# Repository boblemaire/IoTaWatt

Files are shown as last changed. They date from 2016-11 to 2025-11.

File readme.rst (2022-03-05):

=========================================
IoTaWatt WiFi Electricity Monitor Project
=========================================

IoTaWatt is an open-source, open hardware project to produce an accurate, 
inexpensive and easy to use energy monitor.  
It can use any of dozens of common current transformers and
will report the data locally via integrated web server,
or upload to any of several third-party energy websites/data bases.
Configuration and administration is through an easy to 
use browser based utility running on a 
computer, tablet or smartphone.

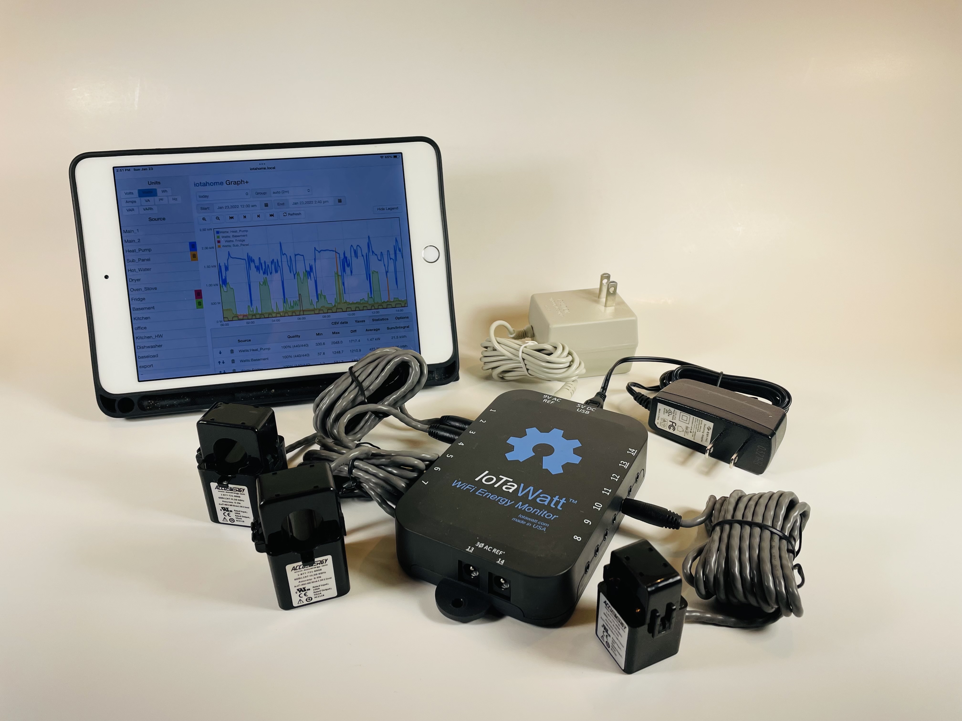
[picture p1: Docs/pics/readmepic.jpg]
**IoTaWatt USA Bundle**


    IoTaWatt North America Bundle with two CTs for Mains

IoTaWatt is a full function standalone energy monitor 
with the capability to store and serve up to 15 years (or more) 
of comprehensive usage data and has an integrated web-server with
visualization apps. 
At the same time it can upload data to any and 
all of several (and counting) web based database and reporting systems.

Hardware is open and uses an ESP8266 nodeMCU,
MCP3208 12 bit ADCs, an RTC, and an SDcard.
The commercially manufactured unit is tested and certified to UL 
standards in the US and Canada, 
CE compliant, and FCC compliant and comes with a
custom enclosure and wall mount.

Metrics accumulated to 5 second resolution are Voltage(V), Power(Watts), 
Energy(kWh), VA, and PF.  While not certified to a standard, 
users typically report accuracy within 1% of their revenue meters.

With over 1,000 units sold worldwide over the past year, 
it's now starting to get the attention of energy professionals.

The software project is not commercial, 
however it was necessary to establish a legal entity (IoTaWatt, Inc.) 
in order to manufacture, certify, and sell the hardware worldwide.  
There is an investment in that 
infrastructure that needs to be recovered through sales. You can
visit the `IoTaWatt Stuff Store <https://stuff.iotawatt.com>`_ to get one. 

The unit is manufactured in the USA.

    *   `Documentation <https://iotawatt.readthedocs.io>`_
    *   `Project Website <https://iotawatt.com>`_
    *   `User Forum <https://community.iotawatt.com>`_

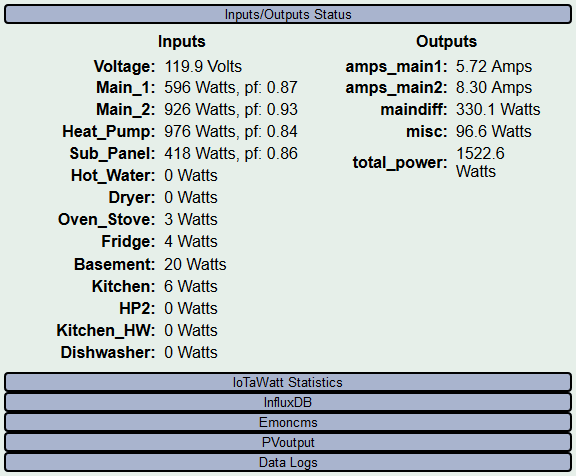
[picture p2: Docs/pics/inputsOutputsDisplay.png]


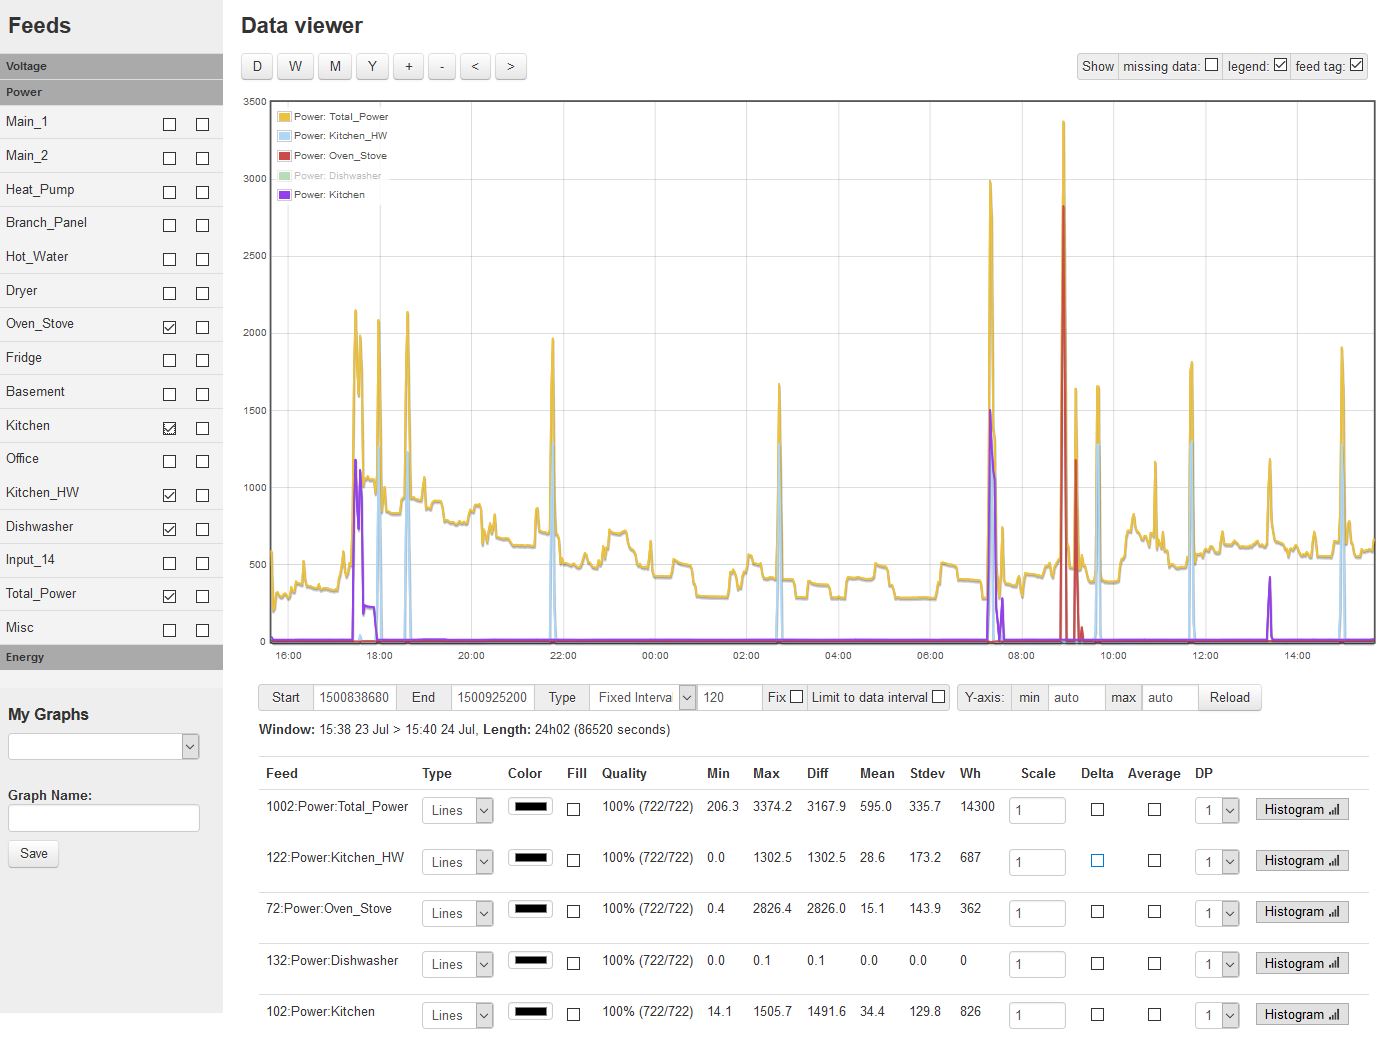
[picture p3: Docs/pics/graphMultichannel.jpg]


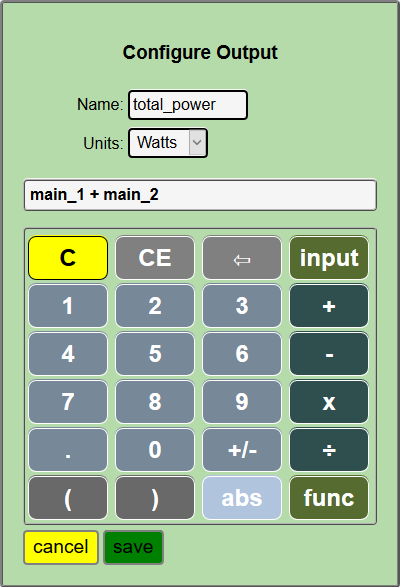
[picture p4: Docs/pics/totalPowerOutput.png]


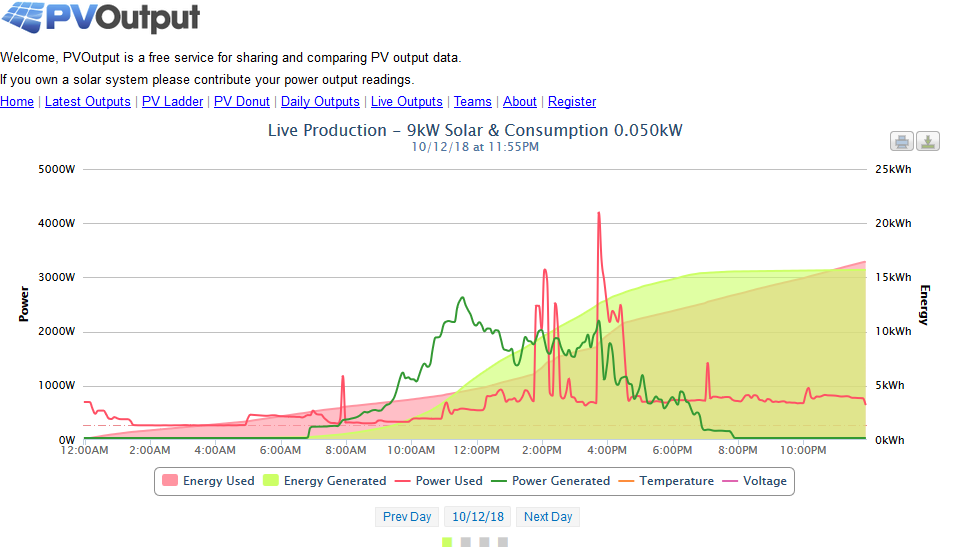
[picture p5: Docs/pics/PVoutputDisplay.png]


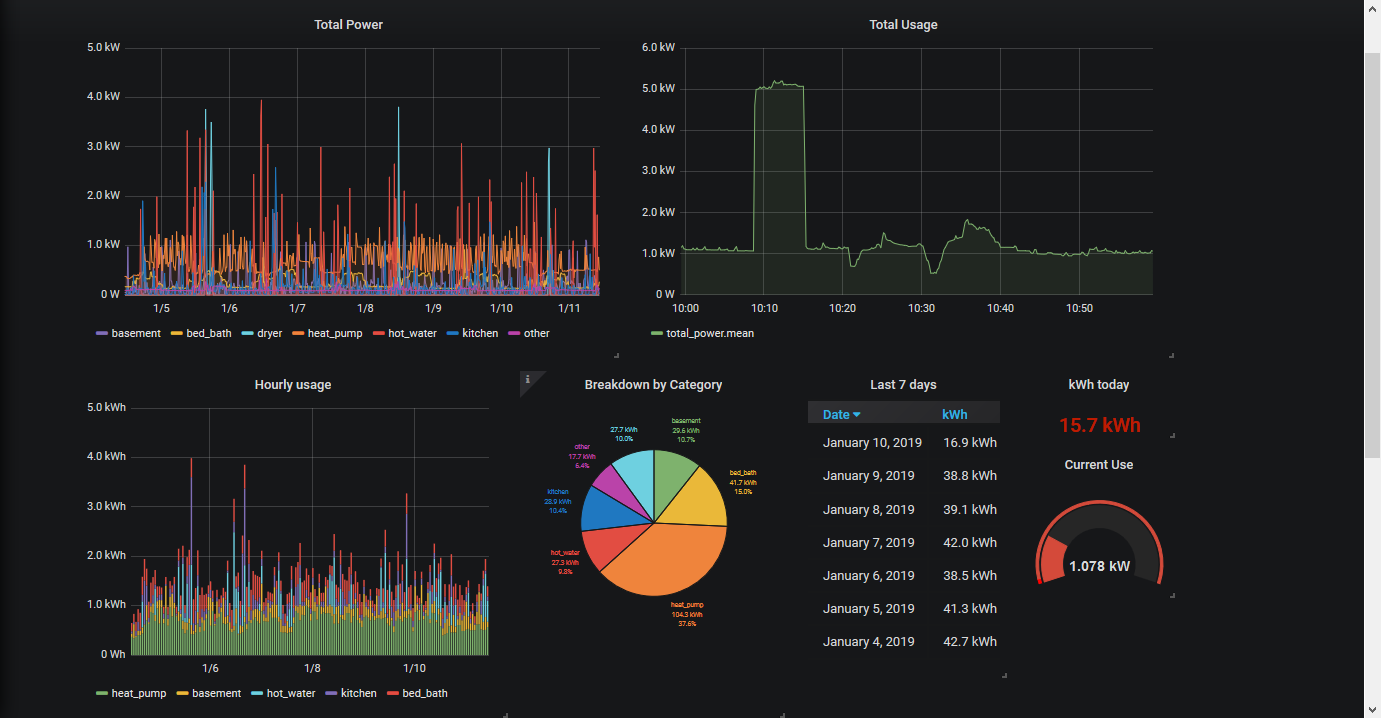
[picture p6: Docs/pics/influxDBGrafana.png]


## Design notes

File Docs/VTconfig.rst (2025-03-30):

=================================
Voltage Transformer Configuration
=================================

A prime component of electrical power is voltage.
The AC line frequency is the heartbeat of the IoTaWatt.
A reliable and accurate AC voltage reference is very important.
You should have installed the device with a 9 Volt AC voltage reference
transformer (VT) plugged into the channel zero power jack.
If your initial configuration has this channel pre-configured,
your LED will be glowing green because it's rhythmically sampling that voltage.

Various transformer models produce different voltages,
and it's important to ensure that the VT specified 
matches the model that you have installed.
To do this, select the inputs button in the Setup dropdown menu.

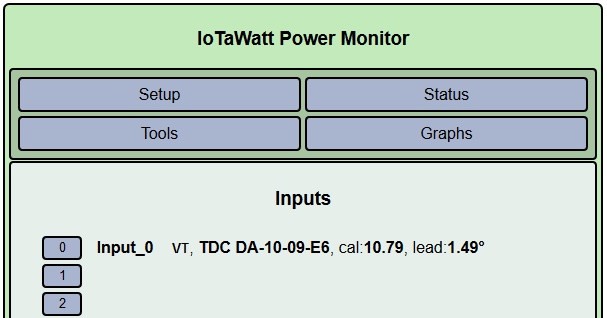
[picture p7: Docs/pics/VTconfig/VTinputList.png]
Setup Inputs List


A list of all of the inputs will be displayed.
The first entry will be input 0 and a default VT should be configured.
Check to see if it's the same as your VT model.
It's OK to unplug the VT to check the model number printed on it.

If your VT model doesn't match the model that is configured, you can easily change it.
Click on the input channel 0 button on the left.

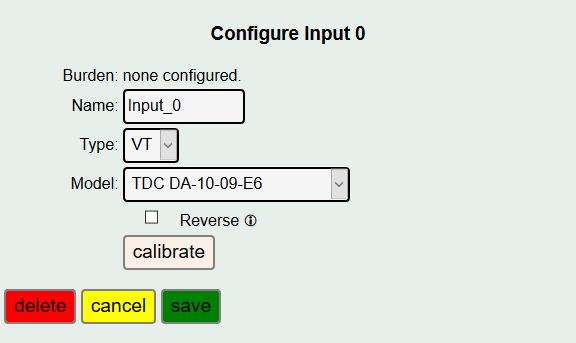
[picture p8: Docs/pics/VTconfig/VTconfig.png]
Configure VT Menu


As you can see, the display changes to reveal the details of the input_0 configuration.

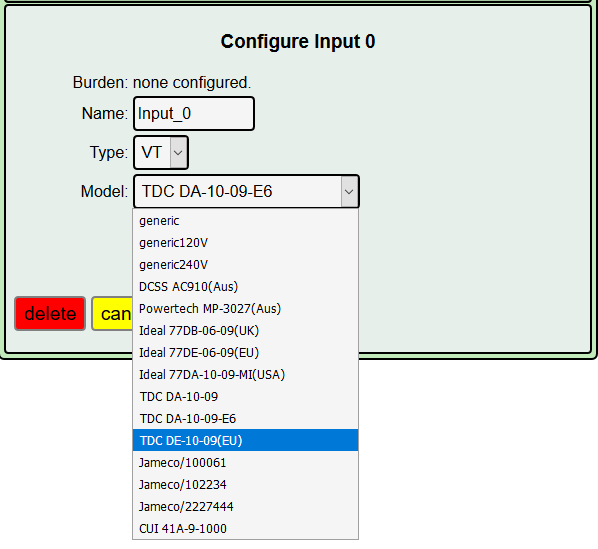
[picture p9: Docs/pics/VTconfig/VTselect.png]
Select VT Image


VT Model Selection
------------------
If your make and model is listed, select it from the list.
At this point, you can just click **Save** and the standard 
calibration for your VT will be used.
That calibration should be good for all but the most discerning users.
If you have access to a good voltmeter or other reliable 
high accuracy voltage reference,
you can fine tune with the calibration procedure below, but for average users,
you should be good to go on to the next step Adding Power Channel CTs

If your VT wasn't listed in the dropdown above,
the generic entry is a reasonable starting point 
that will get you in the ball park for your 9-12Vac adapter.
If your country is 230V or 240V select "generic240V". 
Now you must perform the `Voltage Calibration`_  procedure below.

TDC DA-10-09 model ambiguity
~~~~~~~~~~~~~~~~~~~~~~~~~~~~

There are two different voltage transformers available with the model designation TDC DA-10-09.
These models are quite different and need to be properly configured.

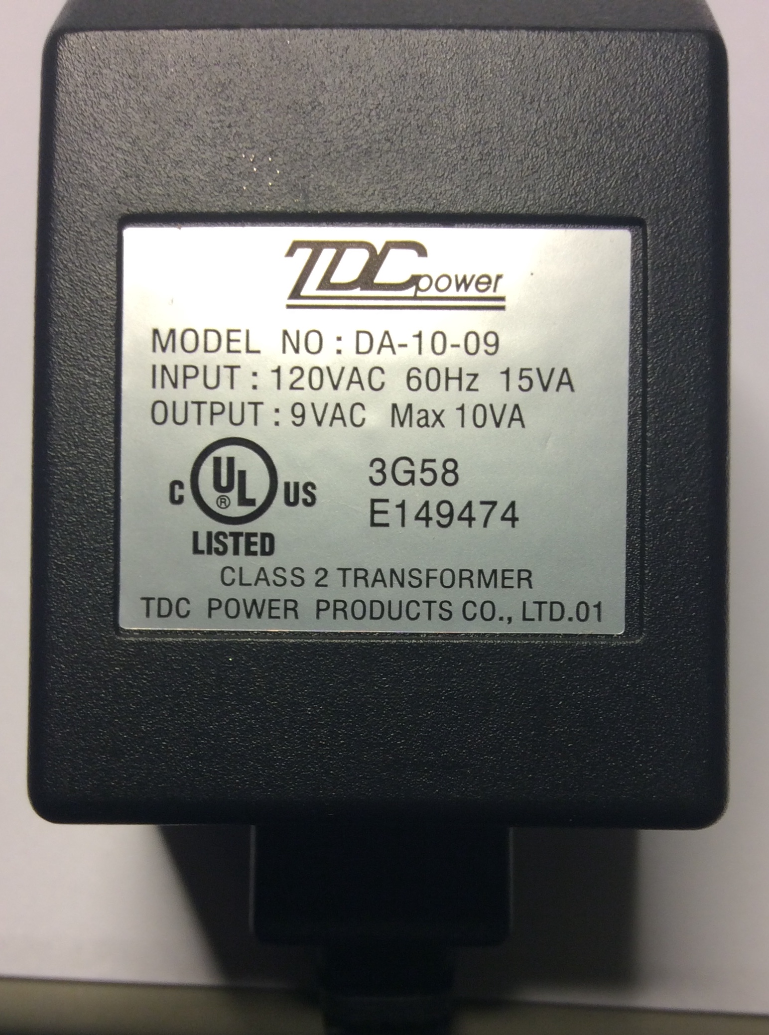
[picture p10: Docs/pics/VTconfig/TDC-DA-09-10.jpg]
TDC DA-10-09


    use model: TDC DA-10-09

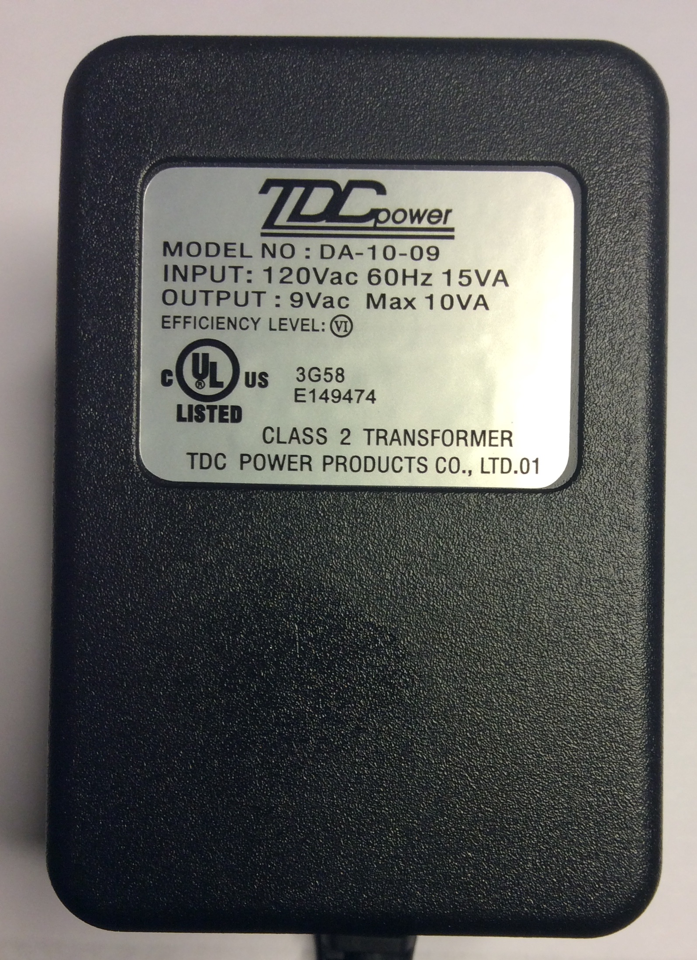
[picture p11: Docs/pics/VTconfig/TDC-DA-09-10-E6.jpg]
TDC DA-10-09-E6


    use model: TDC DA-10-09-E6

Voltage Calibration
-------------------

Again, if you are using one of the standard voltage transformers from
the tables, this step is optional. 
Repeated random tests on the standard US and
Euro transformers yield excellent calibration right out of the box.

You will need a halfway decent voltage reference for this step.
If you don't have a decent true RMS voltmeter and can't borrow one, 
go out and get a Kill-a-Watt.
They cost less than $20 (some libraries lend them out) and 
I've found their voltage readings are usually accurate.

click **Calibrate**

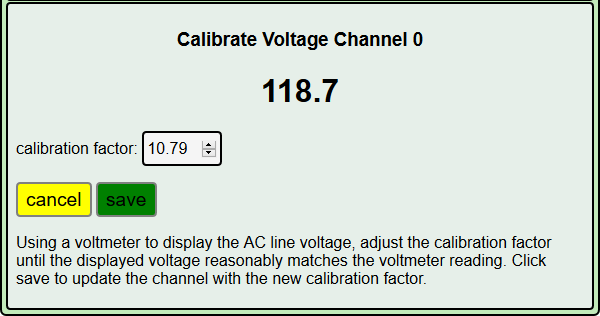
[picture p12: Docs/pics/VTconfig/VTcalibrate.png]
Calibrate VT Menu


Follow the instructions on the page. Increase or decrease the "cal" factor
until the voltage shown settles down and is a pretty 
good match with your reference meter.
It's not possible to match exactly. 0.2V in a 
120V installation is 0.2% variation.
A good meter accuracy is 1% at best. Just try to get the 
two to dwell around the same set of fractional digits.

As instructed on the page, click save to record the calibration factor.
The new calibration factor will take effect immediately.
Click the Status menu button to display the voltage:

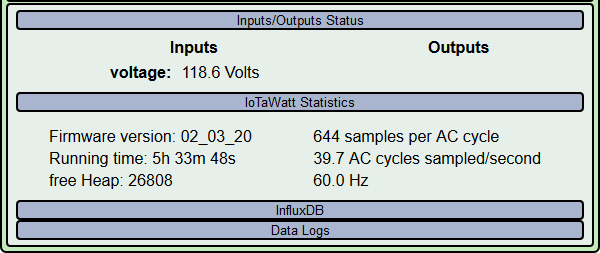
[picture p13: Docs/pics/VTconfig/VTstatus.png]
VT Status


Wait a few seconds then check that the voltage 
displayed is still in the ball park.
If not, repeat the calibration procedure.

Once calibration is complete and verified,
you will not need to do it again unless you change your VT transformer.
The IoTaWatt has a very accurate internal calibration reference and will maintain
its accuracy indefinitely. You should have no further need for the voltmeter.

Now the device is ready for the next 
step `Configuring Power Channel CTs <CTconfig.html>`_





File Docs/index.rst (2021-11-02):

======================
IoTaWatt documentation
======================

..  toctree::
    :maxdepth: 2
    :caption: Contents:

    Quickstart <quickstart>
    Installation <installation>
    Connecting to WiFi <connectWiFi>
    Device Configuration <devConfig>
    VT Configuration <VTconfig>
    CT Configuration <CTconfig>
    Status Display <status>
    Outputs <outputs.rst>
    Integrators <integrators>
    Uploaders <uploaders>
    Configure PVoutput <PVoutput>
    Configure Emoncms <Emoncms>
    Configure influxDB <influxDB>
    Home Assistant <homeAssistant>
    Setting up Passwords <passConfig>
    Three-phase power <threePhase>
    CT Basics <CTbasics>
    Split-phase power <split-phase.rst>
    Data Visualization <dataVisualization>
    Graph+ <graphPlus>
    Original Graph <originalGraph>
    File Manager and Editor <fileManager>
    Query API <query.rst>
    HTTPS Proxy Server <HTTPSproxy.rst>
    Message Log <messageLog>
    Troubleshooting <troubleshooting>
    Accessing iotawatt.local <dotlocal>

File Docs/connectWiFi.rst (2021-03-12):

==================
Connecting to WiFi
==================

Purpose
-------

When IoTaWatt powers up, it attempts to connect to the 
last WiFi network used.
A connection must be established to an internet connected network if the real
time clock is not set, or to run the configuration utility,
or if logging to an external server like Emoncms is desired.
*It is strongly recommended to connect the IoTaWatt to a WiFi network
with a reliable internet connection*.

If the power-up connection is successful, 
the LED will begin to glow dull green.
This indicates that the IoTaWatt has connected 
and is in normal operating mode.
At this point you can skip ahead to the next 
section `Device Configuration <devConfig.html>`__

New connection
--------------

If the IoTaWatt has never been connected to a WiFi network (new),
or the last used network is not available, the ESP8266 will enter
AP (Access Point) mode when powered-up (not on a software restart).
This state is indicated when the LED flashes the 
three color sequence RED-GREEN-GREEN.
It will broadcast an SSID recognizable by the 
prefix ``iota`` followed by a unique number.
Connect to it using a smartphone or tablet.  
Use the password ``IotaWatt`` (case sensitive).
If the device was previously configured and the 
device name was changed,
that new name will be the password required in this step.

After connecting, a page will be rendered with several choices.  Select ``Configure WiFi``.

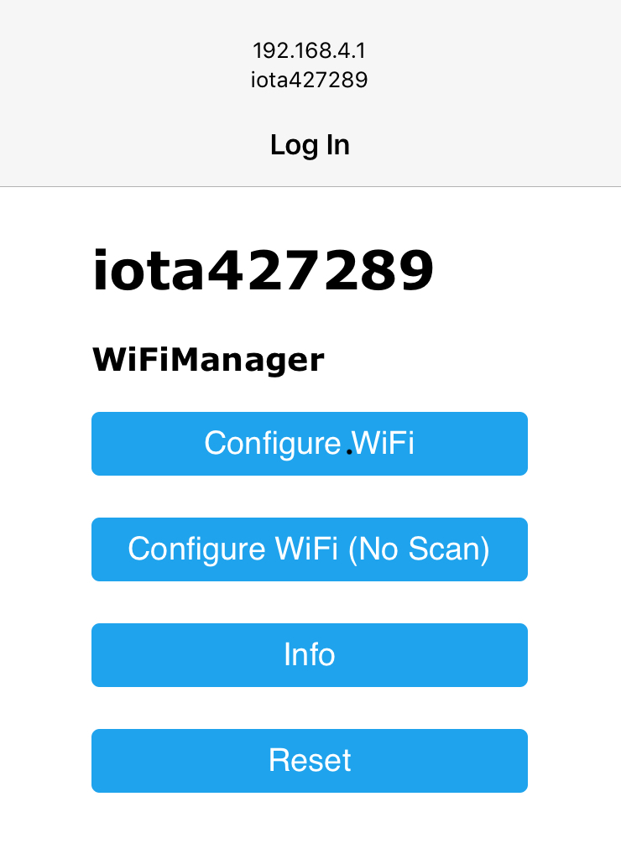
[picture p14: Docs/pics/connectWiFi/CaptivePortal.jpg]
captive portal image


A few seconds may elapse while the IoTaWatt scans for the local networks,
then another page will be rendered allowing you to select one of the listed
networks, or specify another network not listed.

Note that the IotaWatt only supports 2.4 GHz wireless networks. If you have a 5 GHz
only network you can either enable 2.4 GHz on it, or create a separate (optionally hidden)
network on 2.4 GHz for the IotaWatt to use.

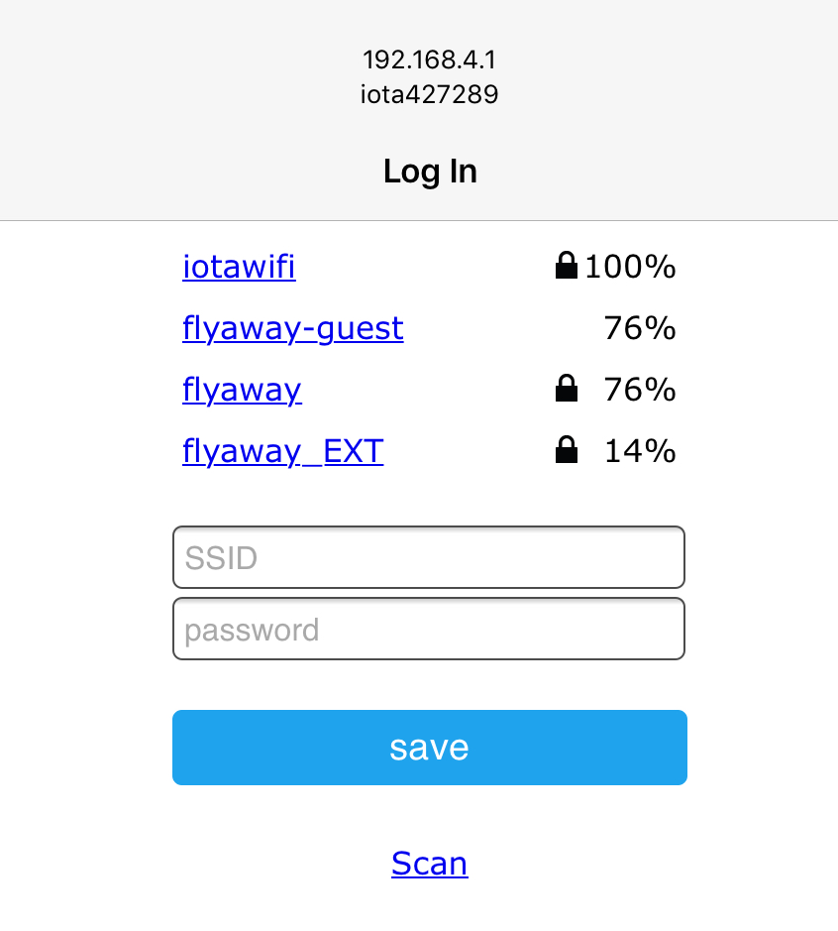
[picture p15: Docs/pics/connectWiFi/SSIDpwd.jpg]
Specify Network image


Select your network and enter the password, then save. Once connected,
the new WiFi network credentials will be saved and the device 
will continue it's
startup procedure.  If you see another LED sequence, refer to 
the `troubleshooting <troubleshooting.html>`__ section.

When the LED glows dull green, proceed to the next step
`Device Configuration  <devConfig.html>`__

Resetting WiFi to Defaults
--------------------------

If you wish to change the WiFi SSID that the IoTaWatt is connected to
(you might have done some testing and want to deploy 'live' somewhere where the SSID is different)
BEFORE moving the device you should reset the WiFi.

Using the configuration app go to ``Tools->WiFi``

Disconnect WiFi image

After the command to disconnect the existing WiFi connection has been sent, 
IoTaWatt will respond "ok" and the LED will change from a dull green to a dull red as the IoTaWatt disconnects,
indicating that the WiFi link has been severed.

Then power cycle the IoTaWatt. It should restart with the RED-GREEN-GREEN led sequence like a new
IoTaWatt ready to connect to the new SSID

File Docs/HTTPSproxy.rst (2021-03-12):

==================
HTTPS Proxy Server
==================

Like many IoT devices, IoTaWatt does not have the resources to communicate
over the internet using secure TLS. While the local LAN can be relatively secure,
data uploaded to internet based servers is transmitted in plaintext and
vulnerable.  One exception is the Emoncms web service where a protocol
to authenticate and encrypt communications is available.

Some external services, such as influxCloud, require TLS (HTTPS) be used
in all communications.  IoTaWatt can use a simple proxy server on the local
LAN to overcome this limitation and forward internet communications using HTTPS.

NGINX (engine-x) is an open-source web-server that can be hosted on a variety
of inexpensive processors.  The ubiquitous RaspberryPi being a simple and 
inexpensive favorite.  Once setup, you only need to set the URL of the 
proxy server into IoTaWatt, and it will be used to communicate with any
uploader where the URL of the service is specified as HTTPS:// method.

Setup up NGINX on a RPi
-------------------------

Rather than reinvent the wheel, this section will lean heavily on existing webtutorials to
setup a RPi based NGINX proxy.  Many will already have an RPi or other Linux based
resource on their LAN and can host NGINX there.

An RPi 3 Model B or better is recommended. With a case, SDcard and power supply the cost 
is usually less than $50 US. There are many tutorials for setting up the Basic RPi
with the latest software release.  Rather than post a link that may get stale, 
I'll leave it to the reader to search the internet for one that suits their
capabilities.

Once the basic system is up and running, it's easy to add NGINX.  Simply follow this tutorial_
from the RaspberryPi folks.

.. _tutorial: https://www.raspberrypi.org/documentation/remote-access/web-server/nginx.md

Add the HTTPSproxy location
------------------------------

Whether you decided to setup a RPi with NGINX or you installed NGINX on another platform,
all that is left is to add the Location configuration for the HTTPS proxy.

Download the HTTPSproxy location from the IoTaWatt
server to the NGINX configuration using the command:

    ``sudo wget -P /etc/nginx/sites-enabled https://iotawatt.com/download/HTTPSproxy``

Then reload the NGINX configuration using the command:

    ``sudo nginx -s reload``

Configure the proxy in IoTaWatt
-------------------------------

Using a fixed IP address for the NGINX host, setup it's address in IoTaWatt.
Select |setup| then  from the dropdown.
Add the URL with port :9000 and press **Setup button**.







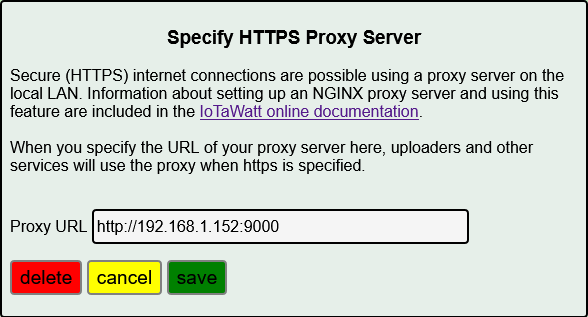
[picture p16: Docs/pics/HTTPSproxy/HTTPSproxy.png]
**HTTPSproxy Setup**


Using the HTTPS proxy
---------------------

Once the HTTPS proxy address is specified, using it is easy.
PVoutput will automatically start to use HTTPS.
For influx or Emoncms uploaders, simply change the server
URL method to HTTPS://.

**server URL example**

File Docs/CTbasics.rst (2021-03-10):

=========
CT Basics
=========

What is a Current Transformer?
------------------------------

`From Wikipedia <https://en.wikipedia.org/wiki/Current_transformer>`_:

    *A current transformer (CT) is a type of transformer that 
    is used to measure alternating current (AC). 
    It produces a current in its secondary which is 
    proportional to the current in its primary.* 

In our case, the primary is *one* of the conductors of the circuit
that we want to measure, and the secondary is the output jack
that plugs into the IoTaWatt.

So without connecting anything directly to any high-voltage
wiring, it's possible to get a scaled down measure of the
primary current that can be used to passively measure power 
(Watts) of a circuit.

Types of CTs
------------

CTs come in various types, sizes, and capacities, 
and are made for a variety of end uses. This tutorial
doesn't try to address all aspects.  That's what
Wikipedia does well.  Here we'll try to focus on the
CTs that are suited to use with the IoTaWatt in typical
scenarios.

Physically, a CT needs to have an iron core through
which one or more primary conductors pass. The most basic
type is a solid-core CT, where an iron doughnut is wrapped 
with turns of wire. This type of CT is relatively inexpensive,
typically very accurate, but requires that the primary
conductor be disconnected and reconnected to install, thus
exposing the installer to high-voltage and disrupting the
primary circuit.

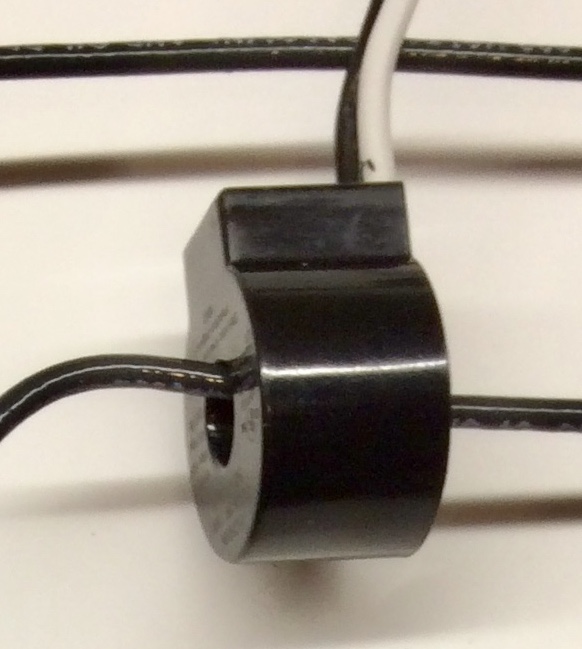
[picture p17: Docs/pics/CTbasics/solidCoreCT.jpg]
Solid Core CT


    Solid Core CT

Split-core CTs also require an iron core around the primary,
but do so using two hinged halves that mate to form the continuous
iron loop. This type of CT can be installed by simply snapping
the two halves over an active primary conductor.

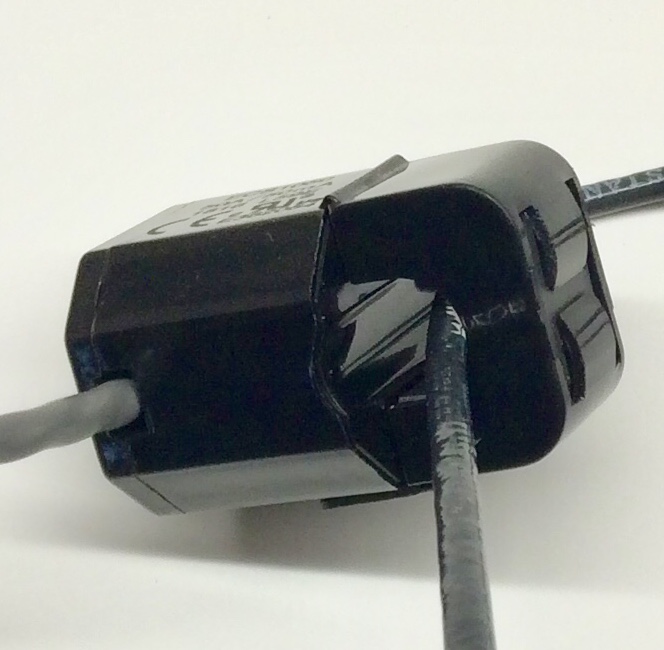
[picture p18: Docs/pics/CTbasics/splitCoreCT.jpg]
Split Core CT


    Split Core CT

Installation
------------

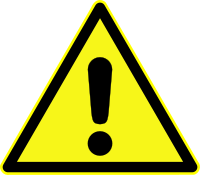
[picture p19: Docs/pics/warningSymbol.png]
**Warning!**


*The installation of CTs can be dangerous and/or
cause hazardous situations resulting serious injury or death.
Worldwide, there are a variety of electrical conventions, regulations 
and standards.  It is the user's responsibility to insure that the 
installer is qualified and all local codes and regulations are followed.*

To measure the current in a circuit, a CT is installed on one, and 
only one, of the conductors in a circuit. Either the conductor is
passed through the solid-core, or the split-core is clamped over it.

CTs must have a load.  Without a load, they will develop very 
high voltages that can damage the core windings and/or 
create a safety hazard. When plugged into the IoTaWatt, the
secondary windings are loaded by a *burden resistor*.

Some CTs have protective diodes, called TVS diodes, that will 
protect against damage when unplugged for short periods.  Even if
a diode protected CT is to be unplugged for an extended length 
of time where the primary is energized, the CT should be removed 
or shorted.  Shorting will not damage the CT.

Polarity
--------

CTs are manufactured to produce a secondary current that is in 
phase with the primary current when installed with a particular 
orientation. In single and split-phase installations it is
important to observe polarity in certain situations.  In
three-phase installations, it is imperitive that a polarity 
convention be observed.

IoTaWatt will accept many different CTs from different manufacturers.
While most have some type of markings that can be used as a 
reference for polarity, there is no universal standard.  Typically,
CTs from the same manufacturer will be consistent with respect to source 
and load indicators.

And so it is for the Echun and AccuEnergy CTs that IoTaWatt, Inc makes available. 
When installing, we use the notion of a *source* and a *load*.
The source can be conceptualized as *where the power comes from* 
and the load as *where the power goes*.

So for the mains, or incoming power to a service, the *source* would 
be the meter side, or incoming power feed.  The *load* would be the 
main circuit breaker or fuse side.

For branch circuits, it would be just the opposite.  The *source* would
be the circuit-breaker side, and the *load* would be the appliance side.

For a solar inverter connection, the *source* would be the inverter side, 
and the *load* would be the circuit-breaker or other point of
interconnect.

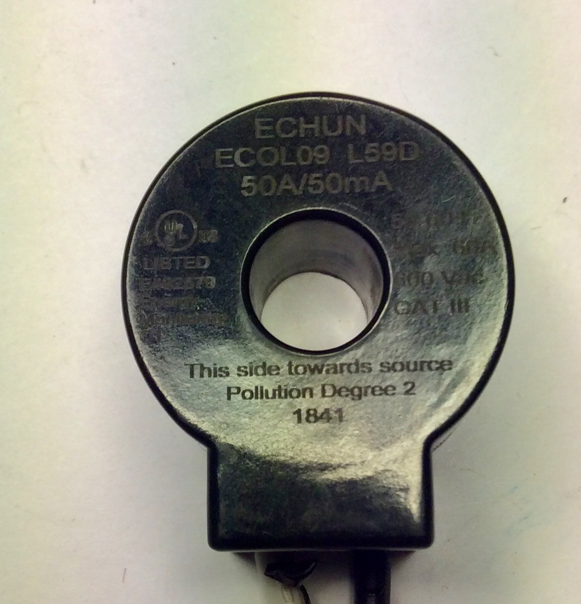
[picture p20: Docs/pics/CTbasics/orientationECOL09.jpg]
ECOL09


    Here you can plainly see "This side toward source"

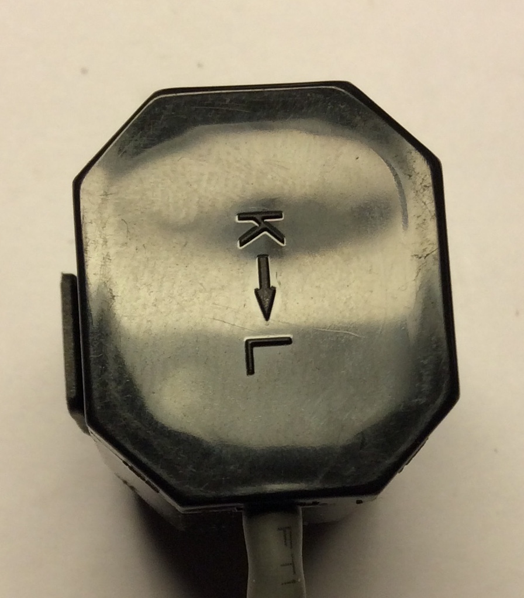
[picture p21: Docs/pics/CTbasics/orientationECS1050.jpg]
ECS1050


    Here the arrow points source(K)->load(L)

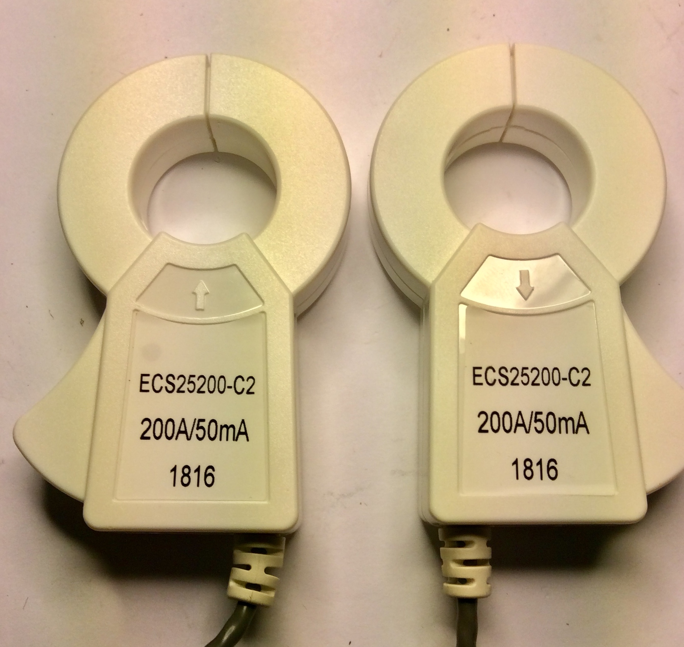
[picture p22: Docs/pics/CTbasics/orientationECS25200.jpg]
ECS25200


    This is an Echun ECS25200 clamp type CT
    used for 200A mains. Both sides are shown.
    Note the arrows just under the opening.
    The arrow pointing up to the opening
    indicates the source side, and the down
    arrow indicates the load side.

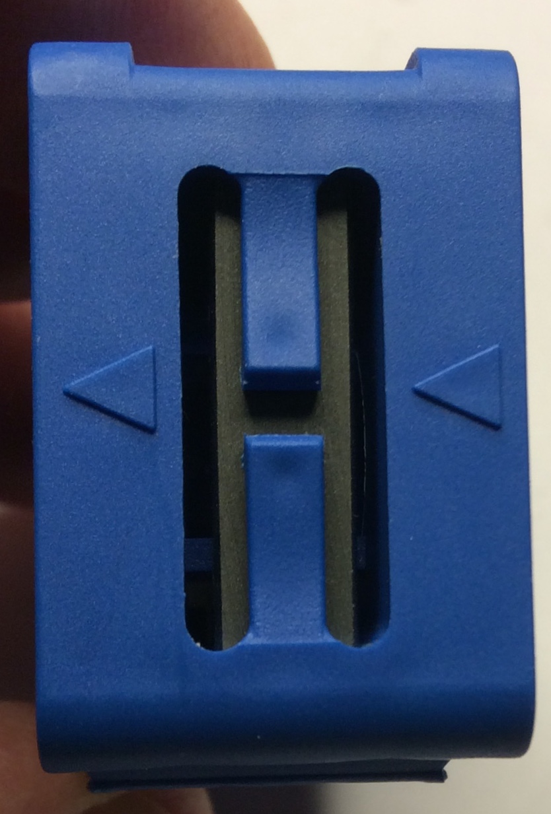
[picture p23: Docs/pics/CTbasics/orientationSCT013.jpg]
SCT013


    This is the common SCT013 CT.  If you are using
    them exclusively, the arrow can be aligned consistently
    as source to load.  But note that if using with 
    the Echun CTs, they must be installed with the
    arrow pointing from load to source.  This isn't
    a fault of either manufacturer.  It just reflects
    the lack of a standard for how to connect the
    CT secondary to the 3.5mm jack used to connect.

Single and three-phase systems
------------------------------

All of the CTs in single or three-phase systems should
be installed identically with respect to load and 
source.  This is especially important when configuring 
three-phase systems using the 
`Derived Three-phase <threePhase.html>`_ method.

Split-phase systems
-------------------

Most of North America and some Asian countries use 
a split-phase power system with dual voltage, typically 
120/240V.  With this power system, there are two mains 
with exact opposite phase. The voltage between either
main and neutral is 120V, while the voltage between 
the two mains is 240V.  This provides an advantage of 
the relative safety of lower voltage in small appliance
outlets, while still providing high voltage for 
workhorse appliances like water-heaters, ranges, 
and clothes dryers.

In these systems, while possible to use two voltage references,
typical IoTaWatt installations use a single reference
that reflects the phase and voltage of one of the sides, 
or *legs* as they are commonly called. The result is that 
CTs on the other leg should be oriented  the opposite way to
be in phase with the opposite voltage reference. For simple singlephase 120V
(or 230V European type) circuits, IoTaWatt will automatically correct
reversed CTs and report positive power unless "Allow negative values" is
enabled in setup for that CT.

There is more to installing CTs on 240V circuits in split-phase 
systems in the next chapter.

240V Split-phase circuits
-------------------------

As explained above, split-phase systems can provide 
high-voltage for large appliances. These circuits are connected 
to two adjascent CTs that are on different legs.  The usual
convention is to use RED and BLACK wires or, as explained below, 
BLACK and WHITE for *pure* 240V circuits.

240V only
^^^^^^^^^

When I say *pure* 240V circuits, I mean circuits that are 
usually a single load, and do not have a third neutral wire 
to use either leg independently for 120V.  Examples of *pure* 240V 
circuits would be a resistive water-heater, well-pump and 
baseboard electric heater. What these circuits will have in common
is that they don't have a neutral wire, and usually use two 
conductor with ground BLACK and WHITE leads.

With these circuits, you can place the CT on just one of the
conductors, and check the *double* box in input configuration, 
directing IoTaWatt to double the voltage value to report 
correct power and amperage.

120/240V circuits
^^^^^^^^^^^^^^^^^

Like the *pure* 240V circuits above, these circuits use two 
adjascent circuit-breakers, but also have a neutral conductor. 
They usually have RED and BLACK conductors on the circuit-breaker 
and a white neutral conductor that connects to the neutral bussbar. 
Typical appliances are ranges, ovens, and clothes-dryers.  Circuits
feeding sub-panels are usually of this type as well.

For these circuits, the two legs must be measured individually 
because the current in each is not always the same.  There are a couple 
of ways to do this.

The easiest way is to pass both the RED and BLACK conductors through 
the CT.  A CT will measure the total current of all of the conductors 
that pass through the primary.  But there is a twist.  The phase of 
the current in each conductor is exactly opposite the other, so they 
will cancel each other out. Rather than get the sum of the two,
you get the difference between the two.

The solution is to pass one conductor through in the opposite direction 
to the other.  There is a common trick for this.  In many panels,
the conductors are brought past the CT in a U shape so that there is
some excess wire in case the circuit needs to be moved within the panel. 
You can use this U configuration to easily reverse one of the conductors.
In this case, the CT needs to handle the combined capacity of the two 
circuit breakers when added together.  
A 50A CT can probably be used up to about a 2x30A breaker.

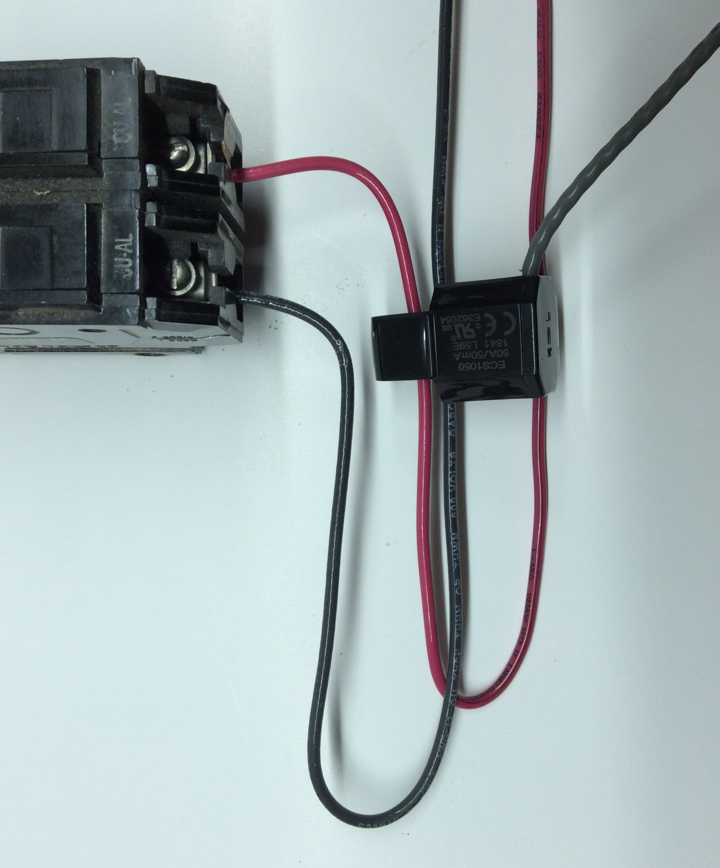
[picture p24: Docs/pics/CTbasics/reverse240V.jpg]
Reversed CT conductors


    The CT is clamped around the RED wire going down and 
    the BLACK wire going up.

An alternate method, and recommended with high amperage 
sub-panel circuits, is to put a separate CT on each leg. 
The CTs can be connected to two individual IoTaWatt inputs 
and added together later for the total.  With this method, 
each of the two CTs only need match the capacity of one of 
the circuit breakers.

Two individual CTs can also be combined with a common headphone
splitter and fed into a single IotaWatt input. When combining 
this way, both CTs must be the same model with an individual 
capacity sufficient to measure the combined capacity of the two 
circuit breakers.

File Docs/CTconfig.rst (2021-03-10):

================================
Configuring Power Channels (CTs)
================================

What is a power channel?
------------------------

Power channels measure the current flow through a circuit and 
combine that with the reference voltage to determine power, 
expressed in watts, and to accumulate energy used, expressed in watt-hours.  
Current through a circuit is measured indirectly by installing a passive 
sensor, called a *current transformer* (CT), around one of the conductors 
in the circuit. 
CTs come in a various capacities, physical connection type, and electrical output.  

The good news is that IoTaWatt supports a wide variety of readily available 
CTs, and many can be configured simply by selecting the model from a list. 
CTs are connected with 3.5mm stereo jacks (headphone jacks). 
The CTs that are sold at the `IoTaWatt stuff store <http://stuff.iotawatt.com>`_  
are manufactured with 3.5mm jacks.  

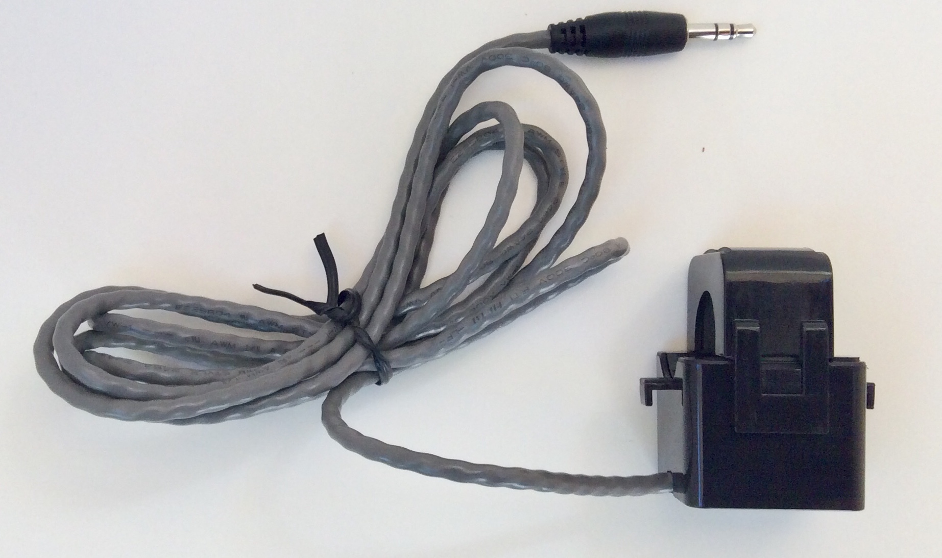
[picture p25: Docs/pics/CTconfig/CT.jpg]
Echun ECS16-100


    Echun ECS16-100 CT

Connecting the CTs
------------------

This tutorial does not cover physical installation of the CTs to your 
electrical circuits. That should be done by someone familiar with 
electrical wiring. Your qualified installer will know how to do this. 
The 3.5mm connectors plug into any of the 14 input channels on the IotaWatt.

The only additional recommendation is that all of the CTs be oriented 
the same way with respect to current flow.  
Most CTs have an arrow or other marking to aid in consistent orientation. 
Not to worry, in the event some end up backward, IoTaWatt will still work, 
will tell you which ones appear to be backward, and provides a way to correct virtually.

You can find more detailed information about physical installation of CTs 
in the `CT Basics <CTbasics.html>`_ section.

Configuring the Input Channels
------------------------------

At this point, you should have the IoTaWatt up and running with the voltage 
channel connected, configured, and calibrated if necessary. 
You are using the config app in a browser connected to your WiFi network.  
Hover over **Setup button** and click |inputs| in the dropdown buttons.

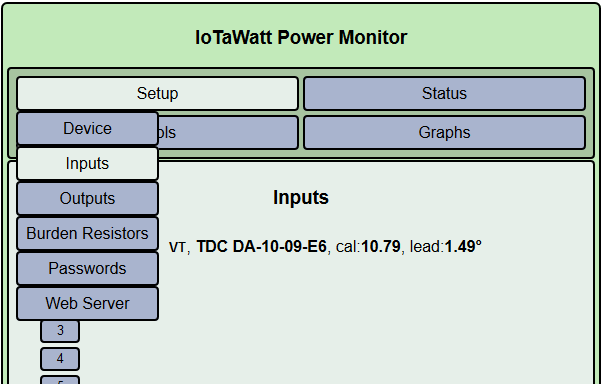
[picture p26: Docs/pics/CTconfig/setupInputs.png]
Setup Inputs List


This screen should look familiar. We came here to configure the voltage 
transformer (VT). Now we will configure current transformers (CTs) to other 
inputs. To add or edit the CT specification for an input channel, 
click the channel's number button. Let's add a CT to channel **Input 1 button**.

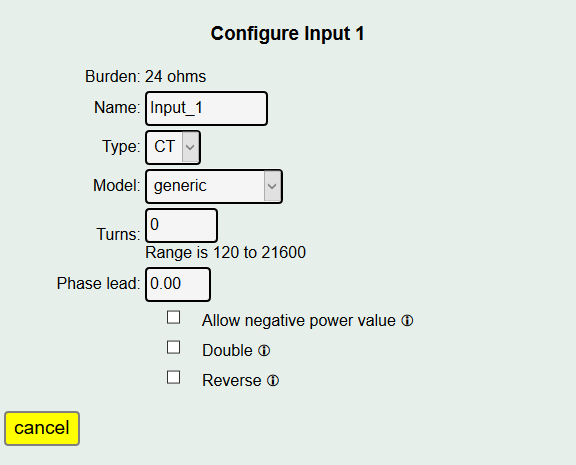
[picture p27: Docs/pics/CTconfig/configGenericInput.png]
Config Generic CT


The app enters channel edit mode. Here you specify the model and other 
details about the CT connected to this particular channel.  
But first, it is helpful to name the channel by typing a name in the 
name box. You can just use the default "Input_1" or something more 
meaningful like "Kitchen" or "Living Room" or "Main". 
We will configure one of our US 120/240V split-phase mains
as **main_1**.

The default type is **CT** and that's correct.

The next drop-down box is the model of the CT.  
Initially it will be `generic`, 
Click the drop-down list and select the **ECS24200** CT.  

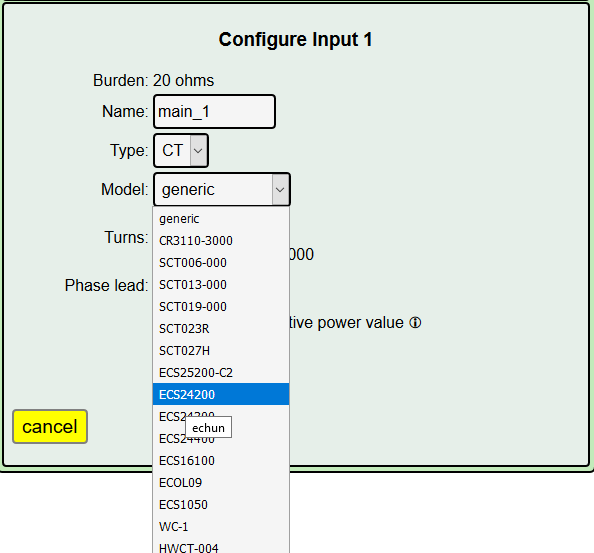
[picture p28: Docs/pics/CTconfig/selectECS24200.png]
Select ECS24200 CT


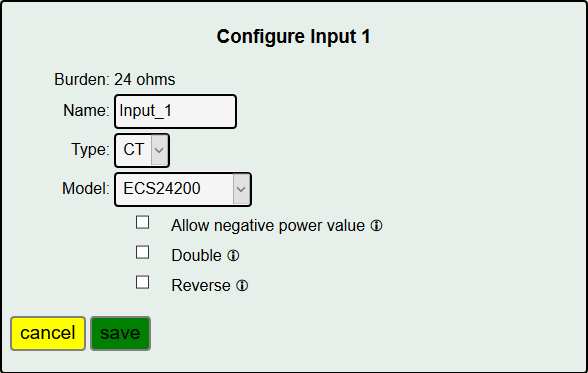
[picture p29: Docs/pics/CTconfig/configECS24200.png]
Config ECS24200 CT


Notice that after selecting a specific device from the table, 
the input fields for "turns" and "phase" disappear.  
That's because those values are known for the listed CTs.  
If you have a CT that is not found in the list, 
you will need specify the "generic" entry and 
provide the turns-ratio and phase-lead for that CT.
see `generic CT`_ below.

There are check-boxes to further configure the CT.  
Most of the time, these will not be used, but there are circumstances 
where you would check one or more of them. If you hover on the **!** 
next to each, a brief description will appear. They are explained below:

**Allow negative power value**
    This is typically checked only for mains in an installation with 
    grid-tied solar (net-metering).  Checking this box tells IoTaWatt 
    that it is normal for current to flow backward through this circuit, 
    as when a PV system creates more power than you are using locally 
    and the balance is "exported" to the grid.  When you check this 
    box you are affirming that the CT is installed correctly and that 
    negative power should not be automatically "corrected" to positive.

**Double**
    In North American split-phase power systems (120V/240V), 
    all circuits are assumed to be 120V.  When this option is selected, 
    power will be computed using double the value of the
    reference voltage, or nominally 240V. 
    Use this for 240V circuits where one CT has been applied to one 
    of the conductors and there is no neutral (white) wire used by the 
    appliance. Typical circuits would be Water Heater, Water Pump, 
    Mini-Split Heat-Pump. There are other ways to monitor 
    240V circuits as well.

**Reverse**
    Sometimes a CT is installed backwards with respect to normal 
    current flow.  
    IoTaWatt will sense this and correct automatically in single-phase 
    power systems. It will correct the negative value automatically and 
    indicate so in the status display with a little ↺ symbol. Selecting 
    this option will virtually reverse the CT as if it were oriented 
    correctly, obviating the need to physically reverse it.
    Doing so can be safer and/or easier, especially with solid core CTs. 
    While merely convenient for single-phase systems, correct orientation 
    is a necessity in three-phase installations because the IoTaWatt 
    cannot automatically sense a reversed CT and correct for it.

Press **Save** to finish.

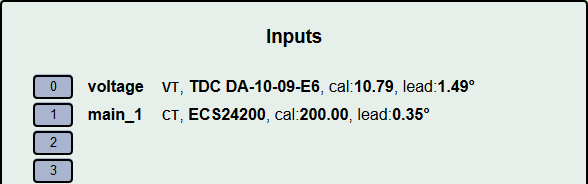
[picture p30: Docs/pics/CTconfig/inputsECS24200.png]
Inputs List w/ECS24200


That's it.  The screen returns to the complete list of inputs where you 
can add more channels or change the configuration of existing inputs. 
Each time you press save, the new configuration is sent to IoTaWatt 
and the changes take effect immediately. If the CTs are installed 
and connected, you will can see the power displayed in the 
Input Channel `Status screen <status.html>`_.

When you have configured all of the CTs connected to the IoTaWatt, 
basic configuration is complete.
Click the **Status button** button to see the IoTaWatt in action.

The following additional information may provide guidance for more advanced installations.

Generic CT
----------

We just configured a *Current Type* CT that was of a model known to 
IoTaWatt. If your particular CT is not one of the dropdown models, 
you will need to describe the **generic** parameters. 
You will recall that this is the initial model designation for a 
CT when a new channel is added. Its also a drop-down choice when 
editing a CT channel. With this model selected, 
you must specify additional information depending on the type of CT:

Current Type CT
~~~~~~~~~~~~~~~

Current type CTs are the most common type of CT used with IoTaWatt and
all of the CTs available in the IoTaWatt *Stuff* Store are of this type. 
They are typically described by the ratio of the maximum primary current 
that they can measure and the corresponding secondary current 
that will be produced, as in 200A:50mA. For these CTs, 
you will be asked to specify the "Turns:".  
This is the ratio of primary current/secondary current.  
So that 100A:50mA described above would be 100/.050 = 2000 turns.

Voltage Type CT
~~~~~~~~~~~~~~~

Voltage type CTs are typically described with an output in volts (V) and  
have an internal burden resistor that causes them to produce an output 
voltage rather than current.  They are connected to a modified IoTaWatt 
input that has had the internal burden resistor removed and specified as zero 
in the device configuration burden menu.  IoTaWatt will ask for a **Cal** 
factor. This is the primary current in amps that corresponds to 1 volt 
of output from the CT. An example of this is the SCT013-050 from YHDC.  
It is marked 50A/1V, so the **Cal** is 50.  Simple enough.

Phase
~~~~~

Both of the generic CT types above will also provide a place to specify 
**Phase**. Representative samples of the CTs in the model list have been 
tested to determine a phase correction value to compensate for phase 
shift of the transformer. If you have a generic CT a rule of thumb 
would be to use 2.0 for a split core CT (one that snaps onto a wire), 
and 0.2 for solid core CTs (Basically a solid doughnut that you pass 
the conductor through).

Enable derived three-phase
--------------------------

This checkbox enables advanced features used to configure inputs in a 
three-phase power system. Refer to the 
section `Three Phase Power <threePhase.html>`_ for more information.











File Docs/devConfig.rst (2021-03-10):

Device Configuration
====================

Successful startup will be indicated by a dull green glow on the LED.
If the LED is off, or blinking a sequence,
see the `troubleshooting <troubleshooting.html>`_ section.

After successful startup, you can connect to the device with your 
web browser to access the configuration app. 
Use the url: ``http://iotawatt.local`` or, if your device
has been renamed, use ``http://<newname>.local``. The configuration app starts with a row of buttons:

Main Menu image

Hover over **Setup button** and click **Device Button** in the dropdown menu.

Config Device image

Device name
-----------

You can change the ``Device name`` to another 8 character name if you wish.
If you have more than one IoTaWatt you will need to do this so that they
each have unique names. When you press save, the IoTaWatt will restart using
the new name. From then on, ``http://<newname>.local`` will be the url
that you will use to access the device from your browser, and the new 
``Device name`` will be the password that you must use to 
connect to the AP if configuring for a different WiFi network.

TimeZone
--------

Set your local Time Zone relative to UTC time. 
All of the measurements are time stamped using UTC, 
but `log messages <messageLog.html>`_ and various reporting apps 
will use this offset to show the data in local time.

If your time zone is subject to "Daylight Saving Time", 
check the ``Allow Daylight Time`` box.
IoTaWatt has DST rules for most of North America, Europe, Australia and New Zealand.

Auto-update Class
----------------- 

Auto-update Class tells IotaWatt if you want to receive 
automatic updates of the firmware and what type of updates 
you are interested in. The choices are:

    :NONE:
        Do not Auto-update this device.
    :MAJOR:
        Only update major releases of the software.
    :MINOR:
        Update with minor releases. More frequent 
        but somewhat tested firmware. This is recommended.
    :BETA:
        Latest production firmware.
    :ALPHA:
        Recently released firmware with the latest features - 
        and the latest bugs.

IotaWatt checks the IotaWatt.com site for new software regularly.
The update process takes less than a minute.
New firmware is authenticated with a digital signature from IotaWatt and installed automatically.

Save
~~~~

Click **Save**. Your changes will be saved. 
If you changed the name of your device,
it will restart when you press save and you will need to 
restart the configuration application from ``http://<newname>.local``.

The next step is `VT Configuration <VTconfig.html>`__







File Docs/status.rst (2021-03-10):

=====================
Device Status Display
=====================

Overview
--------

The configuration app can provide a continuously 
updating display of many aspects of IoTaWatt operation.  
The output is organized into expandable tabs containing 
various categories of information. 
Simply click the **Status button** button.



Status Display

The initial display will always have the Inputs/Outputs Status tab expanded.  
Simply clicking on that tab, or any of the other tabs, 
will toggle them between expanded and collapsed. 
The various tabs as of this writing are detailed as follows:

Inputs/Outputs
--------------

Inputs/Outputs Display

This tab lists all of the configured input channels on the left, 
and all of the defined outputs on the right. 
Both columns show the current measurement value. 
Input channels values are in Watts or Volts for CT and VT 
channels respectively.  
CT channels also will display the power-factor (PF) 
when the power is sufficient to develop that reliably.
Output channel values are in the units configured.  
They may be Volts, Watts, Amps, VA, Hz, or PF.
All values are damped, which is to say they are averaged 
with an exponential decay 
algorithm so that they will not jump around excessively.  
That said, the algorithm does respond to large changes quickly and 
settles in on small changes within a few seconds.

Statistics
----------

Statistics Display

The statistics tab provides insight into the current operation of the 
IoTaWatt with the following information:
    
    * **Firmware version:** Release of IoTaWatt firmware.
    * **Running Time:** Since last restart.
    * **free Heap:** An indication of the working memory 
      available to the firmware.
    * **Samples per AC cycle:** Average samples IoTaWatt is 
      achieving when sampling a channel.
    * **AC cycles sampled/second:** Average number of channels 
      that are measured per second.
    * **Hz:** Current AC frequency.

Web Servers
-----------

Web Servers Display

These tabs appear when `data upload <webServer.html>`_ to PVoutput, 
Emoncms, influxDB has been configured.  
They indicate the state of the services that are responsible for 
sending the data to the respective server.

    **Start/Stop button:**  Use to pause and resume uploading data.
    This button works asynchronously, and may take awhile 
    to perform the action. Pressing multiple time may cause 
    it to go out of sync.  Use it carefully.

    **Running/Stopped:** The current state of the service.

    **Last Update:** Data/time of the last data sent to the server.

Data Logs
---------

Data Logs Display

This tab displays the date/time of the first and last entry 
in both the Current Log and the History Log.  
These dates may take a few seconds to become accurate as the IoTaWatt starts. 
The History Log should begin from the data/time when the 
IoTaWatt was first installed, 
or when the History log was last created after being deleted.  
It should increment every minute while the unit is running.

The Current Log contains up to a year's worth of data, 
and maintains that data at 5 second resolution.  
When the approximate year capacity is reached, it will "wrap" back around 
and begin writing over the oldest entries.  
Newer logs will show the same start date as the History Log.  
As the log ages and reaches capacity, the start date/time 
will advance at 5 second intervals along with the 
ending date/time.

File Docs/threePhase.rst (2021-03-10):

=============================
Three-phase Power
=============================

IoTaWatt has the capability to measure power in polyphase systems. 
In the interest of keeping the user interface simple for the majority 
of users who have single phase power, the details are disguised and/or hidden
until needed. There has been a lot of interest in using IoTaWatt
for three-phase monitoring, particularly in three phase countries like
Australia and Germany. For home energy monitoring, the *derived reference*
method has been overwhelmingly popular.

This chapter explains two methods for measuring a so calld "four wire"
or "wye" system, by far the most common implementation of three-phase.
IoTaWatt can also be used with "three wire" or "delta" systems using 
different methods.

As explained in the introductory single phase section, 
a voltage reference is needed to measure real power. 
The challenge with three-phase power is to obtain 
three different voltage/phase reference signals. 
IoTaWatt can do this by two different methods: 

    **Derived Reference** uses a single voltage transformer 
    and *derives* a reference voltage/phase for the other two 
    phases by numerically shifting the phase of the single 
    reference by 120° or 240°. The primary advantage is 
    low cost and convenience of installation. 
    The disadvantage is that large variations in voltage 
    between phases may result in decreased accuracy.

    **Direct Reference** uses three discrete voltage transformers 
    or VTs, each one plugged into a circuit on a different phase. 
    The primary advantage is voltage accuracy, while the 
    disadvantages are that the extra VTs add cost, use 
    two of the 14 inputs for the additional VTs, and require plugs on each phase 
    in proximity to the IoTaWatt.
    
Configuring Derived Reference
-----------------------------

Derived reference uses a single voltage reference VT and `derives`
the other two signals by phase-shifting. 
While not as exact as direct reference, it produces very good results 
and is the overwhelming choice of residential three-phase users.

This chapter explains how to configure IoTaWatt to 
use "Derived Reference". A word of caution:

    *There are 36 different combinations of CT orientation
    and phase assignment.  Only one of them is correct.  This simple 
    procedure, when followed methodically, will avoid the common pitfalls suffered
    by those who try to stumble on the solution.*

Start by getting the mains installed and configured correctly.  Everything will
fall together from there.

Install and Configure the CTs
^^^^^^^^^^^^^^^^^^^^^^^^^^^^^

Install the three mains CTs on the incoming three-phase 
lines. If the CTs have an arrow, install them so that the
arrow points toward the mains breaker. This is very important:

    *Be sure to orient all of the CTs the same way 
    with respect to source and load. By doing so, you 
    reduce the number of possible incorrect solutions to 5.* 

Connect the CTs to the IoTaWatt and use the `inputs` setup to
set the CT model. Check the *allow negative values* box for each.

Configure the VT
^^^^^^^^^^^^^^^^

Set up your IoTaWatt with the voltage reference VT on whatever 
phase of the three-phase is convenient. We will call that phase
A. This is important:

    *However you identify your physical phases, IoTaWatt always 
    identifies the phase that the VT is connected to as phase A.*

The other two `derived` phases will be phase B and phase C. 
It doesn't matter which of the physical phases
your VT is connected to. Your starting point is always A.

There are color coding schemes for the phases, but they vary widely,
so no attempt will be made to reconcile these instructions with
colors or local alphanumerical designations.  If your system uses
designations A, B and C for the phases, it would avoid confusion if
the VT could be plugged into your phase A. 
The good news is that you really don't have to know what 
any of the phases are to complete this setup.

Identify Phase A 
^^^^^^^^^^^^^^^^

For this step, you will need a significant plug-in load, such as 
a hair dryer, toaster, or possibly a high wattage incandescent light.
As previously stated, Phase A is the phase that the VT is connected to.
To identify that phase, connect the load to the same
outlet as the VT.  You may need to temporarily employ a power strip.

While watching the power draw of the three mains on the IoTaWatt status display,
switch on the load.  One of the three mains should change.  To be sure, 
switch the load off, then back on several times. The status display is damped, 
so it takes several seconds to settle on the new value. 
This is phase A.

Note by how much phase A changes when you switch on the load.  You will need
to know that in the next step.  If phase A is negative and decreases when you 
switch on the load, you can either:

        * Reverse the VT in it's socket - or -
        * Check the `reverse` box for **all three** of the mains CTs.

    *There is now only one correct and one incorrect solution.*

Identify the Other Two Phases
^^^^^^^^^^^^^^^^^^^^^^^^^^^^^

At the bottom of the input configuration menu, 
Check `Enable derived three-phase`.
The configured input channels will now have "phase:A" 
appended to their descriptions.

**Derived Three-phase Inputs**

You know which of the three is the `real` phase A. 
Edit the other two and assign to phase B.

**Derived Three-phase Selection**

Locate another outlet that you know or suspect is not on phase A.
Connect the load and cycle as before.  Notice which main changes.
If it's A, try other outlets until one of the other two phases changes
with the load.

Note by how much the main changes when you cycled the load.  If it's the
same as it was on phase A, then this is phase B, change the remaining 
main to phase C.

If it is significantly less, closer to half the change that you noted on phase A,
then this is phase C. Change it to phase C leaving the remaining phase as B.

Test the load again.  It should increase by the same amount as when it was 
on phase A.

The derived configuration is now complete. Jump to 
`Branch Circuits`_ below.

Configuring Direct Reference
----------------------------

Connecting additional VTs
^^^^^^^^^^^^^^^^^^^^^^^^^

To use Direct Reference three-phase power measurement, 
it's necessary to install two additional 
VTs (total of three), and to plug each of them into a 
receptacle that is supplied by a unique phase. 

Version 5 of IoTaWatt has plugs to connect the additional VTs.
This tutorial will assume you have the version 5
IoTaWatt.

The additional VTs will plug into two sockets at the rear
of the unit.  They are labelled VT-13 and VT-14.
When these are used, the standard channel 13 and 14
jacks cannot not be used for CTs.

**V5 VT Inputs**

Configuring the voltage inputs
^^^^^^^^^^^^^^^^^^^^^^^^^^^^^^

Now the additional VTs can be configured and calibrated. 
Do this in the same way that the first VT was configured. 
Click the channel number, click "VT" then specify the model. 
You can also calibrate the voltage if desired. 
It's not necessary that the VTs be plugged into their 
eventual phase to calibrate. 
If you have two outlets on any of the phases, 
use those to plug in each VT in turn along with a voltage 
reference while you calibrate. Once calibrated, 
the VTs can be moved to the appropriate phase/socket.

**Add Additional VTs**

Name each of the phases to uniquely identify each reference. 
You can use phase_A, phase_B etc., 
or maybe use the color coding of your system to be more descriptive - 
voltage_red, voltage_black, voltage_blue (US).

Configuring the CTs
^^^^^^^^^^^^^^^^^^^

Now add your mains CTs. 
The twist here is that because more than one VT is configured, 
an additional selection box is displayed to specify 
which VT is associated with the phase of that particular CT.

**Select Reference VT**

Set associated Vref in each CT

**Select Reference VT**

Branch Circuits
---------------

Like the mains, all of the branch circuit CT should be oriented the same way.
In panels that observe a color convention for the different phases, it 
should be easy to determine the main, and thus the phase, associated with
each branch circuit.

Where the wires are not coded, it will be necessary to trace them back to the main,
or if it's a single-phase branch, cycle it and see which main responds.

North American three-phase panels look very similar to split-phase panels except
rather than alternate between two split-phases, each side alternates through 
the three phases.

If using `derived reference`, simply set the corresponding mains phase in 
each branch CT configuration.  If using `direct reference` set the corresponding 
VT in each branch CT.

Reporting Power
---------------

When all of the VTs and CTs are configured, 
there are several ways to view the power used. 
For circuits and/or loads that use only one phase, 
the power value displayed for that channel should be correct as is. 
If there are devices that use two or three of the phases, 
you must add the power from each of those phases to get total power. 
For each such device, define an output channel and use the calculator 
to specify which channels to add. 
If you are reporting the data to a server, 
the data can be tailored with the calculator to send the single 
combined aggregate power for those devices.

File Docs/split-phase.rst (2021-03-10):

========================
Split-Phase Installation
========================

This chapter assumes the reader has read the `CT Basics <CTbasics.html>`_ section.

--------------------
What is split-phase?
--------------------
Worldwide, virtually all of the residential power delivered to residential homes
is 230V-240V single phase.
In North America, the single-phase 240V supply is split so that there are two 120V
legs that are typically used for lighting and light-duty appliances.
To learn more see the
`Split-Phase Wiki <https://en.wikipedia.org/wiki/Split-phase_electric_power>`_.

------------------------
Split-phase load centers
------------------------

Split-phase load center

    Maybe neater than normal load center

A typical split-phase load center has two Main circuit breakers, one for each of the two
"legs" coming from the service entrance.  There is also a third neutral wire that is
directly connected to the neutral bus - a long bar with holes and screws to connect
conductors.  Another ground bus is provided which is connected to a reliable local
earth connection like a ground stake.  
In most entrance panels, but not sub-panels, the neutral and ground busses are "bonded" (connected together).

The service is typically described in terms of the amperage rating of the Mains 
circuit breakers or fuses.  Most common are "100A service" and "200A service".

See the North America section of this Load-Center Wiki_.
to see how the split-phases correspond to alternating breaker rows. 

.. _Wiki: https://en.wikipedia.org/wiki/Distribution_board

----------------------
Monitoring split phase
----------------------
When monitoring a circuit in a split phase service, it's helpful to
recognize exactly which of the mains circuits it is utilizing.
There are three possibilities:

............
120V phase A
............ 
    These circuits are two conductor (plus ground) and typically use
    a black conductor connected to the circuit breaker and a white
    conductor connected to the neutral bus. As described in the Wiki_,
    circuit breakers in odd rows will be on phase A.
    Odd rows include breakers numbered [1,2] [5,6] [9,10]..etc.

............
120V phase B
............ 
    Same as above, except circuit breakers will be in the even rows
    with breakers numbered [3,4] [7,8] [11,12]... etc.

....
240V
....
    These circuits are typically larger appliances like Hot-Water,
    Range, Pumps, Electric Heat, Dryers, Heat-pumps, sub-panels, 
    and Air-conditioners. They use two circuit breakers in adjascent
    rows, so one of the breakers is on phase A and the other is on phase B.
    
    As explained in the `CT Basics <CTbasics.html>`_ section, 240V 
    loads can be two-wire or three-wire.

    Two-wire loads typically use two conductor cable with the white and 
    black conductors connected to the two circuit-breakers.  For these 
    circuits, a single CT can be placed on either one of the two conductors
    and the "double" box checked to indicate to IoTaWatt that the voltage
    is doubled to 240V. Orientation of the CT is dependent on the row that
    the CT is associated with.

    Three-wire loads typically use three conductor cable with black, red,
    and white conductors.  The red and black are connected to the two 
    breakers and the white is connected to neutral.  These loads must 
    be measured with two CTs, one on the red and one on the black, or 
    by passing the two conductors through one CT in opposite directions 
    so that the resulting orientation of the CT is correct for the row
    of the breaker that each conductor is connected to. An illustration
    can be found in the `CT Basics <CTbasics.html>`_ section.

-----------------
Voltage Reference
-----------------
The voltage between the two mains conductors is nominally 240V.
That is broken down into two 120V potentials between each of the
Mains and the neutral, but unless they are in perfect balance,
there will always be a difference in voltage between the two phases.
That said, the difference in most situations is practically negligible
and the sum of the two will always equal the voltage between the two Mains.

This is an important point, because in order to measure real-power,
what your meter measures and what you pay for, it's necessary to also have
a reference voltage on that circuit.

IoTaWatt supports multiple voltage references, but as a practical
matter, you only need one to measure any of the three circuits 
described above.

The simplest and most effective reference is a 120V wall
transformer connected to an ordinary 120V plug as close to the 
load center as possible. That will provide a reference for the
phase it is plugged into, *and a reference that is the exact 
opposite of the other phase*, or to put it another way, 
the *reverse* of the other phase. 

--------------------
Mains CT orientation
--------------------
The first CTs to be installed should be the Mains.  

    **As mentioned in multiple discussions, this is a job for someone 
    familiar with the working with live, partially exposed electrical
    wiring and familiar with all of the risk factors.
    An electrician is recommended.**

Because each of the Mains is on a different phase, 
and we are using the same voltage reference for both phases, we need
to reverse one of them so that the current it measures aligns with
the reversed voltage reference.  So which one?  The answer is that because
the wall transformer plug is not polarized as well as other uncontrolled
factors, we don't know yet.  

So what we do is just install
the CTs with opposite orientation, `configure them <CTconfig.html>`_, and 
look at the status display of the IoTaWatt.  If reversed,
they will show a ↺ symbol. To correct this, you can do one of two things.

- Reverse the wall transformer in its socket.
- Click the "reverse" box in the VT configuration menu.

Now, the two Mains inputs should show the Watts for each Main and
no reverse ↺.

-------------------
Load CT orientation
-------------------

First, it's important to note that the only consequence of installing 
a load CT backward is that it
will show a ↺ symbol next to the input in the status display. 
This indicates that IoTaWatt has recognized that the voltage and 
current are opposite and is producing the correct measurement
by reversing the output numerically.  There is no error attributable
to this correction. If the ↺ symbol doesn't bother you, you can place the CTs without
regard for phase.

Another approach is to simply install the CTs without regard for phase orientation
and then simply check the "reverse" box for any inputs that show the ↺ symbol
in the status display or physically reverse those CTs in the load center.

To install with correct orientation initially, the easiest method is to install
one CT on an active circuit and note if the ↺ symbol appears in the status
display.  If so, reverse that CT.  Now note which way the correctly oriented CT is
installed and whether its row is even or odd.

If it's an even row, all of the CTs that you install on even row circuit-breakers
should be installed with the same orientation and the odd row circuit breakers with
the opposite orientation.

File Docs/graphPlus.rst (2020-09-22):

======
Graph+
======

Available with release 02_05_00.

This data visualization application runs in any browser to graphically present 
any of the data stored in the IoTaWatt. It features relative and absolute time period selection 
and handles all units of measure supported by IoTaWatt. You can produce line and/or bar charts 
with optional stacking and fill. Real-time graphs can be set to automatically refresh.  
Once created, any graph specification can be saved for quick future use.

The application is fully adaptive so it will work well on a full range of 
devices from mobile to desktop.  

The window can be broken down into four parts, each serving a different function:

* `Unit/Source selector`_
* `Time period selector`_
* `Graph window`_
* `Trace tables and options`_

Below is a complete window with all of the parts. 
We're plotting power for the current day
(midnight to 5:42pm).  Along with that we've plotted the accrued Watt-hours for the day, 
14.2 kWh as of 5:42.

Graph+ image

Unit/Source selector
--------------------

So now lets break it down.  On the left is the "sidebar" where you select each of the 
measurements that you want to plot.
Every input (or output) can produce a variety of measurements.  
VTs measure Voltage and frequency(Hz), and CTs measure Watts, Watt-hours, Amps, VA,
and Power-Factor (PF).  So the first thing is to select the measurement you are interested in.
At the top are the unit selection buttons. Click on the particular unit you are interested in.

CT sources

The Source list that appears below the unit selection will list all of the sources 
that can produce a measurement with the selected until.  
Basically Volts and Hz pertain to VT inputs and all other units pertain to inputs 
(or outputs) that are configured with CTs. 
The list will change immediately when a new unit is selected. 

On the right Watts are selected and this IoTaWatt lists 15 sources that are configured 
as power channels (CT inputs or CT based outputs). Note that the last entry shows a 
blue trash-can indicating that particular unit/source has been selected and is 
currently graphed.

VT sources

To the left Volts are selected, so a different set of data sources corresponding to voltage
inputs (VTs) are listed.

Click on any of the individual sources in the list to add that data source to the graph, 
measured in the selected unit.  This combination is called a trace.  It will be assigned 
a distinguishing color and the list entry will now include a trash-can symbol with the 
assigned color as a background.  The trace should also appear on the graph within several seconds.  

While the list of sources may be the same for different units like Watts and Wh,
they only show active if they are being graphed in the currently selected unit.
In the case of the graph above, Total-Power is plotted as both Watts and Wh, so it
will appear as selected under both units, but note in the large picture above 
that the color is blue under the Watts unit, while it is green under the Wh units, 
indicating they are different traces.

One final note about the sidebar.  It will disappear when the screen size gets to be 
too narrow to accomodate it.  When that happens, it is replaced by a list icon at the 
top left of the main screen.  Pressing that will overlay the main body with the selection 
sidebar. An X on the sidebar is used to hide it again.

Time period selector  
-------------------------

Graph+ plots all selected traces over a single time period that is defined
and modified using the time period selection section. 
You can select one of the many pre-defined
relative time periods or specify absolute dates and times.
Once data has been plotted, the zoom/pan buttons can be used to modify the 
time-frame.  Graphs with relative time-periods ending in the present can be set to 
automatically refresh.

Time timeSelector

Period Selector
...............

This is where you specify an initial time period, and where you go to change it.
In the upper left is a dropdown selector that is used to specify common relative 
time periods.

Period list

For most analysis of recent activity, these selections should make things
quick and easy.  All of these predefined periods are relative to the current date/time.
So if you ask for today, you will get a plot of measurements from midnight to the 
current time.

Group Selector 
..............

IoTaWatt records each measurement at 5 second intervals. That's 17,280
measurements per day. The graph size cannot possibly represent that, and it would take
a long time to query that amount of data.  Instead, IoTaWatt can deliver either
the average value or net change of a measurement for any given interval.
So when plotting a day's worth of data, we ask for automatic grouping which results
in aggregating the data over 2 minutes in a 24 hour period.  If you were looking at
one hour or less, the grouping would be the highest resolution 5 seconds.

There are other choices when looking at longer time periods. Here we're plotting last month's 
usage and will group by day.  This will return the average or change in value for each of
the 28-31 days in the past month.  All units are averaged except Wh, which return the
total used in each grouping.  So in this case, there would be 28-31 data points plotted.

Group Selecting

It's important to note that when selecting grouping by day, week, month or year, you are
not just getting the nominal grouping of 24 hours, 168 hours, etc.  The selection process
recognizes daylight-time in determining hours and days, and recognizes day of week,
and month boundaries.

*   Weeks begin and end at 12:00am on Sunday.
*   Months begin and end at 12:00am on the 1st day of the month.
*   Years begin and end at 12:00am on Jan 1.

Custom Date Selection 
.....................

If the time period needed isn't covered in the selection list above, there are 
date pickers that can be used to choose specific start and end dates (and times).
If you click on these dates, a calendar will appear to select a start and/or 
end date and time.  When you change either of these dates, the period selector 
will automatically change to "custom dates" and the graph will be updated to span
the new date specification.

This is only one of several ways to manipulate custom dates. There are two other
ways to modify the dates bounding the current graph.  The most obvious is the 
zoom/scroll bar.

Zoom/Scroll bar

This bar works just as you think.

* Zoom (+) will zoom in 50% on the center of the graph.
* Zoom (-) will zoom out 100% on the center of the graph.
* Left Full (<<) Will shift the time into the past 100%, ending where it once began.
* Left Half (<) Will shift the time 50% into the past.
* Right Half (>) Will shift the time 50% into the future.
* Right Full (>>) Will shift the time 100% into the future, starting where it once ended.

There is one last way to modify graph period.  You can simply select a subset of 
the graph window holding down the left mouse button.  When you release it, the 
highlighted selection will become the new time period.

Screen Selection

Refresh/Freeze
..............

The Refresh Button button will immediately refresh the current plot.
If the time period of the current plot ends at the current time, 
as in the "Today", "Last 10 minutes", etc., the display 
will continue to refresh at the "interval" rate.  
For example if the auto interval is 2 minutes, it will continually refresh every 2 minutes.
You will know it is auto refresh mode because the Refresh button will change to
Freeze Button. If you click this button the auto refresh will stop and the button will
revert to the manual Refresh Button button.

The Refresh/Freeze state is retained when saving and subsequently restoring graphs.
This feature is useful when loading a saved graph as an embeded window where there are
no controls, allowing an auto refresh graph can be displayed in a frame.





Graph window
-------------

Once data sources are selected, the graph window comes to life.

Graph Window

In the upper left is the legend, a list of all of the unit/source combinations that are 
being plotted. The color of each trace matches the color used to designate 
the source selection and the color associated with the trace in the option table that
will be described later.

There is no notion of a left or right Y-axis selection.  
Each unit that is included in the plot is alternately placed on the left and right side 
of the plot automatically. 
You know which scale pertains to each trace because the scales contain the unit designation.  

Trace tables and options
------------------------

The last major section of the window is the options and information table area.  This is a 
multi-purpose area that displays different tables depending on the selection in the 
top row. There are four tables:

Options Table 
.............

Options Table

This table lists all of the traces selected for the current graph, and allows 
modifying the default settings for each trace.  Changing an option will have
an immediate effect on the graph.  There is no Save or Refresh required.

:Arrows:
  These sort arrows appear when there are two or more entries in the table.
  Use them to reorder the entries.  Primarily helpful when using Stacked traces.

:Trash: 
  Removes the trace from the graph and deselects from the source list.

:Color: 
  Selects an overide color.

:Line/Bar:
  Toggle between line or bar chart for this trace.

:Fill:
  Fill the area under the line or bar.

:Stack:
  Stack this trace above any other stacked traces appearing
  before it in this list.  You can change the position of a 
  trace (and so it's stack position) using the sort arrows 
  appearing at the beginning of each entry when two or more 
  traces are present.

:Accrue:
  This checkbox will appear on Wh traces and causes the Watt-hours
  to accrue in order to plot a running total.  Wh are accrued in the sample
  graph to illustrate this feature.

:Decimals:
  The number of decimal places to request and plot.  The default
  value is typically appropriate for the unit of measure, but 
  sometimes increasing the precision provides a more detailed representation.

:Scale:
  The values returned in the query will be muliplied by this scale factor.
  This will affect the values in the CSV table as well.

Statistics Table 
................

Statistics Table

This is a list the traces with useful statistics.

:Arrows:
  These sort arrows appear when there are two or more entries in the table.
  Use them to reorder the entries.  Primarily helpful when using Stacked traces.

:Trash: 
  Removes the trace from the graph and deselects from the source list.

:Quality:
  This indicates the number and percent of groups for which data was 
  available.  It is typically 100%, but could be less because of power 
  failures or malfunction during the period.  

:Min:
  The smallest group value graphed for this trace.

:Max:
   The largest group value graphed for this trace.

:Diff:
  Difference between Min and Max.

:Average:
  Mean value of all of the groups graphed for this trace. 
  Does not include null values.

:Sum:
    For Watt and Wh traces this is the total Wh for the period.

Yaxes Range Table 
.................

Yaxes Range Table

This list is used to modify the Yaxis range for each unit.  The default is "auto",
which works well to represent the full range of the data, however the Min and/or Max 
can be specified here to overide the auto default.  Once changed, the new limit will remain 
in effect until one of these things happens:

* The overide value is removed.
* A saved graph is loaded.
* The reset button is clicked.

Plot Range:
  The Yaxis range used in the current graph.

Data Range:
    The actual range of all of the traces using this unit.

Min:
    The lower bound to be used in subsequent graphs, or blank for auto assignment.

Max:
    The upper bound to be used in subsequent graphs, or blank for auto assignment.

CSV Data 
........

CSV Data area

This is a comma-separated-values listing of all of the data used in the current graph.
The first column is the time, subsequent columns are the group values for the
traces in the order that they are listed in the options or statistics tables.

There are a couple of options available:

Time Format:
    * Date-time string - selects a date and time format acceptable to spreadsheets.
    * Seconds-from-start - selects a count of seconds from the start time.
    * Unix-time - selects the count of seconds from Jan 1, 1970 UTC.

Null Values:
    * Show - include missing or invalid lines with "null" as a value.
    * Remove line - Where a line has a null value, remove the entire line from the display.

Copy:
    Copy the contents of the CSV table to the clipboard.

Download:
    Download the CSV data as a file.
    
Saving Graphs
--------------

Graph+ is great for ad-hoc queries, but it can take some time to fine-tune a 
busy graph, and it recreating it weekly or monthly can get old.  This is where 
the ability to save a set of graph specification comes in handy.

At the bottom of the sidebar you can save and reload any number of graphs.
Each graph is saved in the IoTaWatt, so it doesn't matter if you use a different 
browser or device to recall them, they will always be there.

Saved Graphs

Once you have a graph that you like, enter a description in the *Graph name:* box. 
The **save** button will appear.  Click it. The graph has been saved. Click the 
*Saved Graphs:* selector and a list of all of the saved graphs will appear.
Click any selection and Graph+ will load that graph specification.

Saveds Monthly Wh

This is a graph of total monthly kWh to date.  Once loaded, I can do a lot with it:

* Change group to Weekly to see it by week.
* Change the period to last-year or anything else.
* Show the CSV table to see list of usage by month.
* Add traces for particular circuits, stacking if appropriate, to see a breakdown.
* Move the data to a spreadsheet to apply your tariff and convert to cost.

Note that you are saving the graph *specification*, not the actual graph.  If you
save a graph of yesterday and reload it tomorrow, it will plot today. If you want to
save a static graph, select the *custom dates* period at the top before saving.

Whenever a saved graph name is in the *Graph name:* box, the **Delete** key will be 
available. To change a graph specification, simply load it, make the changes and save 
it again.

Running Directly with URL
-------------------------

Graph+ can be loaded directly from the IoTaWatt's web server using the URL

http://iotawatt.local/graph2.htm [?graph=savedgraph [&embed] ]

Substitute your local hostname/IP address if different.

graph=
......

Optional query parameter to specify a saved graph that is to be loaded initially.

embed
......

Causes Graph+ to display only the plot window of the selected graph. 
If the saved graph has refresh enabled, the plot will refresh at the 
active interval.

Reset
-----
Sometimes you just want to start over with a clean slate like the app was just loaded.

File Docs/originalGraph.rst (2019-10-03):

==============
Original Graph
==============

The original local graphing feature was derived from the Emoncms graphing 
application and adapted to report the input and output channels 
of IotaWatt directly. It is available on devices 
connected to the same WiFi network as the IotaWatt or on the 
internet using local port forwarding.

From the configuration app click "Data" and then select"Original Graph" **Data Button**.

Blank Graph

Press the Voltage, Power, and Energy tabs under Feeds to list your 
IotaWatt input and output channels. Select the Power tab and then 
select one or more of your channels listed there. Selecting 
Total_Power (actually an output channel that is the sum of Main_1 and Main_2) 
we get the following graph.

Total Power Graph

Notice that the graph covers a 24 hour period. 
That's the default. You can select the period using 
the D, W, M, Y buttons at the top, and you can move 
the time frame left or right and zoom in or out.

Back to this graph. It reveals that average power is about 600 watts. 
To be precise, the mean power is 595 watts and the total power 
for the day was 14,300 watt-hours (14.3Kwh) as indicated in the 
feed statistics at the bottom. Wondering what might be causing 
those spikes at various times throughout the day? 
Lets lay some other input channels on top.

Multi-channel Graph

Now the story unfolds. Most of the 1000 watt spikes are cycles 
of a point-of-use electric water heater in the Kitchen (Kitche_HW). 
The big spike around 9pm is the Oven/Stove circuit, and the rest 
of the spikes seem to line up with kitchen appliances.

That's just a sample of the power of the graphic presentation 
possible both locally and with essentially the same tool on Emoncms.org. 
Practically speaking, those power spikes are not the meat-and-potatoes 
of home energy use. Other circuits reveal the contribution of workhorse 
appliances like the refrigerator, freezer, 
heat-pump (not active this day), clothes dryer, 
computer and office machines. Kwh can be plotted as well, 
and compared to the whole. With 14 input channels, 
its possible to divide household usage into manageable components.



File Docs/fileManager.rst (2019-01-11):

=======================
File Manager and Editor
=======================

IoTaWatt file systems
---------------------

IoTaWatt has two file systems. 
The primary file system is maintained on the internal SDcard 
and is formatted as FAT32. Typical SDcard size is 8Gb. 
All of the web server files as well as the 
data and message logs are maintained on the SDcard.

The ESP8266 also has an onboard file system called the 
SPI Flash File System or SPIFFS that is much smaller at 1Mb. 
IoTaWatt uses that area for limited device specific information. 
This file system uses a flat directory structure, however 
IoTaWatt presents it as hierarchical through the file manager.

File Manager
------------

The integrated web server can be used to access and manage 
the files on both the SDcard and in the SPIFFS file system. 
The web server is based on the generic ESPWebserver developed 
by the folks at the ESP8266/Arduino project. 
The file manager application is the unmodified application 
that they distribute. The major functions are:

*   Display file system
*   Delete files
*   Upload files to the IoTaWatt
*   Download files from the IoTaWatt
*   Edit files

The File Manager is accessed from the dropdown buttons in the 
Tools main menu.

File Manager

The left column is the file list. 
Directories can be expanded by clicking the + sign 
as in the typical paradigm. Action can be taken on individual 
files by right clicking and selecting from the options:

*   Edit
*   Download
*   Delete - Proceed cautiously. 
    There is no confirmation popup. Delete is delete now!

Downloading Files
-----------------

To download a file, right-click it in the file manager as above
and select the Download option. Exactly how it is handled and
where the file is downloaded is a function of your operating
system and browser, but it will follow the normal protocol.

Uploading Files
---------------

Files can be uploaded to the IoTaWatt by clicking the 
Browse button at the top and selecting a file in the manner 
provided by your browser. Once selected, click Upload to transfer 
the file to the IoTaWatt file system. You can edit the 
pathname before uploading. 
Additional buttons are provided to create a new directory or file.

SPIFFS
------

The SPIFFS is presented as the directory esp_spiffs. 
Expanding that directory will reveal the contents of 
the SPIFFS with a pseudo hierarchical directory structure. 
Files can be accessed in the same way as on the SDcard.

ACE Editor
----------

One of the most powerful features of this app is the editor. 
It's a version of the open `Ace Editor <https://ace.c9.io/>`__ 
and is very fast and capable. 
It's not particularly useful on mobile devices, 
but does very well on a keyboard equipped browser. 
You will need to learn the keyboard shortcuts, 
but even with just a few of the usual suspects, you can be very 
productive (ctrl-S save, ctrl-Z undo, ctrl-F find, etc.)

The IoTaWatt configuration app was developed exclusively 
using this editor and an IoTaWatt. 
In fact, that's the file that appears in the editor 
window when you start the file manager app.

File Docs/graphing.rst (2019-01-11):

========
Graphing
========

If you are uploading your data to Emoncms.org or influxDB, 
there are a variety of ways to organize and view your voltage,
power and energy use. The servers are fast and accessible 
from any place where there is internet connectivity. 
But there are some circumstances under which you may want to 
access your data locally:

*   You are not using Emoncms or influxDB to save your data.
*   You require finer resolution than is used in your Emoncms feeds.
*   You have output channels defined on your IotaWatt that are not
    replicated on Emoncms.
*   You want to post-process and view historic data using IotaWatt's
    output channel feature.

The local graphing feature is derived from the Emoncms graphing 
application and adapted to report the input and output channels 
of IotaWatt directly. It is available on devices 
connected to the same WiFi network as the IotaWatt or on the 
internet using local port forwarding.

From the configuration app click **Graphs Button**.

Blank Graph

Press the Voltage, Power, and Energy tabs under Feeds to list your 
IotaWatt input and output channels. Select the Power tab and then 
select one or more of your channels listed there. Selecting 
Total_Power (actually an output channel that is the sum of Main_1 and Main_2) 
we get the following graph.

Total Power Graph

Notice that the graph covers a 24 hour period. 
That's the default. You can select the period using 
the D, W, M, Y buttons at the top, and you can move 
the time frame left or right and zoom in or out.

Back to this graph. It reveals that average power is about 600 watts. 
To be precise, the mean power is 595 watts and the total power 
for the day was 14,300 watt-hours (14.3Kwh) as indicated in the 
feed statistics at the bottom. Wondering what might be causing 
those spikes at various times throughout the day? 
Lets lay some other input channels on top.

Multi-channel Graph

Now the story unfolds. Most of the 1000 watt spikes are cycles 
of a point-of-use electric water heater in the Kitchen (Kitche_HW). 
The big spike around 9pm is the Oven/Stove circuit, and the rest 
of the spikes seem to line up with kitchen appliances.

That's just a sample of the power of the graphic presentation 
possible both locally and with essentially the same tool on Emoncms.org. 
Practically speaking, those power spikes are not the meat-and-potatoes 
of home energy use. Other circuits reveal the contribution of workhorse 
appliances like the refrigerator, freezer, 
heat-pump (not active this day), clothes dryer, 
computer and office machines. Kwh can be plotted as well, 
and compared to the whole. With 14 input channels, 
its possible to divide household usage into manageable components.



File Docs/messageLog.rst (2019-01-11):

===========
Message Log
===========
The message log is the IoTaWatt's Diary. 
It makes notes about various events that occur, 
both ordinary and unusual. These messages can be helpful in 
understanding what is happening with the device, 
or to provide insight into why something doesn't 
appear to be working as it should.

The primary method of accessed the message log is 
by hovering over the Tools main menu button and clicking 
the Message Log button. 
The config utility will cause your browser to download 
and display the most recent 10000 characters in the log. 
You can access the entire log by using the File Manager 
app to download the file /iotawatt/iotamsgs.txt and 
viewing with a text file editor.

With the exception of the first messages after startup, 
all of the messages in the log will have a date and time stamp. 
Messages issued by one of the IoTaWatt Services will begin 
with the name of the service followed by a colon, 
as in this message issued from the datalog Service 
indicating it has successfully started.

::

    12/23/17 21:57:06 dataLog: service started.

While it would be impossible to maintain a list of all 
of the possible messages, 
the messages issued at startup are pretty straightforward 
and provide a lot of information.

::

    ** Restart **

    SD initialized.
    1/08/19 19:39:43z Real Time Clock is running. Unix time 1546976383
    1/08/19 19:39:43z Power failure detected.
    1/08/19 19:39:43z Reset reason: External System
    1/08/19 19:39:43z ESP8266 ChipID: 427289
    1/08/19 19:39:43z IoTaWatt revision 4.9, firmware version 02_03_20
    1/08/19 19:39:43z SPIFFS mounted.
    1/08/19 14:39:44 Local time zone: -5:00
    1/08/19 14:39:44 Using Daylight Saving Time (BST) when in effect.
    1/08/19 14:39:44 device name: IotaWatt
    1/08/19 14:39:47 Connecting with WiFiManager.
    1/08/19 14:39:53 MDNS responder started for hostname IotaWatt
    1/08/19 14:39:53 LLMNR responder started for hostname IotaWatt
    1/08/19 14:39:53 HTTP server started
    1/08/19 14:39:53 WiFi connected. SSID=flyaway, IP=192.168.1.102, channel=1, RSSI -69db
    1/08/19 14:39:53 timeSync: service started.
    1/08/19 14:39:56 statService: started.
    1/08/19 14:39:56 Updater: service started. Auto-update class is BETA
    1/08/19 14:39:57 dataLog: service started.
    1/08/19 14:39:57 dataLog: Last log entry 01/08/19 14:39:35
    1/08/19 14:39:57 historyLog: service started.
    1/08/19 14:39:57 historyLog: Last log entry 01/08/19 14:39:00
    1/08/19 14:39:58 influxDB: started, url=192.168.1.101:8086, db=iotawatt, interval=10
    1/08/19 14:39:58 Updater: Auto-update is current for class BETA.
    1/08/19 14:39:58 influxDB: Start posting at 01/08/19 14:39:40

Some things to look for:
::
    Real Time Clock is running. Unix time 1546976383

Except for initial setup, the RTC should always be running.
If it is not, suspect the battery needs replacement.
::
    Power failure detected.

This indicates that power interrupted prior to the restart.
::
    Reset reason: External System

This is the reason for the restart.
External System is a normal cause. Reasons like WDT and 
Exception indicate program faults and, if frequent, 
should be posted to the support forum.
::
    IoTaWatt revision 4.9, firmware version 02_03_20

The hardware and firmware versions.  Good to know if things
go wrong, and also useful toget the corresponding version
of this documentation.
::
    Local time zone: -5:00

The local time zone specified in you config file.
This message and all subsequent messages should
be timestamped with local-time as opposed to UTC
which was indicated in prior messages with by the suffix 'z'.
::
    device name: IotaWatt

This is the external name of the unit.  It will
be used as the hostname when connecting to
WiFi and it is the name that you must use to 
access the device as in http://iotawatt.local.
::
    WiFi connected. SSID=flyaway, IP=192.168.1.102, channel=1, RSSI -69db

Indicates connection to WiFi and the IP address 
assigned. The RSSI is an indication of WiFi signal strength.
A good number would be between -50 and -78 or so.
If you are having WiFi problems, this metric along with
the channel number can be helpful in resolving.
::
    timeSync: service started.

All of the regular services will log their startup.
Some will also provide additional information 
about their configuration or state. All messages 
from system services begin with the name of the service
followed by a colon.

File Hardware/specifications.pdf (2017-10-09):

IotaWatt, inc.

IotaWatt model 4 Specifications
effective August 1, 2017
Size (HxWxL) | 27x85x125 mm / 1.06x3.35x4.92 in
Weight | 140 g / 4.9 oz

Power
Nominal Voltage | 5 vdc
Connector | micro USB
AC Reference Input | 1
Nominal Voltage | 9 to 12 VAC
Connector | 5.5mm x 2mm
Resistance | 13k ohms
AC voltage/power inputs | 14
Nominal voltage | 0 to 1 VAC rms
Connector | 3.5mm stereo jack
Resistance | 24 ohms

Temperature
Operating | -10 to 50 ºC / 15 to 122 ºF
Storage | -20 to 60 ºC / -4 to 140 ºF

Battery
Type | CR1220
Nominal Voltage | 3V

Storage
Type | Micro SDHC
Capacity | 8 GB min
WiFi | IEEE 802.11 b/g/n – 2.4gHz

PO Box 1679, Wolfeboro, NH 03894

IotaWatt, inc.

Tolerances:

USB Power
Voltage | 5 VDC +/- 5%
Ripple and Noise | 300 mV p-p max
Power | <1W

AC Reference Input
Absolute Maximum | 15 VAC rms / 21 VAC p-p

Voltage/Power inputs
Absolute Maximum | 1.1 VAC rms / 1.5 VAC p-p
| 45maAC rms

PO Box 1679, Wolfeboro, NH 03894

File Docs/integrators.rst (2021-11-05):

============
Integrators
============

What are integrators?
----------------------

The datalog provides high speed access to all monotonic data derived 
directly from the datalog or indirectly with output Scripts.  That is to say, if
the total value only increases, or only decreases, everything works just fine.

The exception is where a CT is configured with "allow negative values" as with 
a mains CT where solar or other alternative energy sources can send excess
energy to the grid.  In those cases, the total energy represented is the net 
energy, and is not a monotonically increasing value. Additionally, Scripts that do 
not result in monotonically increasing values may not produce the intended result.

The individual five-second data in the datalog is the signed net energy
imported (+) or exported (-) during each interval. When that data is viewed in a broader context 
of hours, the net does not provide accurate individual import and export values.

To develop the individual total imported and exported energy values,
IoTaWatt needs to process the detail measurements 
to accumulate the sums of the individual positive and negative values,
and to save each as a monotonic series that can
be used in output Scripts.  That's what integrators do.

How they work
-------------

As previously mentioned, the detail data exists in the current datalog.
When you create an integrator, an additional datalog is created to
contain the integrated values. These are called integrations in the mathematical sense, 
not to be confused with combining as with integrations in Home Assistant terminology.

A background Service is started to process the five-second datalog, by default 
beginning 24 hours prior. This takes about ten minutes. The Integrator accumulates
the positive and negative five-second values in the new integration datalog.

When the background process has processed the historical data, it is *synchronized*
with the current log. At this point the Service terminates and the
datalog Service, which maintains the current log, takes on the task of updating
the integration log as an atomic operation when writing new datalog entries.

When the log is synchronized, 
the integrated results are available for use in output Scripts (calculator)

Creating an Integrator
-----------------------

Hover over **Setup button** and click **Integrations button** in the dropdown buttons.

Outputs Display

This will list any integrations that you have already configured, 
and allow you to click **Add button** to create a new one.  
You can click **edit button** on existing integrations to change or delete them.

Configure Integrator

From here, the process is identical to adding any other output.
For a refresher, see `Adding a new Output <outputs.html>`_ 
Integrations must be uniquely named using alpha-numeric characters and the
underscore (_) character.

The Script that is specified will be integrated to sum the positive and negative components.

Using the data
--------------

Once the Integration is *synchronized*, it should remain so going forward.
When creating a new output Script, there will be three new selections
available in the inputs list.  

Inputs List

They will all begin with the name of the
integration with these appendages:

  .net
    Returns the net value of the Integration script, just as it
    would if the script were used outside of an integration, except that
    the result will be based only on data within the time period defined
    by the Integration log.

  .pos
    Returns the sum of the positive five-second intervals within the requested period.

  .neg
    Returns the sum of the negative five-second intervals within the requested period.

Note that for any period,  .net = .pos + .neg

Tracking Grid import/export with solar
--------------------------------------

To track energy import and export to the grid, use an integration
of a Script that calculates the power flow from the grid (+) and
to the grid (-).

Set "allow negative values" in the config for all mains.
Insure that they indicate positive when importing power (at night).
If they indicate negative at night, reverse the CT or check the
"reverse" box in the config.

Solar inverter connects after mains (most common)
""""""""""""""""""""""""""""""""""""""""""""""""""

The most common service has the solar inverter connected to a breaker
in the service panel, or to the mains cable(s) after the mains CT.
With this configuration, the solar reduces the energy flow in the mains
and will drive the mains negative when generation exceeds energy use.  

Configure Integrator

    Split-phase mains example

Create an output that is the sum of all of the mains.
Typically a 230V single-phase service will have one main,
a split-phase North-American servive will have two mains and
a three-phase service will have three:

  (single-phase)
    grid = main_1

  (split-phase) 
    grid = main_1 + main_2 

  (three-phase)
    grid = main_1 + main_2 + main_3 

Solar inverter connects before mains
""""""""""""""""""""""""""""""""""""

In this configuration, the solar inverter is connected to the mains feeder
before (on meter side) the mains CT. Solar generation does not effect the energy measured
by the mains CTs.

Configure Integrator

    Single-phase solar connected before mains.

You must subtract the solar from the grid total:

  (single-phase)
    grid = main_1 - (solar max 0)

  (split-phase) 
    grid = main_1 + main_2 - (solar max 0)

  (three-phase)
    grid = main_1 + main_2 + main_3 - (solar max 0)

Now plot the grid and solar output using graph+ for yesterday.
Hopefully the sun was shining and your plot looks something like this
where you can see the solar directly reduce the grid power.

grid plot

When you are satisfied the grid output correctly reflects your grid power flow,
delete the grid output and add an integrator named grid with that same Script.

You will see the integration "grid" listed under the Data Logs tab in the Status Display.
Wait about 10-15 minutes for the integration to process the last 24 hours of data.
When the end time is the same as the current log, the integration is "synchronized"
and you can use it to add import and export outputs.
You can reference or query the import and export outputs to get accurate Wh. 

add output "export"
    
Add output "import"

Home Assistant Energy
---------------------

If you followed the examples above, configuration of Home Assistant Energy is
simple and easy.  Once you install a Home Assistant IoTaWatt Integration,
configure Energy like this.

Home Assistant Energy Config









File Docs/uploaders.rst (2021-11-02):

========================
Uploading to Servers
========================

Sending Data to a Web Service
-----------------------------

As a standalone unit, IoTaWatt is a very capable data logger
with an integrated web server/API interface. It can provide
real-time as well as historical data, using the provided 
status-display and the powerful Graph+ application.

That said, there are limitations. While the web server 
typically serves clients on the local network, remote
access requires port forwarding and dynamic DNS to access from
outside. 

There are cloud based services available that will store
uploaded data logger information and present that data to
client applications across the internet. Some of those
databases can also be installed on a private server hosted
by anything from a Raspberry Pi to a commercial hosting
service. IoTaWatt has the capability to upload selected data 
while still maintaining all of its own local logging 
and reporting capabilities.

When one of these services becomes unavailable for any reason,
IoTaWatt will upload the backlog when service is restored,
whether that backlog is a minute or a month.

IoTaWatt can support multiple upload services simultaneously,
so it's not necessary to sacrifice uploading to an influxDB
database in order to participate in the PVoutput project.

To initiate configuration of any web server uploader, hover over
**Setup button** and select **Web Server**.

**Setup Menu**

click the **Web Service:** dropdown and select a server you would 
like to use from the dropdown list. Each service is designated as 

    *   (add) - New service specification
    *   (edit) - modify existing service configuration (including delete)

**Select Web Server Menu**

When you select a server, the configuration menu for that particular server
will appear. For details of configuring each unique server type, click on
the heading of the corresponding section below.

`PVoutput <PVoutput.html>`_ 
---------------------------

PVOutput is a free online service for sharing and comparing photovoltaic 
solar panel output data. It provides both manual and automatic data 
uploading facilities.

Output data can be graphed, analysed and compared with other PVoutput 
contributors over various time periods. The ability to compare with 
similar systems within close proximity allows both short and 
longer term performance issues to be identified.

While pvoutput is primarily focused on monitoring energy generation, 
it also provides equally capabable facilities to upload and monitor 
energy consumption data from various energy monitoring devices.

Both solar generation and energy consumption data can be 
combined to provide a live 'Net' view of energy being  
generated and consumed.

**PVoutput Display**

    PVoutput Graphic Display

`influxDB <influxDB.html>`_
---------------------------

influxDB is a free industrial strength, open-source, schema-less time series 
database. It is fast, efficient and scalable. You can install on a 
Raspberry Pi, a home server, or a commercial web host site.

There are several excellent visualization packages that can be used 
to visualize and report the data.

influxDB/Grafana

    grafana dashboard with influxDB

`Emoncms <Emoncms.html>`_
-------------------------

Emoncms is another open-source time series database that was specifically
designed to handle energy monitoring data with robust set of
visualization tools.

**An Emoncms Dashboard**

    An Emoncms Dashboard

Like influxDB, it can be local hosted on almost any machine, including 
Raspberry Pi, but also is available as a  relatively inexpensive
pay-as-you-go cloud service at emoncms.org.





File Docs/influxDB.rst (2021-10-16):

========
influxDB
========

influxDB is a fast open-source time-series database package. 
It can run on a variety of platforms and is also available 
as a managed, fully hosted service, from several vendors. 
As part of their "TICK" stack, InfluxData provides tools to 
facilitate collecting data from a variety of sources, 
as well as tools for infrastructure monitoring, 
alert management, data visualization, and database management. 
The popular grafana visualization tools also work well with influxDB.

IoTaWatt fully supports the influxDB HTTP API for uploading data 
to influxDB at a specific interval of 5 seconds to one hour. 
Like other similar IoTaWatt services, continuity of updates is 
maintained despite outages that may interrupt the communications.

This tutorial assumes you have established your own instance of influxDB 
or subscribed to a hosted service. It does not attempt to explain 
how to install or use influx or any of the related visualization tools. 
There's a whole universe of enthusiastic users at the influxData forum,
where you can get help with anything and everything.

influxDB versions 1.x and 2.x
-----------------------------

With the introduction of  InfluxDB 2.0
the basic measurement scheme remains the same, but there are significant changes:

- Authentication is changed from the basic userID/password of 1.x to 
  use of an 88 character base64 token.
- Where version 1.x organizes into a `database`, version 2
  introduces the concept of `buckets`.
- The native query in version 2 uses a new `flux` language as
  opposed to the `influxQuery` language in version 1.x.

There are various compatibility options available for transition fromversion 1.x
to version 2, depending on the implementation (cloud or OSS), but IoTaWatt
now supports both versions natively.

The two are similar enough that they will be covered together here with 
breakouts where needed to address the differences.

Configure influxDB uploader
---------------------------

To configure the influxDB upload service in IoTaWatt, 
Hover over |Setup| and click 
|uploadersButton| from the dropdown menu.

**Setup Menu**

Choose the appropriate version of influxDB...

**Select influxDB**

Depending on the version that you selected, you will get one of two
similar setup menus.

**Version 1 Setup**

**Version 2 Setup**

**post interval**
    Number of seconds that each data point will represent. 
    The trade-off is between higher resolution (small interval) and 
    minimizing the storage requirement of the data over time (larger interval). 
    IoTaWatt accepts any value from 5 seconds to 3600 seconds (1 hour), 
    in 5 second increments. Although not a strict requirement, 
    it's best to use a number that is an even factor or 
    multiple of one minute: 5, 10, 15, 20, 30, 60, 120, etc.

**bulk send**
    Number of interval postings to aggregate into a single HTTP request. 
    Specifying 1 will send a data packet to influxDB at each interval. 
    If your interval is 5 or 10, it will send a packet every 5 or 10 seconds. 
    That's fairly inefficient and can be problematic when there are internet 
    connectivity issues. By specifying a larger bulk send, 
    IoTaWatt will aggregate the posting data for the specified number 
    of intervals and send the data in one packet. 
    For instance if your interval is 10 seconds, 
    specifying bulk send = 6 will cause data to be sent every 60 seconds. 
    Large bulk send values will cause any real-time dashboards to update 
    less frequently, so you should strike a balance. 
    IoTaWatt keeps all of the data in the SD data log, 
    so there is no risk of losing data by using this feature. 
    Should there be any failure to deliver, 
    IoTaWatt will pick up with the last successful posting when the problem is resolved.

**server URL**
    URL of the influxDB server. If the URL begins with HTTPS:// you must have
    specified a HTTPSproxy_ server.
    The url may contain a domain name or an IP address. 
    The *:port number* is optional and defaults to the influxDB port 8086 for version 1.

    .. _HTTPSproxy HTTPSproxy.rst
    
**upload history from**
    Specify the starting date that IoTaWatt will use to upload history 
    to a new set of measurements. When the influxDBService starts, 
    a query is made to determine the date/time of the last data written, 
    qualified by the first tag-set. Data upload is initiated as follows:

    ============================ ============================================== ========================
    Condition                    begin date specified                           begin date not specified
    ============================ ============================================== ========================
    new measurement set          begin date 00:00                               current date/time
    existing measurement set     greater of last entry date/time or begin date  last entry date/time
    ============================ ============================================== ========================

**measurement**
    Name that you assign to the measurements that IoTaWatt will be posting. 
    The specification can be a constant string, or can include variables 
    as explained below under variables. Note that if not specified, 
    the variable $name will be used.

Unique Version 1 Parameters
---------------------------

**database**
    Name of the influxDB database that you 
    have created to be the repository for the IoTaWatt data.

**retention policy**
    Optional name of the influxDB retention policy that you want to associate 
    with the measurements that are written to influxDB.
    If not specified influx will use the default policy. 
    If you specify a retention policy, it must be defined to influxDB before data can be written.

**username/password** 
    Optional security credentials. If specified, IoTaWatt will 
    use standard authorization headers with these credentials.

Unique Version 2 Parameters
---------------------------

**bucket**
    The name of the influxDB `bucket` to contain the measurements.
    Roughly the equivalent of the `database` in v1.

**organization ID**
    The 16 hex-digit organization identifier specific to the server instance.
    Organization Id is found from the InfluxDB Web GUI by clicking your user
    icon on the left navigation bar, then `About` and copy the 16 hex-digit value.

**Authorization token**
    Authorization token produced by influx. (Data->Tokens->Generate Token-> Read/Write Token for IotaWatt bucket)
    This is an 88 character base64 string that should be
    copied and pasted to avoid transcription errors.  The token is the shared secret that
    authorizes access to the bucket.

tag-set
-------

**tag-set** 
    A collection of optional user specified tag-key/tag-value pairs 
    that will be included as part of each measurement. 
    The influx documentation somewhat explains them here. 
    Basically, these tags each produce a table index that can be helpful 
    in increasing the performance of data retrieval. 
    The first tag-set is a special case for IoTaWatt, and if specified, 
    is used to uniquely identify the measurement subset from this device 
    so that upload can resume seamlessly. If this is not the only device 
    that will be posting to the database, 
    a unique identifier for this device should be included as the 
    first entry in a tag-set. tag-values can be a constant string 
    or can include variables as explained below under variables

    edit an existing tag by clicking on it's associated edit button,
    or add a new one with the add button. add tag-set

**Influx tag-set**

**field-key** 
    Each measurement contains a field key and field value. 
    The field value is always the value specified in the "calculator" function. 
    The field key to be used is specified here. 
    It can be a constant string or can include variables as 
    explained below under variables. If not specified, 
    the default field key in each measurement is the string 'value'.

measurements
------------

**measurements** 
    The set of *measurement*s that will be sent at each interval. 
    The editor uses the "calculator" interface to
    create scripts to generate data using the various IoTaWatt inputs. 
    Each entry will generate a measurement using the influx line protocol::

    <measurement>[,tag-key1=tag-value1[,tag-key2=tag-value2...]] field-key=field-value time

Note that **measurement**, **tag-value**, and **field-key** are specified 
above and can be fixed strings or can be or contain variables. 
Some examples of the various ways this can be used to create different 
types of measurement specifications are given below.
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

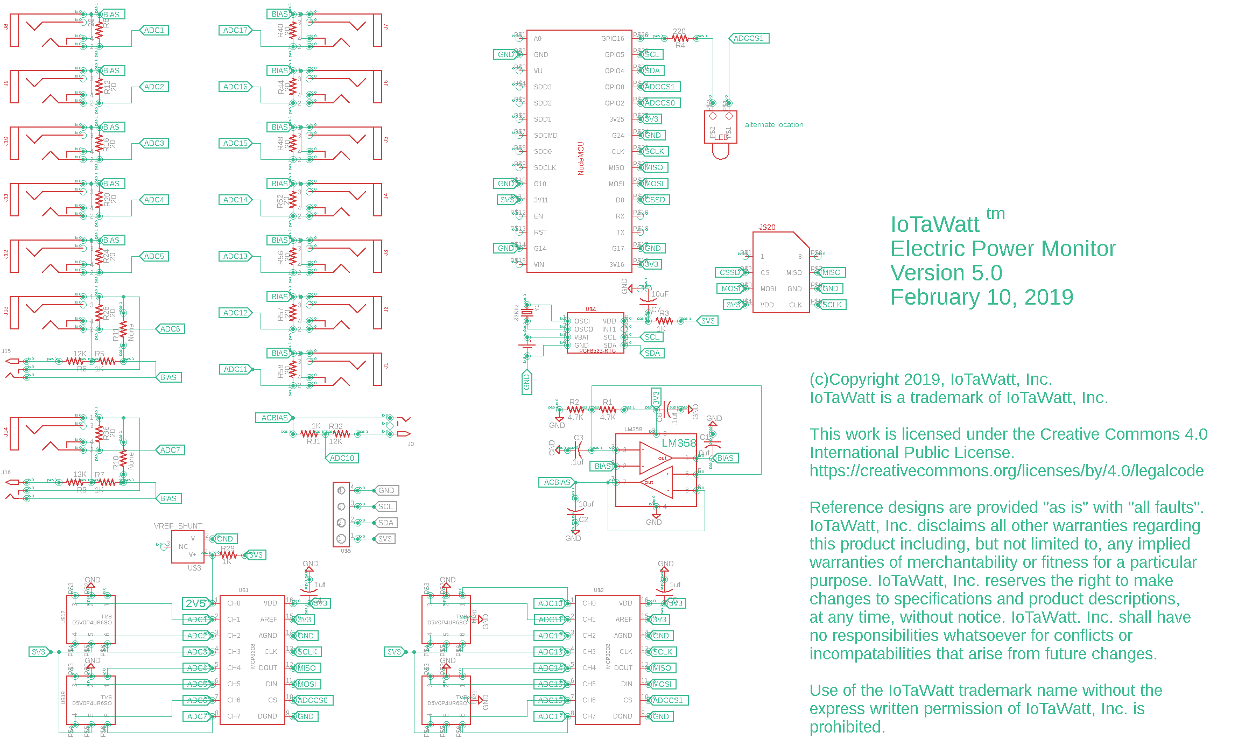
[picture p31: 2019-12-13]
Hardware/V5_schematic.png

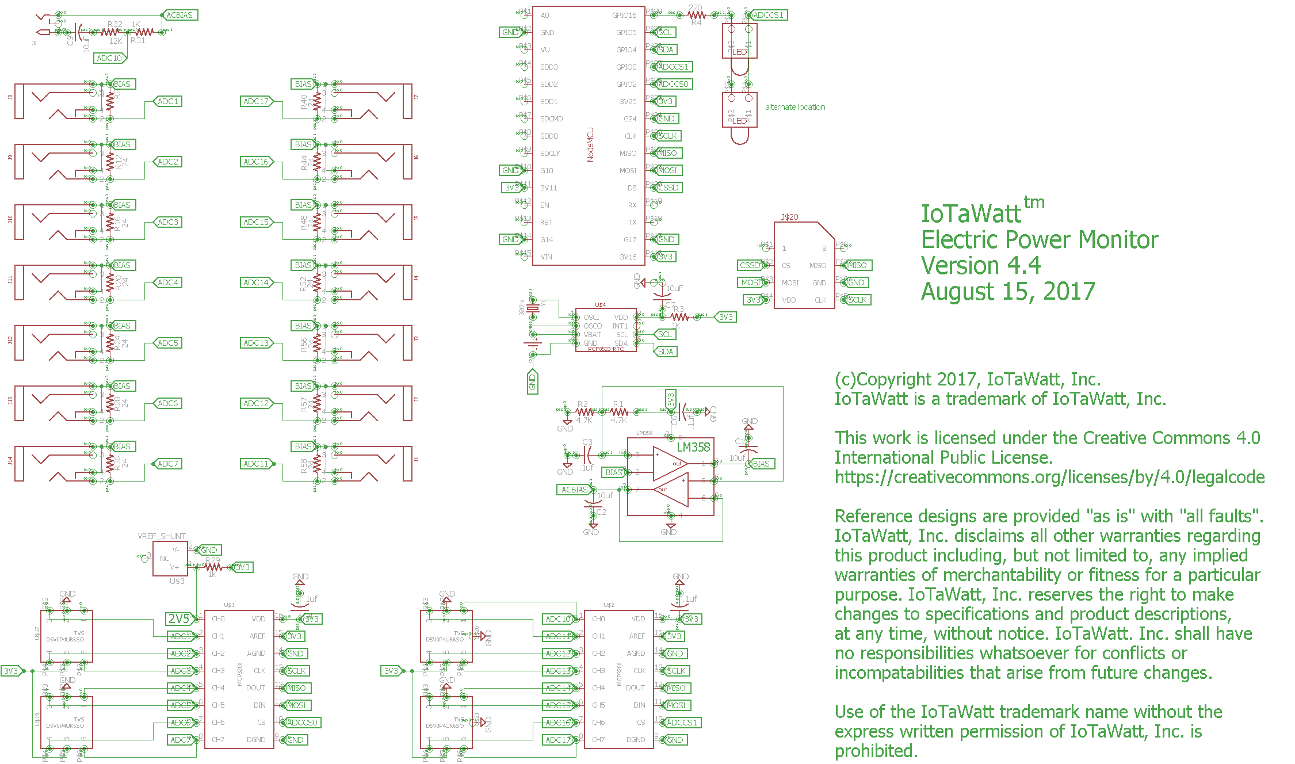
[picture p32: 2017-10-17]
Hardware/IoTaWattSCH.png

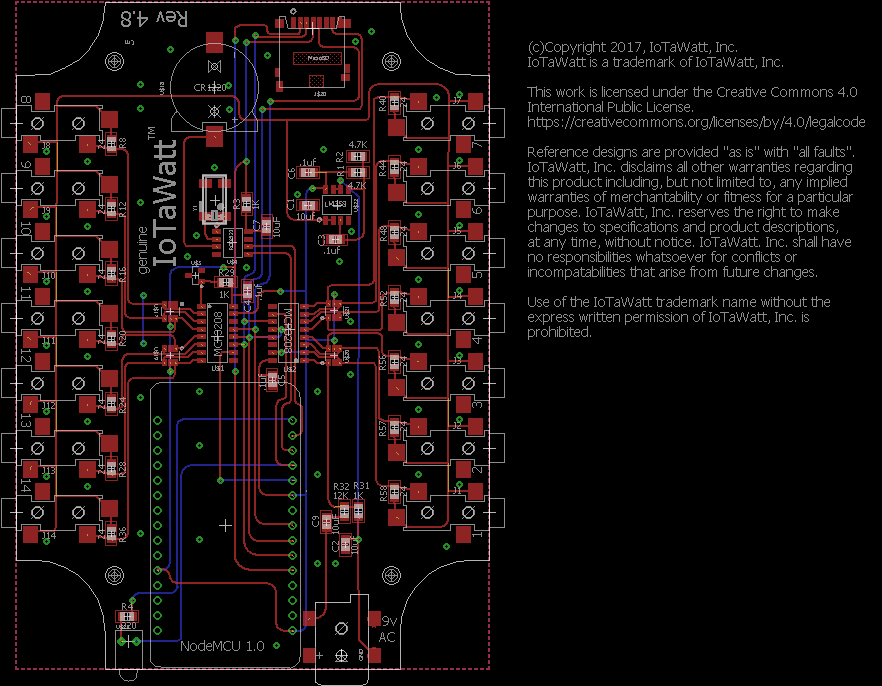
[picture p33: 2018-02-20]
Hardware/IoTaWattPCB.png

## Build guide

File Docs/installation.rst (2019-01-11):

Installation
============

Software vs. Hardware
---------------------

Strictly speaking, IoTaWatt began as a software project
with no specific hardware platform in mind.
That objective was soon supplanted by an open hardware 
design based on the ESP8266. Typical IoTaWatt installations 
use a commercially manufactured unit that is certified to 
UL and CE safety standards and complies with FCC requirements.

The IoTaWatt firmware is factory installed and 
can be automatically and securely updated over WiFi.
This section of the documentation deals with the physical 
installation of the commercial IoTaWatt unit with factory 
installed firmware.

Components
----------

IoTaWatt has 15 input channels.  
One is reserved for monitoring voltage, 
and the remaining 14 can be used to monitor power *or* voltage.
The minimum requirements for operation are:

    * IoTaWatt
    * USB power supply
    * AC voltage reference transformer
    * Current Transformer (one or more)

Voltage and Frequency
---------------------

IoTaWatt can work with all common line voltages at 50Hz/60Hz.
Additionally, it can use multiple voltage references for 
polyphase measurement.
The most common environments are 120/240V 60Hz and 230V 50Hz.
The USB power supply and AC transformer must be appropriate for the power system.

Connections
-----------

Setup is simple:

 #. Connect the USB power supply to the ``5V DC USB``
 #. Connect the AC transformer to the ``9V AC REF``
 #. Plug the power supply and AC transformer into a wall socket

That's it.

Next step: `connecting to WiFi <connectWiFi.html>`__

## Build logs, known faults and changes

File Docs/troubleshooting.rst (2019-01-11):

===============
Troubleshooting
===============

Led Indicator
-------------

The IotaWatt has a bi-color external LED indicator that is usefull in 
determining the current state and for explicitely indicating 
serious problems. Whenever there is a question about whether 
something may be wrong, it is important to look at the LED indicator. 
The LED can blink RED (R) or GREEN (G). 
When indicating a device state, it will repeat a sequence of 
colored blinks.

Dull Green Glow
---------------

This typically means that the device is connected and working properly.

Dull Red Glow
-------------

This indicates that the device is working properly, 
but either there is no WiFi connection or the real time clock 
is not initialized and the time cannot be established from 
time-servers on the internet via WiFi. 
As long as the real time clock is initialized, 
the IotaWatt can run indefinitely without WiFi. 
If you are logging to Emoncms or another server, 
that will be suspended, but IotaWatt will recognize 
when the WiFi connection is restored, 
change the led to dull green, 
and send all of the data that it was unable to send during the outage.

To determine if IotaWatt is connected to the WiFi network, 
try to run the IotaWatt app from a browser on a device that 
is connected to the same WiFi network. 
If it works, the problem was probably the real time clock. 

If the app doesn't start, there is a problem with the WiFi connection. 
To be sure, restart the IotaWatt by disconnecting the 5VDC power momentarily 
and then observe the led during startup. 
Follow the troubleshooting guide for led indications during startup.

Not Illuminated
---------------

Under virtually all circumstances, the led should be illuminated. 
If not, the most probable cause is that there is no 5VDC supply. 
The power supply may be faulty or the USB plug may not be inserted all the way.
Check these things first. Try unplugging the 5VDC USB supply and reconnecting. 
Try a different 5VDC supply if available. If all else fails, a more serious 
problem with the device must be considered. 
Consult the supplier or someone who can troubleshoot electronic the hardware.

Continuous Red-Green-Red-Green.....
-----------------------------------

Downloading new firmware release. 
Updates are published from time to time and most IotaWatt subscribe 
to an auto-update class for which the current release may change. 
When a new release becomes available, 
the device initiates a download of a large file that contains 
all of the elements of the new release. 
The download usually takes about 5-6 seconds, but can take longer. 
While the download is in progress, the IoTaWatt does nothing else 
and will blink the led RED-GREEN continuously. 
At the completion of the download, 
the release will be installed and your IoTaWatt will restart. 
The entire process should never take more than a minute.

Led Sequences
-------------

red-green-green
^^^^^^^^^^^^^^^

IoTaWatt is having trouble connecting to the WiFi network. 
If this is a new IoTaWatt, or the network has changed, 
you will need to specify a new network. 
Otherwise, wait several minutes and the LED pattern 
should change to a new code. Follow the advice for that code.

red-green-red
^^^^^^^^^^^^^

A corrupted datalog (current or history) has been discovered. 
The file is being scanned from beginning top end and a diagnostic 
file will be created. This can take an hour or more for large logs. 
Allow to run to completion, after which the damaged log will be 
deleted and a new log created.

red-red-green
^^^^^^^^^^^^^

The configured WiFi network is unavailable and the real-time-clock 
is not running. IoTaWatt can run without WiFi, 
but it cannot accumulate log data if it doesn't know what time it is, 
and it sets the real-time-clock from the internet. 
Determine the problem with your WiFi network or connect to a new network.

green-red-red
^^^^^^^^^^^^^

IoTaWatt is having trouble accessing the SDcard inside the device. 
This typically happens during a restart of the device. 
You will need to power off the device and open it up by 
removing the four screws located under the rubber feet. 
Check that the SDcard is firmly seated in the socket and retry.

If problem persists, your card may have failed. 
You can try to insert the card into a computer that accepts SD 
cards to see if it can be read. If so, the problem is probably 
the IoTaWatt SD card socket and the device will need to be replaced. 
The good news is that the card should work in a replacement device 
and pick up where you left off with all historical data intact.

If your card cannot be read by another device, it is probably 
the card itself. Unfortunately, these things do fail from time-to-time. 
To be sure, insert any other available SDcard and try to restart. 
If the error indication changes to something else, it is probably 
a failure of the SDcard. Sadly, you will need to obtain a new 
one and initialize it with the files that are in the SD directory 
of the GitHub project. All historical data is lost and you will 
need to reconfigure the device as if were new.

red-red-red
^^^^^^^^^^^

This is a catch-all panic code, where the firmware has detected a 
situation that should not happen, or is impossible to deal with. 
Possibly there will be some diagnostic clues in the message log, 
or it may require connecting a serial terminal to the USB port 
to obtain further diagnostics. Problems in this category are beyond 
the scope of this document.

green-red-red-red
^^^^^^^^^^^^^^^^^

The config.txt file was not found on the SDcard.  Possibly
the SDcard has been damaged, or the file was inadvertently
deleted.  The card must be removed, examined in another 
computer, and a new config.txt file provided.

green-red-red-green
^^^^^^^^^^^^^^^^^^^

The config.txt file format is invalid (not valid Json)
and could not be used.  This could be the result of
editing the file improperly, or an error in saving the
configuration.  It may be possible to repair the file 
by mounting the SDcard in another computer and using
a Json linter to find the errors.  Otherwise, it may 
be necessary to replace the config.txt file.

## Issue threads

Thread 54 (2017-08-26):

No mesurement restart after disconnect/reconnect of VT

promy, 2017-08-26:
Using:
- hardware version 4.2 (modified to through-hole and 3 VT channels)
- firmware version 2.02.15 (compiled from source only change is disabled auto-update)
Problem:
When disconnection the VT and reconnection it afterwards (or starting without the VT connected and plugging it in after boot) the measurements do not (re)start.
Only know solution is to cut the usb power.

I tried this 12 times in a row and 12 fails.
The first 10times i waited until VT reading hit 0 before reconnection. last 2 times i unplugged it for 2 - 5 seconds (before VT reading hit 0).

boblemaire, 2017-09-12:
@promy Is this still a problem or did it go away with the better USB power?

promy, 2017-09-12:
Sorry. Did forget to close this. It was solved with a more powerfull usb power. I havent had it again.

promy, 2017-09-12:
Sorry. Did forget to close this. It was solved with a more powerfull usb power. I havent had it again.

Closed 2017-09-12.

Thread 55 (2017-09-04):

PCB / Gerber files

nikwest, 2017-09-04:
Hi Bob,

I love the work you have put into this and I'd like to build your board for myself. I was wondering if you could make PCB layouts available? I only could find the schematics.

Cheers
Dominik

boblemaire, 2017-09-12:
@nikwest Sorry, no plans to publish board layout at this time. Will try to keep schematic up to date as I make changes.

Closed 2017-09-12.

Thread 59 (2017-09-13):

Restart Loop after shutdown/unplug Exception(3)

promy, 2017-09-13:
I unplugged my homebrew IotaWatt (unplug usb + 1 of the VT's).
Then i reconnected them, but with a splitter for the unplugged VT (connected to a second IotaWatt).
When rebooting the first IotaWatt kept flashing a red led.
On the usb-serial it stated a restart Exception (3). (see below).
However, putting in the sd card from the second one (a fresh copy) it booted without any problems. The second IotaWatt also gets in a restart loop with the sd card from the first.
Can it be that there was something corrupted? If so can this be prevented? (I unplugged it like 50times before without any problems. Only change was that now it was logging to emoncms.

The software is v2.02.15

The serial printout:
-------------------
** Restart **

Serial Initialized
No clock yet: SPI started.
No clock yet: SD initialized.
9/13/17 16:10:22 Real Time Clock is running. Unix time: 1505319022
9/13/17 16:10:22 Version: 2.02.15
9/13/17 16:10:22 Reset reason: Exception
9/13/17 16:10:22 Trace: 22128,37663,65378,32126,58124,57973,65413,44090,57159,48009,58697,6430,43023,45438,62294,649,59239,15433,15082,48132,35685,58884,26926,47677,44765,34633,47799,34911,38189,42638,62136,37845
9/13/17 16:10:22 ESP8266 ChipID:763523

Exception (3):
epc1=0x401003e9 epc2=0x00000000 epc3=0x00000000 excvaddr=0x4000dfa1 depc=0x00000000

ctx: cont
sp: 3fff39b0 end: 3fff3d80 offset: 01a0

>>>stack>>>
3fff3b50:  00000010 3fff3bf0 3fff3bf0 3fff2c78
3fff3b60:  00000010 3fff3bf0 00000000 00000008
3fff3b70:  00000000 3fff6ef8 3fff3bf0 401004d8
3fff3b80:  3fff5401 00000000 3fff3bf0 40217c24
3fff3b90:  00000010 3fff3bf0 3fff3bf0 40203b90
3fff3ba0:  3fff6ed4 00000008 3fff3bf0 40217033
3fff3bb0:  3fff2c78 00000005 3fff3bf0 40217065
3fff3bc0:  3fff1ea8 00000000 3fff3bf0 4021716c
3fff3bd0:  3ffe8c48 00000000 3fff6eec 3fff53f4
3fff3be0:  3fff1ea8 00000000 3fff6eec 402074a7
3fff3bf0:  3fff45a4 0000000f 00000008 3fff6ed4
3fff3c00:  0000000f 00000008 3fff6ebc 0000000f
3fff3c10:  00000008 00000000 00000000 3ff00000
3fff3c20:  3fff5fec 3fff6ef8 3fff53e0 40203554
3fff3c30:  3fff5668 3ffe8ce4 3ffe8cf4 0000000f
3fff3c40:  3fff5668 3ffe8ce4 3ffe8cf4 40207d47
3fff3c50:  3fff5668 3ffe8ce4 00000000 0000000a
3fff3c60:  666e6f63 742e6769 00007478 00000000
3fff3c70:  3fff4b34 3ffe9ce8 00000000 000003e8
3fff3c80:  00000000 666e6f63 742e6769 00007478
3fff3c90:  00000000 00000000 3ffe9600 3fff160a
3fff3ca0:  3fff5d64 00001000 3fff5668 3ffe8ce4
3fff3cb0:  00000000 00000015 00000015 4010020c
3fff3cc0:  3fff464c 0000000f 0000000a 4010068c
3fff3cd0:  3fff5640 3fff4ec4 3fff4b34 3fff6e2c
3fff3ce0:  0000000e 3fff6e20 3ffe8f5c 402063ae
3fff3cf0:  00000000 00000000 00000000 3fff25e4
3fff3d00:  3fff2c7c 00000001 3fff2ab8 40208ffc
3fff3d10:  00000000 00000000 00000000 feefeffe
3fff3d20:  feefeffe feefeffe feefeffe feefeffe
3fff3d30:  feefeffe feefeffe feefeffe feefeffe
3fff3d40:  feefeffe feefeffe feefeffe feefeffe
3fff3d50:  feefeffe feefeffe feefeffe 3fff2d58
3fff3d60:  3fffdad0 00000000 3fff2d51 40217d44
3fff3d70:  feefeffe feefeffe 3fff2d60 40100718
<<<stack<<<

 ets Jan  8 2013,rst cause:2, boot mode:(3,6)

load 0x4010f000, len 1384, room 16
tail 8
chksum 0x2d
csum 0x2d
v60000318
~ld
…
------------------------------------------

promy, 2017-09-13:
update:
it seems that
- deleting everything in the IotaWatt dir solved the problem
- unplugging it again recreated the problem? COuld the problem be in unplugging it while updating emoncms?

boblemaire, 2017-09-15:
There are a lot of moving parts to this issue.  There is a new VT splitter.  There are two IotaWatt devices.  There is a sequence of events that contains what you think is relevant but doesn't answer a bunch of questions that I would have in taking a methodical approach to the problem.  But the underlying question that you ask is could the problem be in unplugging it while updating Emoncms?

The answer is sure it could.  But more importantly, removing and reinserting the SDcard can and DOES cause corruption of the SDcard.  It's not meant to be removed.  If it is, the device should be powered off before reinserting.  There are no GPIO pins available to sense when the card is removed, so IotaWatt does not know it needs to close files and reinitialize the SD.  There is an operating system on the SDcard that is keeping track of unused blocks, and the context of the file system in the SD class instance has no idea that files have been modified externally.

I'm going to close this as it lacks information sufficient to recreate and involves procedures that are outside of the designed operation of the device (removal of the SD).  By all means, if you can resolve these issues, feel free to ask again.

Closed 2017-09-15.

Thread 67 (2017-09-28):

Allow negative power value not remembered

promy, 2017-09-28:
Problem found in old index.htm - to be closed

Closed 2017-09-28.

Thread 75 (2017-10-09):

Share IoTaWatt schematics

skabashnyuk, 2017-10-09:
It would be nice if you can share not only images but eagle or gerber schematics of the board.
Ideally it should be.
- schema
- board
- gerber
- BOM

flywire, 2017-10-09:
I think it is still this one:
https://github.com/boblemaire/IoTaWatt/blob/c0bb95f096adf0cbdddb9c2e1ff9c784bcd33448/Hardware/IotaWatt4.3.sch

IotaWatt
Electric Power Monitor
Version 4.1
July 6, 2017

Picture of PCB is labelled:
IoTaWatt
Rev 4.3

skabashnyuk, 2017-10-09:
Awesome. Would you like me to create a PR to add this file in https://github.com/boblemaire/IoTaWatt/tree/master/Hardware folder?
BTW I can maintain Gerber file too.

skabashnyuk, 2017-10-09:
@flywire Silly question. What about IotaWatt4.3.brd file? Can you share it too?

boblemaire, 2017-10-09:
I'm looking into issues surrounding licensing and managing the feedback that comes from independent efforts to build this.  While it may seem a simple matter to just post the .brd file, to be useful the parts libraries, BOM etc.  need to be included.  Right now I am overwhelmed with software issues related to supporting the initial OEM offering.

skabashnyuk, 2017-10-09:
I can help with bom if you want to. For instance we can start with:
```
Qty Value                Device               Package        Parts                                                               Description                                                                      
4   .1uf                 C-USC0805            C0805          C3, C4, C5, C6                                                      CAPACITOR, American symbol                                                       
2   10uF                 C-USC0805            C0805          C7, C9                                                              CAPACITOR, American symbol                                                       
2   10uf                 C-USC0805            C0805          C1, C2                                                              CAPACITOR, American symbol                                                       
1   12K                  R-US_R0805           R0805          R32                                                                 RESISTOR, American symbol                                                        
3   1K                   R-US_R0805           R0805          R3, R29, R31                                                        RESISTOR, American symbol                                                        
1   2.1MMJACKSMT         2.1MMJACKSMT         DCJACK_2MM_SMT J0                                                                  2.1mm x 5.5mm THM DC jack with internal switch. Digikey part #PJ-102A, 4UCON part #05537
14  24                   R-US_R0805           R0805          R8, R12, R16, R20, R24, R28, R36, R40, R44, R48, R52, R56, R57, R58 RESISTOR, American symbol                                                        
1   32Khz                CRYSTAL8X3.8SMT      CRYSTAL_8X3.8  Y1                                                                  Crystals                                                                         
2   4.7K                 R-US_R0805           R0805          R1, R2                                                              RESISTOR, American symbol                                                        
1   470                  R-US_R0805           R0805          R4                                                                  RESISTOR, American symbol                                                        
1   CR1220SMD            CR1220SMD            CR1220SMD      U$18                                                                CR1220 Battery SMD                                                               
2   LED_RT_TRH           LED_RT_TRH           LED_TH_RT      U$15, U$23                                                          LED RT ThruHole BiColor Digikey 67-2237-ND                                       
1   LM358_DUAL_OP-AMP    LM358_DUAL_OP-AMP    SOIC_8         U$22                                                                LM358 Dual Op-Amp - SOIC8                                                        
2   MCP3208              MCP3208              SOIC_16        MCP3208-0, MCP3208-1                                                MCP3208 12bit SPI ADC                                                            
1   MICROSD_PUSH/PULL    MICROSD_PUSH/PULL    MICROSD        MICROSD                                                             McroSD Amphenol push/pull                                                        
1   NODEMCU              NODEMCU              NODEMCU        U$16                                                                NodeMCU 1.0 ESP8266                                                              
1   PCF8523_RTC          PCF8523_RTC          SOIC_8         PCF8523                                                             PCF8523-RTC SOIC-8                                                               
14  STEREO_SMD           STEREO_SMD           STEREO_SMT     J1, J2, J3, J4, J5, J6, J7, J8, J9, J10, J11, J12, J13, J14         3.5mm Stereo Jack SMT                                                            
4   TVS_4CHAN_ARRAYSC-74 TVS_4CHAN_ARRAYSC-74 SC-74          U$17, U$19, U$20, U$21                                              TVS 4 channel array                                                              
1   VREF_SHUNT           VREF_SHUNT           SOT23_3        ADR510                                                              Voltage Reference Shunt - SOT23-3 (ADR504, etc.)                                 
```
or match it with https://octopart.com/ database. What is your vision for how it should looks like?

skabashnyuk, 2017-10-09:
@flywire @boblemaire direct question guys. Actually related to https://github.com/boblemaire/IoTaWatt/issues/74 : are you going to allow third-party contributors to manufacturing your board according to your PCB design? For home use? For commercial use? Or it's more proprietary product?

boblemaire, 2017-10-09:
Right now I am overwhelmed with software issues related to supporting the initial OEM offering.

flywire, 2017-10-10:
Good to see ‘soft’ community launch today.

On 18 September 2017 this schematic was posted:
https://github.com/boblemaire/IoTaWatt/blob/952609b34bc0bb3d88239f9fcf429b88e060000f/Hardware/IotaWatt4.3.sch
IotaWatt
Electric Power Monitor
Version 4.3
August 14, 2017

The schematic_4.3.png loaded the following day has the text
IotaWatt
Electric Power Monitor
Version 4.1
July 6, 2017
I suspect Version 4.1 was incorrectly loaded as schematic_4.3.png

glynhudson, 2017-10-10:
> I suspect Version 4.1 was incorrectly loaded as schematic_4.3.png

Thanks for letting us know, I've created a PR to fix this. I think the current schematic is actually correct just incorrectly labelled. Anyway it will be corrected once PR is merged.

https://github.com/boblemaire/IoTaWatt/pull/77

CAD files are being prepared will be shared under open-source licence very soon.

boblemaire, 2017-10-17:
Eagle files have been added.  The license speaks for itself.

Closed 2017-10-17.

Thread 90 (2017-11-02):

How do you configure an input for a load that uses both phases but only a single CT

Frogmore42, 2017-11-02:
In the US we have 240 split phase power.  For 240V only loads (pumps, water heater, AC compressor would be examples) only a single CT is needed, since the neutral is not used.  This means that the actual power/energy used is twice what is measured.  I found the Outputs screen, which lets me create something that represents the total power by multiplying the measure power by 2.  But, I did not see a way to do this for the energy.

boblemaire, 2017-11-02:
They are the same, but the graph app does not list the outputs under the energy tab. I have added that but the changes are not yet merged into a release.  I’ll put that out soon and mark this closed when I do.

As an aside, I too am on the US power system, and when I can, I resolve those 240 connections by passing both leads through the CT, one in the opposite direction.  This works well on those devices that use the neutral for 120 volt, and also doubles the current, which gives it more resolution at low values.  It requires a CT rated for double the current the current the device uses, and sometimes the box and wire length won’t accommodate, but it’s a consideration.  What you have done is fine as well.
 One that if you upload to EmonCMS or another server, you can use the calculator to double the value there as well, so you won’t need to do that in the input process list.

Frogmore42, 2017-11-03:
I found another solution too.  I just added a new entry to tables.txt that was the same CT with a x2 added to the name and then doubled the turns value.  That appears to double the output value and everything works normally without needing to create another feed.

boblemaire, 2017-11-03:
If that works for you.  I don’t recommend to anyone else relying on modifications to the table file.  The table file is distributed with each new release and user changes will be gone.

Closed 2017-11-03.

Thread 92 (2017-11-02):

dependency ESP8266WiFi

promy, 2017-11-02:
I would like to continue to compile the source with the arduino IDE.
Could you point me to the version of the lib you used? I'm getting compile errors with the "old" one (before 02.22.22)

With the PlatformIO i'm als getting a similar error:

Project
Firmware
IotaWatt
lib
.gitignore
.travis.yml
platformio.ini
Welcome Guide
PlatformIO Home
127.5 s
platformio run
Compiling .pioenvs\iotawatt\src\IotaWatt.ino.o
Compiling .pioenvs\iotawatt\src\Loop.o
Compiling .pioenvs\iotawatt\src\Setup.o
Compiling .pioenvs\iotawatt\src\WiFi.o
Compiling .pioenvs\iotawatt\src\dataLog.o
In file included from C:\users\promy\.platformio\packages\framework-arduinoespressif8266\libraries\ESP8266WiFi\src/ESP8266WiFi.h:39:0,
from IotaWatt\IotaWatt.h:30,

from IotaWatt\GetFeedData.cpp:1:
C:\users\promy\.platformio\packages\framework-arduinoespressif8266\libraries\ESP8266WiFi\src/WiFiClient.h: In instantiation of 'size_t WiFiClient::write(T&, si
ze_t) [with T = char*; size_t = unsigned int]':
IotaWatt\GetFeedData.cpp:251:40:   required from here
C:\users\promy\.platformio\packages\framework-arduinoespressif8266\libraries\ESP8266WiFi\src/WiFiClient.h:123:36: error: request for member 'available' in 'sou
rce', which is of non-class type 'char*'
size_t left = source.available();
^
C:\users\promy\.platformio\packages\framework-arduinoespressif8266\libraries\ESP8266WiFi\src/WiFiClient.h:127:5: error: request for member 'read' in 'source',
which is of non-class type 'char*'
source.read(buffer.get(), will_send);
^
Compiling .pioenvs\iotawatt\src\eMonService.o
Compiling .pioenvs\iotawatt\src\getConfig.o
*** [.pioenvs\iotawatt\src\GetFeedData.o] Error 1
 [ERROR] Took 126.65 seconds

promy, 2017-11-02:
Fixed for the IDE by completely reinstalling it and adding the esp board manager...

Closed 2017-11-02.

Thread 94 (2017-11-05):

Question:  U$3  VREF_SHUNT model

skabashnyuk, 2017-11-05:
Could you please identify the model of this shunt?
Is this https://octopart.com/search?q=ADR5045A ? Voltage 5.0?

boblemaire, 2017-11-05:
I'm currently using TL4050B25IDBZR (Texas Instruments).  That said any SOT-23-3 shunt with a voltage less than 3.2V will work.  The over all accuracy of the device is based on this component, so I use a 0.2% tolerance.  Whatever you use, the default voltage in the software is 2.5V but that can be changed, either in the software or specified in the configuration file.

Closed 2017-11-05.

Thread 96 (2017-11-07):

Component Quality

Roo-2, 2017-11-07:
#94
> The over all accuracy of the device is based on this component, so I use a 0.2% tolerance.

Can you give sample part numbers for C0805 (1uf & 10uf) and R0805 (220R, 24R, 1K, 4.7K & 12K) packages?

What is quality of Chinese NodeMCU?

boblemaire, 2017-11-07:
Resistors are mostly .5% 1/10watt.  Capacitors are garden variety.
What is quality of Chinese NodeMCU?  I am not aware of any metric or standard by which the relative quality of this open hardware commodity is measured.

Roo-2, 2018-01-31:
[https://community.iotawatt.com/t/resistor-tolerance/23](url)

Closed 2017-11-07.

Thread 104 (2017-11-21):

Future Feature Request:  Add a shutdown or pseudo shutdown command.

JonMurphy, 2017-11-21:
It seems like the iotawatt is writing lots of data to the SD card.  So powering down the iotawatt could cause a file corruption or a SD card corruption.

From digging thru the ESP docs I didn't find a shutdown command (but I could be blind!).  So I am hoping a pseudo shutdown command could be created by turning off abilities to write to the SD card, turn off interrupts (if used), and putting the iotawatt into a continue loop or to sleep until powered down.

boblemaire, 2017-12-08:
In reality, IoTaWatt writes to the SD card once every 5 seconds, and to the extent possible, precautions to minimize the probability of file corruption have been taken.  Also, the data log as now has a low resolution (2 min) backup in the history log.

The latest release has a software restart to eliminate power cycle type restarts.  So this change would not do anything to mitigate the only remaining exposure to potential SD card corruption, which is unanticipated power failure.

Closed 2017-12-08.

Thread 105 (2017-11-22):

Feature request:  Add Help Page to each tab

JonMurphy, 2017-11-22:
Add a help page link 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 with link to wiki for each tab.
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
This "circle ?" in the bottom right corner would point to:
https://github.com/boblemaire/IoTaWatt/wiki/Device-Configuration

Icon Link: https://www.flaticon.com/free-icon/question-mark-inside-a-circle_827

PS - I know your TO-DO list is long.  I'd be happy to help.  If you show me how to do one tab I can figure out the rest and do the needed push requests.

boblemaire, 2018-01-15:
Jon,
I'm interested in doing this, but I'd like to avoid linking to an external image for the icon.  Do you think you can source an embedded base64 image to use?

JonMurphy, 2018-01-17:
I think the link I sent had the ability to do a embedded base64 image (without linking an external image).  I'll read thru it again.

glynhudson, 2018-01-17:
Good idea Jon

- sent from my mobile device

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

JonMurphy, 2018-01-17:
To me this doesn't look linked.  Here is the Base 64 encoded image (HTML):

```
<img src="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" />
```

From the License it looks like the author is looking for a mention.  Maybe this could be your **About** page or a **Credits** page.
> Icon made by Freepik from www.flaticon.com

There is a license PDF on the site.  You'd have to answer if it meets their terms & conditions.

boblemaire, 2018-01-17:
Yeah, I looked at it.  That's why I asked if you would source the symbol.  I'm not going to add code to comply with the copyright for a question mark in a circle.  I don't blame the guy for wanting it, I just don't think it's worth the trouble. I'd just as soon put a little button there with the work Wiki,  Probably that's what I'll do when I get around to it.

boblemaire, 2018-06-11:
With no activity on this for many months, I'm going to close it.  I have added HTML titles to many of the items in the menus, and also added some pretty long explanations in some of the menus.  The WiKi is going to be converted to read-the-docs soon.

Closed 2018-06-11.

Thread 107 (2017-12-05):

BOM/Part Library

warren-woolsey, 2017-12-05:
Would it be possible to get a BOM or Part Library to go along with the Eagle Files?

boblemaire, 2017-12-05:
I believe the part information contained in the Eagle files is accurate.  The only issue might be the VREF-shunt which is an sot23-3 2.5V .2% shunt, generally available from major suppliers.
It just increases my work and opens the door for more error if I maintain something separate from the Schematics.

warren-woolsey, 2017-12-06:
It would be simple to just drop a copy of the Library file for the board when you drop a copy of the schematic and board files. This would give us access to the list of the actual parts used, rather than just making a best guess from the descriptions.

bgupta55, 2017-12-06:
I agree. I am from India, having tough time to procure following components :

1. LED_RT_TRH - (LED RT ThruHole BiColor Digikey 67-2237-ND) - looks like only available on digikey, and shipping to India is expensive.

2. 3.5mm Stereo Jack SMT - looks like only available on digikey, and shipping to India is expensive.

3. TVS 4 channel array

I am not able to find these in local market, as well as on aliexpress.

Request you to please suggest.

Thanks.

warren-woolsey, 2017-12-26:
I'm having issues with the Stereo Jacks my self.

namezero, 2018-01-01:
the Sereo jack reference is  CP-3524SJTR-ND right ?
--

mattncsu, 2018-01-17:
I put together this BOM.  Has everything but the ESP. No guarantee it is accurate, complete, or the same parts @boblemaire used.  I just put it together to get a quick estimate of the cost to build an iotaWatt vs emontx/emontx shield/emonpi boards. https://octopart.com/bom-tool/C2JyOqfc

erice1984, 2019-01-16:
Tkfu marking on vref shunt which identifies as a TL4050.  I belive the tvs diodes are these D5V0P4UR6SO-7.

boblemaire, 2019-01-16:
TL4050B25IDBZR‎ but any SOT23-3 shunt 3V or less should work.  The firmware assumes 2.5V but can overide in the config and soon in the EEPROM at manufacture.  I use 0.2% tolerance.

Closed 2019-01-16.

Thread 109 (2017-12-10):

ESP32 update

gesaleh, 2017-12-10:
Hi
I would like to help on the ESP32 update
what is the status ? are you going to have WiFi or BLE active ?
I have several ESP32 boards ready to be integrated contact me to see how we can work together if needed

Thanks

Onepamopa, 2017-12-10:
Should be option for both BLE or Wi-Fi, user's choice.

boblemaire, 2017-12-14:
It's a complete rewrite.  The opportunities that are presented with the ESP32 would be difficult to exploit effectively within the framework of the ES8266 version.  Specifically, I want to use the multi-processor resource optimally.  So it's looking like an enhanced scheduler with maybe the sampling happening on a dedicated processor.  It's all still very vague.  I'm trying to get some experience with it.

Onepamopa, 2018-03-20:
So, are we gonna see an ESP32 version or we should forget about it?

boblemaire, 2018-03-23:
I would say it's a long way off.  There are two issues:
1) This ESP8266 version is taking off and I have a lot to do on it yet (that should be portable to an ESP version)
2) Last time I checked there was no TLS or SSL support in the asyncTCP for the ESP32.  I'm not using it in the ESP8266 either, but if I'm going to port, I'll go the extra distance to move to a platform that offers better security options.

Closed 2018-01-15.

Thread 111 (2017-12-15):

Feeds missing from version of software

rosspeel, 2017-12-15:
Been away for a few days and went to check the graphs on my solar output and looks like a new version of software has been updated, but now it seems that my feeds has disappeared on my graphs
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

Frogmore42, 2017-12-15:
Refresh a few times and go back to the main page.  I did that a few times and the feeds magically showed up.

boblemaire, 2017-12-15:
The newer release includes updated versions of the apps, including the configuration and graph app.  To make sure you are running the latest versions, please close your browser windows and start fresh with the config app (iotawatt.local).  Then run the graph from there.  If you still do not have feeds, check the status page.  Make sure you the device is updating status.  Click on the Data Logs tab and post a screenshot of the status.

rosspeel, 2017-12-16:
Have rebooted and refresh many times from different PCs but still no graphs to be found, have taken screenshots of status page and graph page
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

boblemaire, 2017-12-16:
OK, that looks pretty busy.  Can you enter this url:

http://iotawatt.local/feed/list.json

and post the result?

boblemaire, 2017-12-16:
I think this has something to do with spaces in the output channel names.  I notice the calculator indicates such a name is invalid but allows SAVE.  That's something that must be fixed.  Also, your prior release probably allowed it and worked fine.  The API was changed to use the names rather than a numeric token so that it could be useful to other applications.
I see that you have a lot invested in naming a lot of outputs.  Could you try using underscores in all of them as in the input names?

rosspeel, 2017-12-16:
list.jason

[{"id":"IVVoltage","tag":"Voltage","name":"Voltage"},{"id":"IPImport_Export","tag":"Power","name":"Import_Export"},{"id":"IEImport_Export","tag":"Energy","name":"Import_Export"},{"id":"IPSolar_East_5000w","tag":"Power","name":"Solar_East_5000w"},{"id":"IESolar_East_5000w","tag":"Energy","name":"Solar_East_5000w"},{"id":"IPSolar_West_5000w","tag":"Power","name":"Solar_West_5000w"},{"id":"IESolar_West_5000w","tag":"Energy","name":"Solar_West_5000w"},{"id":"IPSolar_W_and_N_With_Bat_4900w","tag":"Power","name":"Solar_W_and_N_With_Bat_4900w"},{"id":"IESolar_W_and_N_With_Bat_4900w","tag":"Energy","name":"Solar_W_and_N_With_Bat_4900w"},{"id":"IPTotal_Solar_Produced","tag":"Power","name":"Total_Solar_Produced"},{"id":"IETotal_Solar_Produced","tag":"Energy","name":"Total_Solar_Produced"},{"id":"IPHot_Water_House","tag":"Power","name":"Hot_Water_House"},{"id":"IEHot_Water_House","tag":"Energy","name":"Hot_Water_House"},{"id":"IPHouse_Heating_Cooling","tag":"Power","name":"House_Heating_Cooling"},{"id":"IEHouse_Heating_Cooling","tag":"Energy","name":"House_Heating_Cooling"},{"id":"IPShed_Power_A","tag":"Power","name":"Shed_Power_A"},{"id":"IEShed_Power_A","tag":"Energy","name":"Shed_Power_A"},{"id":"IPShed_Power_B","tag":"Power","name":"Shed_Power_B"},{"id":"IEShed_Power"},{"id":"IEHouse_Outdoor_Power","tag":"Energy","name":"House_Outdoor_Power"},{"id":"IPShed_32Amp_Outlet","tag":"Power","name":"Shed_32Amp_Outlet"},{"id":"IEShed_32Amp_Outlet","tag":"Energy","name":"Shed_32Amp_Outlet"},{"id":"OPHeating and Cooling","tag":"Power","name":"Heating and Cooling"},{"id":"OEHeating and Cooling","tag":"Energy","name":"Heating and Cooling"},{"id":"OPHouse General","tag":"Power","name":"House General"},{"id":"OEHouse General","tag":"Energy","name":"House General"},{"id":"OPHouse Hot Water","tag":"Power","name":"House Hot Water"},{"id":"OEHouse Hot Water","tag":"Energy","name":"House Hot Water"},{"id":"OPImport Export","tag":"Power","name":"Import Export"},{"id":"OEImport Export","tag":"Energy","name":"Import Export"},{"id":"OVMains Voltage","tag":"Voltage","name":"Mains Voltage"},{"id":"OPNBN Outdoor Box","tag":"Power","name":"NBN Outdoor Box"},{"id":"OENBN Outdoor Box","tag":"Energy","name":"NBN Outdoor Box"},{"id":"OPSelf Use","tag":"Power","name":"Self Use"},{"id":"OESelf Use","tag":"Energy","name":"Self Use"},{"id":"OPShed 32 Amp Outlet","tag":"Power","name":"Shed 32 Amp Outlet"},{"id":"OEShed 32 Amp Outlet","tag":"Energy","name":"Shed 32 Amp Outlet"},{"id":"OPShed A Circuit","tag":"Power","name":"Shed A Circuit"},{"id":"OEShed A Circuit","tag":"Energy","name":"Shed A Circuit"},{"id":"OPShed B Circuit With Pump","tag":"Power","name":"Shed B Circuit With Pump"},{"id":"OEShed B Circuit With Pump","tag":"Energy","name":"Shed B Circuit With Pump"},{"id":"OPShed Lighting","tag":"Power","name":"Shed Lighting"},{"id":"OEShed Lighting","tag":"Energy","name":"Shed Lighting"},{"id":"OPShed Rear Box","tag":"Power","name":"Shed Rear Box"},{"id":"OEShed Rear Box","tag":"Energy","name":"Shed Rear Box"},{"id":"OPSolar Bulk Production","tag":"Power","name":"Solar Bulk Production"},{"id":"OESolar Bulk Production","tag":"Energy","name":"Solar Bulk Production"},{"id":"OPSolar East Production","tag":"Power","name":"Solar East Production"},{"id":"OESolar East Production","tag":"Energy","name":"Solar East Production"},{"id":"OPSolar North Production","tag":"Power","name":"Solar North Production"},{"id":"OESolar North Production","tag":"Energy","name":"Solar North Production"},{"id":"OPSolar West Production","tag":"Power","name":"Solar West Production"},{"id":"OESolar West Production","tag":"Energy","name":"Solar West Production"}]

rosspeel, 2017-12-16:
I see that you have a lot invested in naming a lot of outputs. Could you try using underscores in all of them as in the input names?

Yes i have been using underscores in names
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

rosspeel, 2017-12-16:
message log

12/16/17 10:29:11 MDNS responder started
12/16/17 10:29:11 You can now connect to http://IotaWatt.local
12/16/17 10:29:11 HTTP server started
12/16/17 10:29:12 dataLog: service started.
12/16/17 10:29:12 dataLog: Last log entry:1513384145
12/16/17 10:29:12 statService: started.
12/16/17 10:29:12 timeSync: service started.
12/16/17 10:29:12 WiFi connected. SSID: Rosshouse AP, IP: 192.168.50.102
12/16/17 10:29:13 historyLog: service started.
12/16/17 10:29:13 historyLog: Last log entry:1513384140
12/16/17 10:29:17 EmonService: started.url: emoncms.org:80, node: Peel, post interval: 10, encrypted POST
12/16/17 10:29:17 EmonService: Start posting at 1513265360
12/16/17 10:29:26 EmonService: POST failed. HTTP code:read Timeout
12/16/17 10:30:26 EmonService: Resending EmonCMS data:2
12/16/17 10:32:27 EmonService: Resending EmonCMS data:3
12/16/17 10:35:28 EmonService: Resending EmonCMS data:4
12/16/17 10:39:30 EmonService: Resending EmonCMS data:5
12/16/17 10:44:32 EmonService: Resending EmonCMS data:6
12/16/17 10:50:33 EmonService: Resending EmonCMS data:7
12/16/17 10:57:34 EmonService: Resending EmonCMS data:8
12/16/17 11:05:35 EmonService: Resending EmonCMS data:9
12/16/17 11:14:37 EmonService: Resending EmonCMS data:10
12/16/17 11:14:38 EmonService: Unable to post to Emoncms after 10 retries.  Restarting ESP.

** Restart **

No clock yet: SD initialized.
12/16/17 01:14:39 Real Time Clock is running. Unix time: 1513386879
12/16/17 01:14:39 Version: 02_02_27
12/16/17 01:14:39 Reset reason: Software/System restart
12/16/17 01:14:39 Trace: 99,12,13,14,15,16,17,18,13,14,15,16,17,18,13,14,15,30,37,38,148,149,140,142,143,144,145,148,149,146,147,39
12/16/17 01:14:39 ESP8266 ChipID:416947
12/16/17 11:14:39 device name: IotaWatt, version: 3
12/16/17 11:14:39 Local time zone: 10
12/16/17 11:14:42 MDNS responder started
12/16/17 11:14:42 You can now connect to http://IotaWatt.local
12/16/17 11:14:42 HTTP server started
12/16/17 11:14:42 dataLog: service started.
12/16/17 11:14:43 dataLog: Last log entry:1513386875
12/16/17 11:14:43 statService: started.
12/16/17 11:14:43 timeSync: service started.
12/16/17 11:14:43 WiFi connected. SSID: Rosshouse AP, IP: 192.168.50.102
12/16/17 11:14:43 historyLog: service started.
12/16/17 11:14:44 historyLog: Last log entry:1513386840
12/16/17 11:14:47 EmonService: started.url: emoncms.org:80, node: Peel, post interval: 10, encrypted POST
12/16/17 11:14:47 EmonService: Start posting at 1513265360
12/16/17 11:14:55 EmonService: POST failed. HTTP code:read Timeout
12/16/17 11:15:23 Server: Sent less data than expected!
12/16/17 11:15:55 EmonService: Resending EmonCMS data:2
12/16/17 11:16:46 Server: Sent less data than expected!
12/16/17 11:17:56 EmonService: Resending EmonCMS data:3
12/16/17 11:20:43 Restart command received.

** Restart **

No clock yet: SD initialized.
12/16/17 01:20:44 Real Time Clock is running. Unix time: 1513387244
12/16/17 01:20:44 Version: 02_02_27
12/16/17 01:20:44 Reset reason: Software/System restart
12/16/17 01:20:44 Trace: 14,17,18,13,14,17,18,13,14,17,18,13,14,17,18,13,14,17,18,13,14,17,18,11,90,84,86,88,12,13,102,103
12/16/17 01:20:44 ESP8266 ChipID:416947
12/16/17 11:20:44 device name: IotaWatt, version: 3
12/16/17 11:20:44 Local time zone: 10
12/16/17 11:20:47 MDNS responder started
12/16/17 11:20:47 You can now connect to http://IotaWatt.local
12/16/17 11:20:47 HTTP server started
12/16/17 11:20:48 dataLog: service started.
12/16/17 11:20:48 dataLog: Last log entry:1513387240
12/16/17 11:20:48 statService: started.
12/16/17 11:20:48 timeSync: service started.
12/16/17 11:20:48 WiFi connected. SSID: Rosshouse AP, IP: 192.168.50.102
12/16/17 11:20:49 checkUpdate: Invalid response from server.
12/16/17 11:20:49 historyLog: service started.
12/16/17 11:20:49 historyLog: Last log entry:1513387200
12/16/17 11:20:53 EmonService: started.url: emoncms.org:80, node: Peel, post interval: 10, encrypted POST
12/16/17 11:20:53 EmonService: input/get failed.
12/16/17 11:21:23 EmonService: input/get failed.
12/16/17 11:21:53 EmonService: Start posting at 1513265360
12/16/17 11:22:01 EmonService: POST failed. HTTP code:read Timeout
12/16/17 11:23:02 EmonService: Resending EmonCMS data:2
12/16/17 11:25:03 EmonService: Resending EmonCMS data:3
12/16/17 11:28:04 EmonService: Resending EmonCMS data:4
12/16/17 11:32:05 EmonService: Resending EmonCMS data:5
12/16/17 11:37:06 EmonService: Resending EmonCMS data:6
12/16/17 11:43:07 EmonService: Resending EmonCMS data:7
12/16/17 11:50:08 EmonService: Resending EmonCMS data:8
12/16/17 11:58:10 EmonService: Resending EmonCMS data:9
12/16/17 12:07:11 EmonService: Resending EmonCMS data:10
12/16/17 12:07:12 EmonService: Unable to post to Emoncms after 10 retries.  Restarting ESP.

** Restart **
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

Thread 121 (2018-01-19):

Capture line frequency

blalor, 2018-01-19:
Is it possible to record the actual frequency of the input voltage? This can be used to infer power grid health. It should be close to a base value (like 60Hz), but could vary, and it would be interesting to measure that over time.

boblemaire, 2018-01-22:
IoTaWatt measures frequency, but doesn't record it in the datalog.  That's a lot of data.  There is  presently room in the datalog for an additional set of data points for each channel.  Present thinking is to use that for power-factor, but of course there is no PF for a voltage channel, so maybe it could go there.

Frequency calculation has a resolution of about 0.2% (60Hz) due to the sample rate.  Zero crossing is only checked about every 23us.

The current frequency of channel zero is reported in the status screen to one decimal position. While not plausible, additional VT inputs could be monitoring voltages with different frequencies (line, generator).  You can get that to more precision by issuing the status request API on a regular basis and recording the values yourself or uploading to a server with a bash script or something.  The api is:
`http://iotahome.local/status?stats=yes`
Json output will look something like this:
`{"stats":"cyclerate":642.5326,"chanrate":39.98794,"runseconds":385853,"stack":17928,"version":"02_02_27","frequency":59.99025}}`

Once again, there are a lot of decimal places, but the real accuracy is 2 at best.

Closed 2018-01-22.

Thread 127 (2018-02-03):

own compile - no VT active

promy, 2018-02-03:
I tried to compile and flash this version (with and without the changed samplePower.cpp - version 02-02-29 dd 25/01/2018)
Ran ok, but, it didn't capture the VT's (and as such no power measurements on the CT's i guess), everything stayed on 0. I changed the sd files (all exept the config) but no luck.

Reflashed back to an old version (02-02-26) i had downloaded (and running on another IotaWatt), and this version worked OK (changed the sd files back since with the new sd files this version showed a wrong "ac cycles sampled/second) (5 vs 28)

boblemaire, 2018-02-04:
Not much to go on here.  Not sure what "this" version means when it is "with and without" one of the components.  All I can say is that the released version 02_02_29 is at auto-update MINOR and running without incident.  Can you download and run the firmware binary for 02_02_29?

boblemaire, 2018-02-18:
No further information after 2 weeks, closing this as insufficient information to reproduce.

Closed 2018-02-18.

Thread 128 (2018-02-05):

emoncms on https not working

dtony, 2018-02-05:
I tried to configure IoTaWatt using my own emoncms instance hosted with a valid (Let's Encrypt) SSL certificate but it fail. I have a redirection on my apache reverse proxy to redirect http to https. I could read in the logs :
`2/5/18 13:29:40 EmonService: started.url: emon.mydomain.com:443/emoncms, node: IotaWatt, post interval: 10, unsecure GET`
`2/5/18 13:29:40 EmonService: input/get failed.`
I tried different format for the url :
- https://emon.mydomain.com/emoncms
- https://emon.mydomain.com/emoncms/
- https://emon.mydomain.com:443/emoncms
- https://emon.mydomain.com:443/emoncms
- emon.mydomain.com:443/emoncms

I finally remove the redirection and served emoncms on port 80 with http and then it worked :
`2/5/18 13:42:23 EmonService: started.url: emon.mydomain.com:80/emoncms/, node: IotaWatt, post interval: 10, unsecure GET`
`2/5/18 13:42:23 EmonService: Start posting at 1517834540`

boblemaire, 2018-02-05:
The message doesn't provide a lot of information about the cause of the failure, and that's not always informative anyway.  The "input/get failed" is the initial transaction issued by Emonservice to obtain the time of the last input to Emoncms.  Posting will resume from that point.  That transaction is not secure (although the apikey is somewhat obfuscated in base-64 in a HTTP header).  Once that transaction completes, subsequent data posting can be done using the secure Emoncms post protocol that encrypts the payload.  Not sure of the status rolling that out to the local Emoncms code.

At this point, the only other option I can offer is to use a different port.  You can append a :port to the Emoncms URL during configuration and have your instance serve HTTP on that port.

Currently working on using asyncTCP in IoTaWatt.  There is a lightweight TLS option available there that I intend to explore.  If it can run reliably in the heap available, I will consider supporting HTTPS directly from IoTaWatt.  It's a long shot.  Beyond that, the ESP32 should offer sufficient resources in the future.

Closed 2018-02-05.

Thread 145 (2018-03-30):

Better support for outputs

fredrike, 2018-03-30:
I guess that the aim of the outputs is to follow: https://www.emoncms.org/site/api#feed

I'm missing support for https://iotawatt.local/feed/timevalue.json?id=1 (Last updated time and value for feed)

boblemaire, 2018-04-03:
@fredrike,
The /feed/data API, as well as the /feed/list and a few others, were supported to support the graph application, which is a modified Emoncms graph app.  The version used by IoTaWatt uses a modified feed/data API to better leverage the way data id organized in the datalog.  The graph app has also been modified to make the API requests asynchronous, making the app more responsive.  There is no plan to take this any further.  More likely, the app will be redesigned from the ground up to offer other useful visualizations like solar generation and pie-chart type usage breakdowns.  This is a ways off, as first I'd like to make influx the DB of choice and develop some useful dashboards that can run on the free hosted grafana site.

I don't know much about aRest, but from a glace it looks like something that would need to be compiled in to modify.  That's not how IoTaWatt works, but you are free to fork a branch and have at it.

I take the first comment to be a specific request to add /feed/timevalue to the API list.  Basically, if you can get a response from the IoTaWatt at any particular NTP time, round it down by 5 seconds and that's the time of the last entry in the datalog.  There are no "feeds".  That's an artifact of Emoncms.  IoTaWatt takes a different approach and saves the raw data at 5 second intervals in the datalog.  If it's running, it's logging.

I'm going to close this, but feel free to comment back if you have any questions, or go to the forum to follow up.

fredrike, 2018-04-03:
@boblemaire,

Thanks for getting back to me.
It is a bit confusing that we are able to configure "outputs" but that there is no clear documentation on how to access this information (what endpoints are available for accessing the data).

I did take a look at the Status page and found this endpoint http://iotawatt.local/status?inputs=yes&outputs=yes&stats=yes which returns a nicely formatted json with all inputs and outputs 😄.

So after some more investigation I ended up with this configuration for home-assistant.io. I'm reading the config.txt to display the configured names of the outputs.

```yaml
sensor:
  - platform: rest
    name: iotawatt
    json_attributes:
      - inputs
      - outputs
      - stats
    resource: 'http://iotawatt.local/status?inputs=yes&outputs=yes&stats=yes'
    value_template: '{{ value_json.stats.runseconds }}'
    unit_of_measurement: seconds
  - platform: rest
    name: iotawatt config
    json_attributes:
      - inputs
    resource: 'http://iotawatt.local/config.txt'
    value_template: '{{ value_json.device.name }}'

  - platform: template
    sensors:
      iotawatt_in_1:
        unit_of_measurement: W
        friendly_name_template: '{{ states.sensor.iotawatt_config.attributes.inputs[1].name }}'
        value_template: '{{ states.sensor.iotawatt.attributes.inputs[1].Watts }}'
      iotawatt_in_2:
        unit_of_measurement: W
        friendly_name_template: '{{ states.sensor.iotawatt_config.attributes.inputs[2].name }}'
        value_template: '{{ states.sensor.iotawatt.attributes.inputs[2].Watts }}'
      iotawatt_in_3:
        unit_of_measurement: W
        friendly_name_template: '{{ states.sensor.iotawatt_config.attributes.inputs[3].name }}'
        value_template: '{{ states.sensor.iotawatt.attributes.inputs[3].Watts }}'
      iotawatt_in_4:
        unit_of_measurement: W
        friendly_name_template: '{{ states.sensor.iotawatt_config.attributes.inputs[4].name }}'
        value_template: '{{ states.sensor.iotawatt.attributes.inputs[4].Watts }}'
      iotawatt_in_5:
        unit_of_measurement: W
        friendly_name_template: '{{ states.sensor.iotawatt_config.attributes.inputs[5].name }}'
        value_template: '{{ states.sensor.iotawatt.attributes.inputs[5].Watts }}'
      iotawatt_in_6:
        unit_of_measurement: W
        friendly_name_template: '{{ states.sensor.iotawatt_config.attributes.inputs[6].name }}'
        value_template: '{{ states.sensor.iotawatt.attributes.inputs[6].Watts }}'
      iotawatt_in_7:
        unit_of_measurement: W
        friendly_name_template: '{{ states.sensor.iotawatt_config.attributes.inputs[7].name }}'
        value_template: '{{ states.sensor.iotawatt.attributes.inputs[7].Watts }}'
      iotawatt_in_8:
        unit_of_measurement: W
        friendly_name_template: '{{ states.sensor.iotawatt_config.attributes.inputs[8].name }}'
        value_template: '{{ states.sensor.iotawatt.attributes.inputs[8].Watts }}'
      iotawatt_out_0:
        friendly_name_template: '{{ states.sensor.iotawatt.attributes.outputs[0].name }}'
        unit_of_measurement: W
        value_template: '{{ states.sensor.iotawatt.attributes.outputs[0].value }}'
      iotawatt_out_1:
        friendly_name_template: '{{ states.sensor.iotawatt.attributes.outputs[1].name }}'
        unit_of_measurement: W
        value_template: '{{ states.sensor.iotawatt.attributes.outputs[1].value }}'
      iotawatt_out_2:
        friendly_name_template: '{{ states.sensor.iotawatt.attributes.outputs[2].name }}'
        unit_of_measurement: W
        value_template: '{{ states.sensor.iotawatt.attributes.outputs[2].value }}'

```

p.s. I'm using this and letting Home Assistant publish my data into influxdb so I can create some nice panels on grafana.

boblemaire, 2018-04-03:
Not familiar with that Fredrike.  I couple of comments though...

There are a couple of issues with using the status feed as a data source.  First, the values are damped so they will display better in the app.  The second thing is that as a source for a time series database like influx or Emoncms, the status is real-time so there is no time stamping or ability to bulk update after an outage.

The latest release, 02_03_04, now in ALPHA, has the new influxDB support.  It will upload missing data after an outage, is timestamped, and is not damped.  The influx interface is documented in the wiki.

fredrike, 2018-04-03:
@boblemaire

Yes, I'm running `02_03_04` but I don't like the way values are inserted in influxdb

```
select * from IoT order by time asc limit 10;
time                DM    DM_wH   Livingroom Livingroom_Wh Sovrum_2o3 Sovrum_2o3_wH TM   TM_wH  Total_kWh VVB    VVB_wH Voltage location
----                --    -----   ---------- ------------- ---------- ------------- --   -----  --------- ---    ------ ------- --------
1522418040000000000 0.28  0.0003  0.34       0.0003        588.08     0.5807        0.12 0.0001 0.0013796 807.72 0.7976 217.04  Mjovik

```

Versus:

```
> select time, friendly_name, value from W order by time desc limit 10;
name: W
time                friendly_name                         value
----                -------------                         -----
1522785192755553024 Total                                 1004.623
1522785192748719104 VVB                                   895
1522785192742091008 Total_Wh                              1011.468
1522785192739299072 Vardagsrum                            109
1522785183872164864 Utebelysning Power                    5.3
1522785171003129856 Sparsnäs energy consumption momentary 1825
1522785161887057920 Total                                 1008.03
1522785161880189952 VVB                                   898
1522785161871171840 Total_Wh                              1014.448
1522785156049019136 Sparsnäs energy consumption momentary 1843.2
```

Closed 2018-04-03.

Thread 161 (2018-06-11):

Wiki Configuring Direct for 3 phases

daniwebCH, 2018-06-11:
Hi,
on my case I can not see the complete pictures ;-(

When will be those adapters be needed?

PS: I think that in europe are different countries (like Switzerland) where 3 phases installations are used in all houses.

Sorry it is not really a sw issue, but it is the only way to report it ;-)

boblemaire, 2018-06-11:
You can ask about this at [https://community.iotawatt.com/](https://community.iotawatt.com/)
There are quite a few IoTaWatt with three phase in Switzerland, Germany, Belgium, and Australia. The adapters shown in the wiki are for direct reference.  I would recommend trying Derived reference (one VT) and see if it's accurate enough for you.  Very good results have been reported by a few users, and more importantly, there have been no reports of poor results.  It is much simpler and less expensive.

The adapters are simple and easy to make, but I cannot sell them because it would cost thousands of dollars to get the necessary safety approvals.  I will put the latest schematic and Eagle file in the Github.  Maybe I'll design a through hole version for DIY and sell the bare PCB board.

Try the Derived reference.  Follow up on the forum mentioned above.

Closed 2018-06-11.

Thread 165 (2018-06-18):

Allow negative power value unchecked seems to take effect only after reboot

daniwebCH, 2018-06-18:
version 02_03_07
Procedure:
1) change of parameter "Allow negative power value" from selected to not selected from an input
2) In status the view the value is still shown as negative
3) Reboot IoTaWatt
4) Now on status the value is correctly shown

PS: On the other direction (seems to be ok without reboot)

boblemaire, 2018-06-19:
Thanks,
Fixed in development branch.  Should merge to next release.

boblemaire, 2018-06-21:
Fix released in 02_03_08.

Closed 2018-06-21.

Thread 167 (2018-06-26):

3 phase

stef30360, 2018-06-26:
Hi,
you say
"Here's what one such adapter looks like. These should soon be available from the OEM store, along with various splitters and patch cords needed to connect."
What kind of adapter ? where I can buy this .
regards
SR

boblemaire, 2018-06-27:
I made a batch of prototype adapters and OEM sold them all.  Unfortunately, it is cost prohibitive to produce and sell these because of the high cost to have them tested to UL safety standards.  So I've posted the schematic and PCB layout, so anyone that wants one build one.  OEM has the schematic, and the CE standards for product safety are more reasonable, so perhaps they will decide to build a run of them or offer a DIY thru-hole kit.

I would point out that IoTaWatt has a good track record with derived reference three phase that uses just one VT.  I'd recommend trying that before opting to add two more VTs.

stef30360, 2018-06-27:
Ok. No problem, have you got a link  for upload schematic and PCB ?
SR

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

boblemaire, 2018-06-30:
It's in the hardware directory.

Closed 2018-06-27.

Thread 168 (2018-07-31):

IotaWatt - damaged config - restore /SD?

bluetardis, 2018-07-31:
Hi - I have an iota watt that want boot - config seems not to be correct.    Can I use use the contents of /SD and restore this over the SD card in the device to get things working?

boblemaire, 2018-07-31:
Probably.  It depends what release you are on.  The SD directory in the master branch matches the current release.  Give it a try.  If still problems, look up your release in this Repo and extract the SD directory for your release there.

The [IoTaWatt forum](https://community.iotawatt.com/latest) is the best place to get support with problems like this.  The tools for sharing diagnostic information are better and it is more closely monitored.

Closed 2018-07-31.

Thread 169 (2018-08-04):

NTP Time sync failure

keithle888, 2018-08-04:
Hello, I just installed the IoTaWatt for the first time in Singapore and am experiencing this issue. Could I get some advice?

````
No clock yet: SD initialized.
No clock yet: Real Time Clock not initialized.
No clock yet: Version: 02_02_30
No clock yet: Reset reason: Power on
No clock yet: Trace: 63600,29323,60358,14547,14170,20365,49990,2610,54111,18336,13225,13945,62407,32946,14296,64801,29081,22529,57307,7919,1641,62373,19673,38297,54875,1888,28822,1592,49874,21536,19009,38137
No clock yet: ESP8266 ChipID:6910412
No clock yet: device name: IotaWatt, version: 3
No clock yet: Local time zone: 0
No clock yet: Connecting with WiFiManager.
No clock yet: MDNS responder started
No clock yet: You can now connect to http://IotaWatt.local
No clock yet: HTTP server started
No clock yet: dataLog: service started.
No clock yet: statService: started.
No clock yet: timeSync: service started.
No clock yet: WiFi connected. SSID: ****, IP: ****
No clock yet: timeSync: Failed to get NTPtime.
````

keithle888, 2018-08-04:
nvm! fixed it with a few restarts!

Closed 2018-08-04.

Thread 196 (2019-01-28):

InfluxDB UDP input support

kylehendricks, 2019-01-28:
(Just installed my Iotawatt yesterday and am loving it so far)

I noticed that Iotawatt uses InfluxDB's HTTP API, have you considered adding support for the [InfluxDB UDP Input](https://docs.influxdata.com/influxdb/v1.7/supported_protocols/udp/)?  I used this for ESP32-based house water pressure sensor and it was super easy to implement with very low network overhead.

If this was ever implemented, would it be possible to send data to InfluxDB at a shorter interval?

kylehendricks, 2019-02-03:
Was reading through the forums and saw [this](https://community.iotawatt.com/t/best-practices-for-influxdb/524/8?u=khendricks) post from @boblemaire.

>That said, the actual data posting to influx is a very verbose command line interface and you can dim the lights a little sending a lot of measurements very often

Seems like this could possibly help with that a bit?

boblemaire, 2019-02-03:
I'm not seeing the benefits here.  Correct me if I'm wrong, but this just looks like a different transport protocol (instead of HTTP).  Granted HTTP has more overhead with establishing a connection and headers, but the additional size is trivial compared to the payload.  The real show stopper for me is that it's asynchronous, so I don't know if a packet arrives.  One of the major features of IoTaWatt is that it guarantees delivery.

The real fix for the verbose line protocol is to use compression.  There is a ton of repetition in the postings, so it will compress well.  Moreover, the compression algorithm allows for various levels of compression so IoTaWatt could simply target the low hanging fruit of known repetitive measurement names,  keys, values, time prefixes, etc.  It's on the list.

You can do 5 second posting to influx now.  More often than that has diminishing significance as the increased posting will reduce the sampling.

Finally, this is the kind of discussion I would prefer to do on the forum, so I'm going to close this as an issue.  Thanks for the contribution.

Closed 2019-02-03.

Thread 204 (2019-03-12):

Use NTP server(s) specified by DHCP

aceat64, 2019-03-12:
I'd like to put my IoTaWatt on a secured vlan with no access to the internet, but currently it requires access to an NTP server in order to ensure good timekeeping. If it can use DHCP Option 42, I could use my local NTP server instead of having to craft firewall rules. This could also be useful for "off-grid" installs.

Optionally, if there was a way to simply change the the NTP server that would work as well.

boblemaire, 2019-03-29:
Quick look isn't promising for getting at DHCP options.  That's all at a lower level.  I can add the ability to specify the URL (or IP?) of the NTP server(s), but I will have to think on how to do that best.  I'm trying to keep the UI simple - not present a lot of options that most folks don't understand.  I'm also trying to avoid users editing the config file as blowing the json syntax causes a lot of headache.  Thinking of adding a library where files can be added with these kinds of specifications.   Bottom line is this will be at least a few months before it gets to a release.  In the meantime, if so inclined, the name is hard-coded in timeservices.cpp so you could compile your own version of the firmware.

Tuckie, 2019-06-25:
Just voicing my support for an option to set the NTP server. I have a similar setup where the device does not have direct access to the internet.

starwolf73, 2019-09-03:
Also voicing my support as all my IoT is on secure VLAN with no access to internet.

boblemaire, 2019-12-05:
I do not see a way to get that from the ESP8266/arduino core services.  If you know how to get the DHCP NTP name, please advise, otherwise will close this issue as unattainable.

Tuckie, 2019-12-23:
What about just being able to specify the NTP server?

Jalle19, 2020-01-07:
You can probably work around it with NAT (e.g. https://www.google.com/amp/s/www.linuxincluded.com/ntp-server-ip-blacklisted-nat-redirection-ftw/amp/)

kockockockoc, 2020-01-26:
@boblemaire, looks like this thread about esp8266/Arduino and "NTP servers over DHCP": https://github.com/esp8266/Arduino/issues/5681

ccutrer, 2021-12-21:
Another voice for at least manually specifying the NTP server. That seems much more attainable than getting at the DHCP option.

Closed 2020-11-01.

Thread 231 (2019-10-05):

Sensors failing or device failing?

rotcop4u2, 2019-10-05:
I have had the Iotawatt for almost 10 months now, and I'd have to say I love it. But over the past few months I have noticed that the sensors seem to dropping value. I bought a full US kit with ECS1050 sensors. The reason I know the values are dropping is because I could go from 800 watts on one sensor to 200 the next day, when I know the usage of that circuit is only fluctuating from 400 to 800 because of a usage meter that I have installed from my solar company. Are there any suggestions on why? Or is it possible to get replacement sensors?

boblemaire, 2019-10-08:
This isn't an issue with IoTaWatt firmware.  You can get support for the hardware on the forum at [https://community.iotawatt.com/](https://community.iotawatt.com/).

Closed 2019-10-08.

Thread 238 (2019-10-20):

New feature: Allow Outputs for other Outputs / Direkt transmission to Webservers

Antibrumm, 2019-10-20:
Hi there.

First off: Happy new customer here 👍 The device is a great piece of work!

During the installation I found myself defining the same Output several times for different purposes. It would be great to be able to reuse them directly for other calculation and transmission to the webservers.

Example:
Inputs: Heating_1, Heating_2, Heating_3

- Define one Output: Heatings = Heatings_1 + Heatings_2 + Heatings_3
- Define one Output: Unknown = Total - (Heatings_1 + Heatings_2 + Heatings_3)
=> Could become = Unknown = Total - Heatings

This pattern repeats also in the transmission setup, at least for InfluxDB:
- Heatings | Watts | = Heatings_1 + Heatings_2 + Heatings_3
- Heatings_dWh | Wh | = Heatings_1 + Heatings_2 + Heatings_3
- Unknown | Watts | = Total - (Heatings_1 + Heatings_2 + Heatings_3)

It would be great to avoid such double configurations. It's not a very big deal, as once you're done, you're done, but could simplify the setup process quite a bit.

Cheers

boblemaire, 2019-12-05:
It wouldn't be hard to do on the face of it, but the devil is in the details.  While masquerading as a high level computer, the IoTaWatt is just a lowly IOT device with limited resources.  The problem is handling the error cases.  What happens to all those references if the referenced output disappears?   It's tempting to continue to add capability to the script system, but the possible problems when things are linked just snowballs.  Down the road, with maybe an ESP32, there may be room to redesign the datalog to accommodate something like this.
For now, I am closing this as it's not in the cards for the ESP8266.  Thanks.

Closed 2019-12-05.

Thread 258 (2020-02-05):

CT-values are not populated correctly

fredrike, 2020-02-05:
I have two inputs where the status-page shows values but the Graph+ and Influx db values are 0.

I switched input port for one and the problem went away for that port. But it would be interesting to see what the problem might be.

It is the VVB1 that is the problem in this picture:
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

Relevant configuration:

```json
{
	"format": 2,
	"timezone": "1",
	"device": {
		"name": "iotawatt",
		"version": 3,
		"channels": "15",
		"burden": [
			0,
			24,
			24,
			24,
			24,
			24,
			24,
			24,
			24,
			24,
			24,
			24,
			24,
			24,
			24
		]
	},
	"inputs": [
		{
			"channel": 0,
			"name": "Voltage",
			"type": "VT",
			"model": "Ideal 77DE-06-09(EU)",
			"cal": 19.26,
			"vphase": 0,
			"vmult": 1
		},
		{
			"channel": 1,
			"name": "TM",
			"type": "CT",
			"model": "SCT013-000",
			"phase": 2.3,
			"turns": 2000,
			"cal": 83.33333333333333,
			"vphase": 120,
			"vmult": 1,
			"reverse": true
		},
		{
			"channel": 2,
			"name": "VVB1",
			"type": "CT",
			"model": "SCT013-000",
			"phase": 2.3,
			"turns": 2000,
			"cal": "83.33",
			"vphase": 240,
			"vmult": 1,
			"reverse": true,
			"signed": true
		},
		{
			"channel": 3,
			"name": "VVB2",
			"type": "CT",
			"model": "SCT013-000",
			"phase": 2.3,
			"turns": 2000,
			"cal": 83.33333333333333,
			"vphase": 0,
			"vmult": 1
		}
         ],
	"update": "ALPHA",
	"derive3ph": true,
         "dstrule": {
		"adj": 60,
		"utc": true,
		"begin": {
			"month": 3,
			"weekday": 1,
			"instance": -1,
			"time": 60
		},
		"end": {
			"month": 10,
			"weekday": 1,
			"instance": -1,
			"time": 60
		}
	}
}
```

boblemaire, 2020-02-07:
I don't have enough information to respond to this, but I have an idea what the issue is.  The support forum is a much more convenient tool for interacting and resolving problems.  Please resubmit there: [](https://community.iotawatt.com/latest)

Closed 2020-02-07.

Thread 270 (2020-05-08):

Lost connection to influxdb since 20th April

Antibrumm, 2020-05-08:
Hi
I just realized that since the 20th April both my Iotawatts stopped transmitting their data to my InfluxDB instance. Watching the logs it seems that the Last Entry Query results into a 404 Page not found. Might it be linked to the update 02_05_07 or 02_05_06?

My InfluxDB version is 1.7.9 (which did not change).

I'm not sure the logs are really helpful, but here it is:

SD initialized.
4/20/20 20:02:43z Real Time Clock is running. Unix time 1587412963
4/20/20 20:02:43z Reset reason: Software/System restart
4/20/20 20:02:43z Trace:  9:3, 9:5, 9:9, 1:2, 1:3, 1:4, 1:5[7], 7:0, 7:7, 1:6, 1:3, 1:4, 1:5[19], 1:6, 1:1[8], 1:2[9], 9:0[9], 9:0, 9:1, 8:4, 8:6, 8:8, 8:9, 9:3, 9:5, 9:9, 1:2, 1:3, 1:4, 1:5[5], 5:0, 5:7
4/20/20 20:02:43z ESP8266 ChipID: 6147826
4/20/20 20:02:43z IoTaWatt 5.0, Firmware version 02_05_07
4/20/20 20:02:43z Updater: Installing update files for version 02_05_07
4/20/20 20:02:43z Updater: Installing EDIT.HTM
4/20/20 20:02:43z Updater: Installing GRAPH.HTM
4/20/20 20:02:43z Updater: Installing GRAPH.JS
4/20/20 20:02:43z Updater: Installing GRAPH2.HTM
4/20/20 20:02:44z Updater: Installing GRAPH2.JS
4/20/20 20:02:44z Updater: Installing INDEX.HTM
4/20/20 20:02:45z Updater: Installing TABLES.TXT
4/20/20 20:02:45z Updater: Installing CNFSTYLE.CSS
4/20/20 20:02:45z Updater: Installation complete.
4/20/20 20:02:45z SPIFFS mounted.
4/20/20 23:02:46 Local time zone: +2:00
4/20/20 23:02:46 Using Daylight Saving Time (BST) when in effect.
4/20/20 23:02:46 device name: Iota2
4/20/20 23:02:46 HTTP server started
4/20/20 23:02:46 timeSync: service started.
4/20/20 23:02:46 statService: started.
4/20/20 23:02:46 dataLog: service started.
4/20/20 23:02:47 dataLog: Last log entry 04/20/20 23:02:15
4/20/20 23:02:47 historyLog: service started.
4/20/20 23:02:47 historyLog: Last log entry 04/20/20 23:02:00
4/20/20 23:02:50 WiFi connected. SSID=SOMEID, IP=192.168.1.150, channel=7, RSSI -72db
4/20/20 23:02:50 MDNS responder started for hostname Iota2
4/20/20 23:02:50 LLMNR responder started for hostname Iota2
4/20/20 23:02:50 Updater: service started. Auto-update class is MINOR
4/20/20 23:02:51 influxDB: started, url=HTTP://diskstation.local:8086/, db=iotawatt, interval=10
4/20/20 23:02:51 Updater: Auto-update is current for class MINOR.
4/20/20 23:02:51 influxDB: Last entry query failed.
4/20/20 23:02:51 influxDB: HTTPcode 404, 404 page not found

Let me know if i can help with anything :)

Thanks
Martin

boblemaire, 2020-05-13:
Hi Martin,
I have to wonder how diskstation.local gets resolved.  I am unaware of IoTaWatt doing anything to resolve outbound addressing like that.  Maybe it did on 02_05_02 and prior with the old core and lwip 1, but with 02_05_07 (and you should now be upgraded to 02_05_08) there is a new core with a new lwip 2.  I suspect that may have something to do with it.  Can you try using the diskstation IP address instead?  If that fails, please post this issue on the [forum](https://community.iotawatt.com/latest).  You can see that I didn't notice this for 4 days.  Response time on the forum is measured in hours.  Also, the forum is much easier to post information and leaves a trail for others who may have the same problem.

I'm going to close this github issue.

Closed 2020-05-13.

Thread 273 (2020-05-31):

Is it possible to use this front end with different use case with modification?

happytm, 2020-05-31:
This is perfect front end for it's intended use case of energy monitor.

Is it possible to use this front end with different use case with modification?

Can those 14 input values in your code be replaced by 14 sensor values with modification ?

I wanted to use it with a ESP8266 based multi sensor device which will output about 5 different sensor values like voltage, temperature, humidity & pressure (using BME280) and light sensor etc  and 6 different status values for that device for home automation.  I would like to collect all these sensor data every few minutes which can be displayed later on in graph or table format. My main goal is to keep data local so I do not have to rely on cloud or internet. Right now my code for multi sensor gateway device put out sensor data via MQTT in following format under 2 main topics:

deviceStatus/{"location":"Livingroom","rssi":"-68","mode":"0","ip":"6","channel":"7","sleeptime":"1","uptime":"140"}

sensorValues/{"location":"Livingroom","voltage":"2.62","temperature":"1","humidity":"2","pressure":"147","light":"82"}

deviceStatus/{"location":"Bedroom1","rssi":"-69","mode":"0","ip":"26","channel":"7","sleeptime":"1","uptime":"209"}

sensorValues/{"location":"Bedroom1","voltage":"2.62","level":"8","presence":"0","motion":"29","custom":"40"}

deviceStatus/{"location":"Kitchen","rssi":"-52","mode":"0","ip":"16","channel":"7","sleeptime":"1","uptime":"145"}

sensorValues/{"location":"Kitchen","voltage":"2.62","level":"0","presence":"0","motion":"0","custom":"0"}

Please guide me.

Thanks.

boblemaire, 2020-06-01:
From the beginning it was conceived that other metrics might be collected, and some of the ones that you mention.  I definitely think it's possible to do, but there are limitations:

-
- Adding other types of inputs requires that the hardware support the sensors.  The ESP8266 does not have a lot of GPIO pins.  There are no unused pins in the current device.  The pins used for SPI also serve the SDcard, so can't eliminate that.  The I2C also services the RTC, so can't eliminate that.  There are the CS pins for the ADCs if you want to abandon power sampling, and the single ESP8266 ADC is also available.
-
- Adding different sensor types would require a rethinking of the UI and how to configure.
-
- MQTT support would need to be added, which is puts pressure on available HEAP.  Another option is to use a HTTP agent to send the MQTT.

If you decide to do this, and want to have a portal to ask questions, please use the "Homebrew" category  in the [iotawatt forum](https://community.iotawatt.com/).

happytm, 2020-06-02:
Thanks for your detailed response. I agree there is limitation regarding available gpio pins. I was planning to use  BME280 sensor for Temperaure, Humidity and Pressure and use either APDS-9960 for light or gesture sensor. I was planning to use Arduino Pro Mini as a I2C slave to extend the gpio pins. If ever you decide to implement this framework for ESP32 please consider other use cases. this is very beautiful front end and could be very flexible for other use cases.

Thank anyways for your help.

Closed 2020-06-01.

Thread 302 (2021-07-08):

No "save" button on influxdb v2 uploader page.

ethaniel, 2021-07-08:
Please see screenshot:
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

iamphilrob, 2021-07-08:
Just checked my Influx V1 settings (hopefully V2 is similar)

I think you need to have something in the measurement box - I use iotawatt (use a different name for each iotawatt if you have more than one) - this is one of the key fields in influx that lets you filter/query measurements for reporting

In the field-key box I have $value

Once those are populated you should be able to add tags and measurements and save.

If you are going to upload from the start of 2020 you will have to be very patient - it took 5 days to upload my data (but it will depend on how many measurements you are uploading)

ethaniel, 2021-07-08:
I've been trying to create an output, but don't have a save button as well:
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
Latest Chrome: Version 91.0.4472.114 (Official Build) (x86_64)

ethaniel, 2021-07-08:
Ideally I'd love to have all inputs automatically export into influxdb without me having to manually "wire" them through.

ethaniel, 2021-07-08:
Solved both issues, because measurements/outputs don't accept a space in the "Name" field.
I feel like there needs to be a warning, so I am keeping this ticket open.
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

boblemaire, 2021-07-15:
This issue is better addressed in the forum.  if you simply searched influx save button there, you would find at least two responses that would have resolved your problem.  I'm closing this issue.

Closed 2021-07-15.

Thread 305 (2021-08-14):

Future Version / Feature Suggestions

deggle, 2021-08-14:
Is there any ongoing development of this project? It looks like the best energy monitoring option available, especially with the good number of channels. However, I'd like to make some minor suggestions that I think could really improve this project and be the basis for a V2 hardware/firmware.

You've done the hard work, so I don't actually think these suggestions would be hard to implement and could result in a real uplift in interest and sales among the home automation community.

- Migrate to ESP32 which should give some performance gains
- Use WT32-ETH01 or another option to provide wired ethernet
- Include option to post data to an MQTT broker

Is anything like this on a roadmap?

boblemaire, 2021-08-18:
There is an ESP32 prototype.
Wired ethernet is not possible due to ESP hardware constraints
MQTT output is feasible with the ESP8266 version and not currently on the short list of ESP32 tasks to finish.

There is an HA automation currently available.

As none of this is actionable right now, I'm going to close it out.  There are threads on the[ IoTaWatt forum](https://community.iotawatt.com/) that deal with all of these subjects.

Closed 2021-08-18.

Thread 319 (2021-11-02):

InfluxDB V2 flux query to find last record is wrong

VandaagEnDan, 2021-11-02:
InfluxDB V2 flux query to find last record is wrong. You get a error code and uploader stops.
In influxDB_v2_uploader.cpp

Line 49:
`reqData.printf_P(PSTR("%s\n    (r[\"_measurement\"] == \"%s\""), connectOr.c_str(), varStr(_measurement, script).c_str());`

Should be:
`reqData.printf_P(PSTR("%s\n    r._measurement == \"%s\""), connectOr.c_str(), varStr(_measurement, script).c_str());`

Now code results in this query:

```
from(bucket: "bs_energy")
  |> range(start: 1635523200, stop: 1635786020)
  |> filter(fn: (r) =>
    (r["_measurement"] == "L1_Volts" or
    (r["_measurement"] == "L2_Volts" or
    (r["_measurement"] == "L3_Volts" or
    (r["_measurement"] == "Q2_L1" or
    (r["_measurement"] == "Q2_Total")
  |> last()
  |> map(fn: (r) => ({_measurement: r._measurement, _time: (uint(v:r._time)) / uint(v:1000000000)}))
  |> sort (columns: ["_time"], desc: true)
```

  Correct query would be:

  ```
from(bucket: "bs_energy")
  |> range(start: 1635523200, stop: 1635786020)
  |> filter(fn: (r) =>
    r._measurement == "L1_Volts" or
    r._measurement == "L2_Volts" or
    r._measurement == "L3_Volts" or
    r._measurement == "Q2_L1" or
    r._measurement == "Q2_Total"
  )
  |> last()
  |> map(fn: (r) => ({_measurement: r._measurement, _time: (uint(v:r._time)) / uint(v:1000000000)}))
  |> sort (columns: ["_time"], desc: true)
```
  See https://docs.influxdata.com/flux/v0.x/stdlib/universe/filter/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

nfrankish, 2021-11-06:
Im seeing this, which i assume is related
11/07/21 09:12:08 influxDB_v1: Start posting at 10/29/21 19:37:50
11/07/21 09:14:30 influxDB_v2: stopped, Last post 01/01/70 10:00:00
11/07/21 09:23:38 influxDB_v2: stopped, Last post 01/01/70 10:00:00

boblemaire, 2021-11-12:
@VandaagEnDan,

I just noticed this issue today.  The problem was next on my list, so very timely.  I looked into this somewhat and of course you are right about the r._measurement vs r["_measurement"].  If you look further down, and as per the docs that you referenced, the tags are also not properly referenced and the _field key is not properly referenced.  There is also a problem with the _field and closing parenthesis when there are no tag fields.  These are all now fixed and will appear in release 02_07_04 over the next week or so.

The whole query code is now:
```
 while(script)
    {
        trace(T_influx2,21);
        reqData.printf_P(PSTR("%s\n    (r._measurement == \"%s\""), connectOr.c_str(), varStr(_measurement, script).c_str());
        if(_tagSet){
            trace(T_influx2, 22);
            influxTag* tag = _tagSet;
            while(tag){
                reqData.printf_P(PSTR(" and r.%s == \"%s\""), tag->key, varStr(tag->value, script).c_str());
                tag = tag->next;
            }
        }
        reqData.printf_P(PSTR(" and r._field == \"%s\")"), varStr(_fieldKey, script).c_str());
        connectOr = " or";
        script = script->next();
    }
    trace(T_influx2,20);
    reqData.print(F(")\n  |> last()\n  |> map(fn: (r) => ({_measurement: r._measurement, _time: (uint(v:r._time)) / uint(v:1000000000)}))\n"));
    reqData.print(F("  |> sort (columns: [\"_time\"], desc: true)\n"));
```
Thanks for the flux lesson.

boblemaire, 2021-11-12:
@nfrankish,

Not enough info to say definitively, but probably one of the fixes due out in 02_07_04 will fix it.  There is more about this in the forum. #

Closed 2022-01-26.

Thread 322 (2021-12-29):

feature: per-measurement tags for influx

ccutrer, 2021-12-29:
I'd like to be able to add a "type=total" or "type=device" etc. tag to individual measurements sent to Influx, so that in flux I can build a query that automatically excludes one or the other (total consumption vs. individual circuit). this would be especially useful since I'm going to have 4 iotawatts, and to get the complete consumption for the house, influx will need to sum the "total" measurement for all devices.

boblemaire, 2022-01-26:
Adding the ability to specify tags at the individual measurement level is a slippery slope. How many should be allowed?

This is also very complicated from the perspective of adding the spec to the config.txt file.  Currently, measurements are handled as "tagsets" which are also used for: outputs, integrators, emoncms and PVoutput Scripts.

I'd suggest that you can accomplish this by encoding a "total" indicator in the measurement name and using regular expressions in your queries to recognize them.

Jalle19, 2023-09-06:
@ccutrer did you come up with a solution for this? I'm faced with the same dilemma.

boblemaire, 2023-09-06:
@Jalle19, This is an old issue but looking at it again, I have the same reservations about measurement level tags.  But it occurs to me that you could adopt a measurement naming convention that could accomplish the same thing using regular expressions.

ccutrer, 2023-09-06:
No. I stopped using InfluxDB when 3.0 came out this spring, and there's not an OSS version. Couple that with my constant issues with high CPU usage for hours and it's seeming inability to reclaim disk space, and I was done with it. I now use TimescaleDB. I plan to write a separate script that will run on my TimescaleDB server to pull the data from IoTaWatt via API.

Closed 2022-01-26.

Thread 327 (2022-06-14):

feature - influxdb2 - multiple metrics per "device"

XtremeOwnageDotCom, 2022-06-14:
When setting measurements, you can only have a single measurement with the same $name value.

Lets say, I want to export the current wattage for each of the connected CTs.

So, I create a measurement for each CT, set the measurements' name to something which identifies the CT, and specify the value as the CT's watts.

Everything works great.

BUT, now, lets say, I also want to export WH, or PF, or another metric.

I would have to set the $name to be a different value. In influx, this means, instead of having..... Say-

ac.watts
ac.wh
kitchen.watts
kitchen.wh

I would have something...

ac_watts.watts
ac_wh.wh
kitchen_w.watts
kitchen_wh.wh

which means there is a difficulty in selecting all of the metrics related to a single "device", as I have to set the names different.

Some ideas I have which would assist / help this problem-

1. Could re-enable the ability to have duplicate names. This was possible sometime last year.
2. An additional variable which can be defined on the measurements tab, which we can use as the measurement.

boblemaire, 2022-07-09:
This is a bug in the configuration app caused by a typo during limited cleanup effort.  It was reported and corrected in the git several months ago and will go out in the next release due in the Fall.  In the meantime you can download and install the corrected file index.htm from the master branch to allow specifying multiple measurements with the same name.  The firmware supports that functionality.

Closed 2022-07-09.

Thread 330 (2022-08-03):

Multiple units on one set of VTs

fukuimaunicorn, 2022-08-03:
Hi there,

I'm sorry to ask here, but I can't find anything relating to this in the docs.
I plan to install multiple IoTaWatt Units. I want the measure my power precisely and therefor use a VT for every phase. Now my question is, if I install one set of VTs (one for each phase) can I connect them to multiple IoTaWatt units as reference. Cause as far as I can tell, the units don't draw any current from the reference and therefor there shouldn't be any problem right?
Because 3 VTs per unit would be a _bit_ excessive..

Hope you can clear this up for me, thanks ^^
- Aron

promy, 2022-08-03:
I'm using 1 set of 3 VT's to give a reference to 5 iotaWatt. I just use a splitter (look for the one's for security camera's)

boblemaire, 2022-08-09:
Promy is right.  You can use CCTV 5.5mm splitters to share VTs.  The use of CCTV splitters is strongly recommended as it is critical that polarity be observed and the same for all units.  Also, when sharing VTs, It's critical to have an independent USB power supply for each unit.  Ground loops and shorts can be set up that lead to inaccurate measurements at best and damaged components at worst.

BTW, the [forum ](https://docs.iotawatt.com/en/master/)is the best place for these types of inquiries.

Closed 2022-08-09.

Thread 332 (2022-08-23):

Firmware builds

Onepamopa, 2022-08-23:
Hello,

Why isn't there a newer build of the firmware? The device runs 02_07_05 (Dec 17, 2021), there are plenty of commits since then.

boblemaire, 2022-09-16:
There are issues with incorporating the latest ESP/Arduino core.  It is still risky to release to the installed base. I am working it from both ends.  Hoping for a core update and testing workaround code.  You are welcome to try the current master and report back an issues or lack thereof on the forum.

Closed 2022-09-16.

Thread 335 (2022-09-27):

Second IotaWatt added, first looses all configuration

lyricnz, 2022-09-27:
I had an Iotawatt setup with default device-name, and had configured the inputs etc, and it was all working fine.

I bought a second device, configured the wifi, and the first unit appears to have lost all it's input settings (inputs, calibration, etc).  Yes, I guess there was some kind of clash on iotawatt.local?  It looks like the saved data is there - once I recreated all the inputs, I can see the old data.

Any idea what happened?  This seems like a case where it would be useful to be able to export/import settings for safe storage.

lyricnz, 2022-09-27:
(Maybe unrelated, but I can't get the device reporting proper values - they seem to be about double what they should be!). Unless there's crazy consumption - coincidence?

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

lyricnz, 2022-09-27:
Also, after the new device/integration is added, the existing graphs are now a "random" mixture of 1st and 2nd iotawatt, so whatever is used to store the dashboard graph config isn't stable when new iotawatts are added:

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

The original iotawatt was:
main
bungalow
walloven
power1
power2
lights
hotwater

The new iotawatt (currently sitting on a bench) is
grid_a
grid_b
grid_c
solar_a
solar_b
solar_c
shed1
shed2
shed3
shed4
shed5
shed6
shed7

lyricnz, 2022-09-27:
Maybe related - Home Assistant issues with identifying renamed iotawatt integrations, and "corrupted" graphs when second iotawatt is added.  https://github.com/home-assistant/core/issues/79142

boblemaire, 2022-09-30:
You can download the config.txt with the file manager.  If you want to upload it again, rename it to config+1.txt.

When you have two IoTaWatt by the same name, there is the possibility that the browser app loaded the default config from one and then subsequently uploaded it to the other.  There are a lot of variables that would determine how iotawatt.local is resolved at any specific time. Hopefully you have renamed one of them and this will not be an ongoing problem.

lyricnz, 2022-09-30:
Is there any way to detect if there's an existing iotawatt.local before the new device is registered with that name?  Then it could add unique suffix etc

lyricnz, 2022-09-30:
FWIW I have renamed both of them, so if I ever add a third, I won't experience this.

Closed 2022-09-30.

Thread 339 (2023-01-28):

Graph+ last 3 hours and last 6 hours has error

chriszylstra, 2023-01-28:
Hi there,

I'm getting this request error message I try to select last 3 hours or last 6 hours.
Note: I do not actually have full data for 3 hours ago as I just installed my IoTaWatt. I am just mentioning this because the error does not appear on any other timeframe that I do not have data for yet. (such as last 24 hours). Because of these errors, the graph will not plot even the partial data which I have on the 3 hours or 6 hours timeframe.

I will wait 6 hours and update this if the issue is still happening or has gone away. It might just be an edge case error of the first 6 hours after installing the device.

Thanks,
-cz

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

chriszylstra, 2023-01-29:
Update: Error goes away when there is more than 6 hours of data. So maybe its a non-issue, just letting you know the details.

boblemaire, 2023-06-17:
I'm aware of this issue.  There is a fix in the ESP32 code that needs to be applied to the ESP8266.  But seeing it is an edge issue, doesn't warrant a release.

Closed 2023-06-17.

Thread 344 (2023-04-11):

After update stuck in reboot loop

ramiws, 2023-04-11:
Hi

I updated to  02_08_02 and then got into this loop of reboot "file damaged ". One time it worked but then went crazy again on loop for "low sample count". Then I reboot and got stuck at "file damaged " loop again. I copied SD content from github repo to sd card, I thought that this new version needs that, but no luck

`

SD initialized.
4/11/23 15:45:10z Real Time Clock is running. Unix time 1681227910
4/11/23 15:45:10z Reset reason: Exception
4/11/23 15:45:10z Trace:  1:3, 1:3, 1:3, 1:3, 1:3, 1:3, 1:3, 1:3, 1:3, 1:3, 1:3, 1:3, 1:3, 1:3, 1:3, 1:3, 1:3, 1:3, 1:3, 1:3, 1:1[1], 1:2, 9:0, 9:0, 8:3, 8:3, 1:3, 1:3, 1:3, 1:3, 1:3, 1:3
4/11/23 15:45:10z ESP8266 ID: 6308290, RTC PCF8523 (68)
4/11/23 15:45:10z IoTaWatt 4.x, Firmware version 02_08_02
4/11/23 15:45:10z SPIFFS mounted.
4/11/23 15:45:10z Local time zone: +0:00
4/11/23 15:45:10z device name: IotaWatt
4/11/23 15:45:10z HTTP server started
4/11/23 15:45:10z timeSync: service started.
4/11/23 15:45:10z statService: started.
4/11/23 15:45:10z dataLog: service started.
4/11/23 15:45:10z IotaLog: file damaged /iotawatt/iotalog.log

4/11/23 15:45:10z IotaLog: Creating diagnostic file.
0,0,0,0
0,0,0,0
0,0,0,0
0,0,0,0
0,0,0,0
0,0,0,0
0,0,0,0
0,0,0,0
0,0,0,0
0,0,0,0
0,0,0,0
0,0,0,0
0,0,0,0
0,0,0,0
0,0,0,0
0,0,0,0
0,0,0,0
0,0,0,0
0,0,0,0
0,0,0,0
0,0,0,0
0,0,0,0
0,0,0,0
0,0,0,0
0,0,0,0
0,0,0,0
0,0,0,0
0,0,0,0
0,0,0,0
0,0,0,0
0,0,0,0
0,0,0,0
0,0,0,0
4/11/23 15:45:10z IotaLog: Deleting /iotawatt/iotalog.log and restarting.

 ets Jan  8 2013,rst cause:2, boot mode:(3,6)

load 0x4010f000, len 3424, room 16
tail 0
chksum 0x2e
load 0x3fff20b8, len 40, room 8
tail 0
chksum 0x2b
csum 0x2b
v0008e1b0
~ld
␄�oN�␀�no�쒃�`␃␡�␛␒␌�no�쒃� ␃␡�␛"␌�Nn��|␛�� ␂�"$`␂r�o␏lph��␃�␓�o�|␛r��N|�␌$␌�␄l ␂␜#�␓␂␄��␒r�␂l�N�␌�N�␀␌$`␂��{�l�$␛�
SPI started.

** Restart **

`

boblemaire, 2023-06-17:
This is an issue for the forum. It is probably related to the defective SDcard debacle.

Closed 2023-06-17.

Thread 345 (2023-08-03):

compact DIN version

gkasprow, 2023-08-03:
I purchased 3 original IoTaWatt units to monitor all my circuits and hardly managed to fit them into my cabinet. The audio jacks and 3 VTs took so much space. It's standard situation in Europe.
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
I need to add a few more DIN rail devices, i.e. individual RCBs so had to optimise the energy monitoring dimensions.
So, I designed compact 3-phase version with embedded voltage transformers and power supply.
I also discovered that in my device the LM358 with 10uF load is oscillating so I fixed that issue by adding compensation network.
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
I also used miniature CTs from Talema (AZ-1000) with embedded resistors.
The design is in Altium but one can easily convert it to Kicad when necessary.
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

The PCB fits nicely low cost D6MG enclosure from GAINTA. No cutouts are needed.
The image shows enclosure with front panel removed.
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

The schematic and production files are [here](https://github.com/gkasprow/IoTaWatt_DIN/releases/tag/v1.0rc1)

The sources are [here](https://github.com/gkasprow/IoTaWatt_DIN)

I'm not sure about licensing model. I usually release all my designs using CERN OHL, can you guide me what license shall I use?
Do you think I can use IoTaWatt_DIN name for my design?
I think you should add this version to your offer, Europe will love it.

6fta, 2023-08-04:
I also started to make a pcb for the rail from ZMPT107-1 transformers, but due to lack of time I did not complete the project.
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

gkasprow, 2023-08-04:
I see you added anti-aliasing capacitors at the inputs ?

6fta, 2023-08-05:
Capacitors are optional, I took into account the article in the following link. [ Low current measurement performance of the SCT013](https://www.casler.org/wordpress/low-current-measurement-performance-of-the-sct013/)

gkasprow, 2023-08-05:
I think they are the must. To properly measure signals, one must meet the Nyquist criterium of sampling. For the moment the bandwidth is limited only by CT and VT. For pure sine is fine, but we have broad spectrum of interferences in mains.

gkasprow, 2023-08-05:
One more think. The ADC when sampling, is charging internal capacitor. So it needs low driving impedance. Usually one uses opamp or RC filter where C serves as a reservoir of charge for sampling. In case of CTs, that's not a problem. The VTs have 1k of resistance and this causes measurement error (systematic). Adding 1nF will do two things - limit the BW and meet Nyquist criteria and provide low impedance for ADC.

gkasprow, 2023-08-16:
I meant harmonics and EM interferences generated by loads running on frequencies higher than mains, for example, brushed motors, DC/DC converters etc.

perigoso, 2023-11-22:
Here I was thinking about designing a compact DIN rail version, because my cabinet is quite tight...
Good work @gkasprow! I might fabricate one of yours, have you encountered any issues (that I should try to fix before making my own)?

gkasprow, 2023-11-22:
Somebody built it and so far there is only one non-critical issue
https://github.com/gkasprow/IoTaWatt_DIN/issues/1
I still didn't find time to assemble my PCBs. Existing IotaWatt is working well.  Perfect is the enemy of good

Closed 2023-08-16.

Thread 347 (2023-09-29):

Release 02_08_03 connection issues

Antibrumm, 2023-09-29:
Hello

I just realized today that my two Iotawatt units did not communicate anymore with my influx instance.

After some digging i found that the IPs have changed from the assigned dhcp 192.168… to some random 169.254.. .

I finally went back on the firmware release 02_08_02 and all seems working again. IPs are assigned correctly and the uploder is working.

I did not see anything else broken. The units where still capturing their data. So for now it‘s better to disable auto updates.

Btw: this is my first issue after a continuous runtime of over 4 years. Really nice work :)

Let me know if I can help with logs or something else.

Antibrumm

robao23, 2023-12-28:
Hello,

I've come across a peculiar scenario related to this.
Firmware 02_08_03

The device is working fine, but there's a power outage in the entire house, causing the house to lose internet connectivity as well.

Upon power restoration, the IoTaWatt restarts. I'm not certain if the issue arises because it cannot connect to the network immediately after the power is back.

According to the log, it attempts to reconnect every hour. After 9 unsuccessful attempts, the watchdog restarts the IoTaWatt, and it successfully connects on the first attempt.

Is this genuinely a bug? Is there a way to expedite the process so that it resets when it has been disconnected for 10 minutes, or can the reconnection attempt be improved?

Thank you.

`statService: started.
Updater: service started. Auto-update class is MINOR
12/23/23 01:27:57 timeSync: RTC initalized to NTP time
12/23/23 01:27:57 Real Time Clock battery is low.
12/23/23 01:27:57 dataLog: service started.
12/23/23 01:27:57 dataLog: Last log entry 12/23/23 00:49:45
12/23/23 01:27:57 historyLog: service started.
12/23/23 01:27:57 historyLog: Last log entry 12/23/23 00:49:00
12/23/23 01:27:59 Updater: Auto-update is current for class MINOR.

** Restart **

SD initialized.
Real Time Clock not running.
Reset reason: Power on
Trace:  17:38[12], 35:73[131], 65:91[85], 49:86[84], 12:225[40], 21:201[235], 150:184[110], 38:50[154], 126:153[95], 77:188[77], 255:222[254], 24:33[47], 222:138[52], 38:148[128], 191:24[123], 213:240[200], 140:10[106], 3:51[116], 124:111[145], 237:34[65], 212:23[61], 144:210[161], 249:94[165], 180:29[144], 208:186[6], 142:61[77], 126:29[73], 242:87[207], 85:1[170], 38:201[207], 71:22[17], 91:123[207]
ESP8266 ID: 1760914, RTC PCF8523 (68)
IoTaWatt 5.0, Firmware version 02_08_03
SPIFFS mounted.
Local time zone: +1:00
device name: IotaWatt
Connecting with WiFiManager.
RTC not running, waiting for WiFi.
RTC not running, waiting for WiFi.
RTC not running, waiting for WiFi.
RTC not running, waiting for WiFi.
RTC not running, waiting for WiFi.
RTC not running, waiting for WiFi.
RTC not running, waiting for WiFi.
RTC not running, waiting for WiFi.
RTC not running, waiting for WiFi.

** Restart **

SD initialized.
Real Time Clock not running.
Reset reason: Hardware Watchdog
Trace:  11:5, 11:10, 11:15, 11:20, 11:20[1], 11:20[2], 11:20[3], 11:21, 11:22, 11:21, 11:22, 11:20[4], 11:20[5], 11:20[6], 11:20[7], 11:25, 11:30, 11:30[1], 11:30[2], 11:31, 11:31[1], 11:31[2], 11:31[3], 11:30[3], 11:35, 11:36, 11:35, 11:40, 11:45, 11:50, 11:55, 11:70
ESP8266 ID: 1760914, RTC PCF8523 (68)
IoTaWatt 5.0, Firmware version 02_08_03
SPIFFS mounted.
Local time zone: +1:00
device name: IotaWatt
Connecting with WiFiManager.
HTTP server started
WiFi connected. SSID=ok, IP=localIpOk, channel=8, RSSI -54db
timeSync: service started.
statService: started.
Updater: service started. Auto-update class is MINOR
12/28/23 10:28:07 timeSync: RTC initalized to NTP time
12/28/23 10:28:07 Real Time Clock battery is low.
12/28/23 10:28:07 dataLog: service started.
12/28/23 10:28:07 dataLog: Last log entry 12/28/23 01:35:25
12/28/23 10:28:07 historyLog: service started.
12/28/23 10:28:07 historyLog: Last log entry 12/28/23 01:35:00
12/28/23 10:28:08 Updater: Auto-update is current for class MINOR.
`

boblemaire, 2023-12-28:
This issue should be presented in the forum.

Auto-reconnect is enabled and supposed to be handled by lower level code in the ESP8266.  Unfortunately it doesn't work all that well in this circumstance.  Restarting every 10 minutes would be excessive.

Note that your RTC battery is low so the IoTaWatt doesn't know what time it is until it can connect to the internet.  If you had a good battery, logging would continue without the internet connection so you would not lose any data.

Closed 2023-12-28.

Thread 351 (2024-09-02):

web server UI issue, menu hover state persists on iOS/Safari

tristansokol, 2024-09-02:
Hi! Love the project.

Was setting up with my phone and noticed that the menu dropdown states persist/are not clearable. On some screens such as `Inputs` you can enter an accessible input option and cancel back out to clear the menu, but for others such as `Outputs` there is nothing visible under the menu to click on and the page is unusable on my phone.

The easiest fix might be to add a css transition to make the menu expire after a few seconds (20?), even if hovered. Still not a great experience but at least usable. I'm not sure if something better is possible with out reworking how the menu works/if you are interested in updating the menu that much.

Happy to try a PR if you have a vision for a fix.

dineshpannu, 2025-02-22:
I’m having the same issue. I don’t recall this problem when I first set up the device, so I think a recent iOS version broke it.

Just registering my vote for a fix.

boblemaire, 2025-03-30:
This situation exists on iPhones but you can eliminate the dropdown by simply holding your finger on the background next to it.

Closed 2025-03-30.

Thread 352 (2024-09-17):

CT divide-by-ten option

TheBlueMatt, 2024-09-17:
It seems many line splitters out there have a 10x multiple, causing CT readings to be 10x too high. It would be nice to have a divide-by-1- option next to the double and reverse options.

boblemaire, 2025-03-30:
Don't understand this.  If the calibration of the CT is incorrect, there is an option to setup as generic and specify the correct calibration.

Another solution is to create an output that multiplies by 10 or whatever. That's what outputs are for.  Adding a x10 checkbox on the inputs creates a number of problems including requiring documentation to explain what it does and why someone might want to use it.  While IoTaWatt is very powerful, the basic philosophy is to not present every user with a plethora of confusing decisions to make.

Yes, there is a x2 checkbox, but that is based on the very understandable situation with split-phase 120/240 and it already does add a lot of complexity to the documentation explaining what it does and why someone might want to use it.

Closed 2025-03-30.

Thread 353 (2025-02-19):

Native MQTT Support for IoTaWatt

robao23, 2025-02-19:
**Is your feature request related to a problem? Please describe.**
Currently, IoTaWatt lacks native MQTT support, making it difficult to integrate with modern home automation platforms like Home Assistant, OpenHAB, and others that rely heavily on MQTT for real-time energy monitoring. The current alternatives (REST API polling or Node-RED workarounds) introduce latency and inefficiencies.

**Describe the solution you'd like**
Adding native MQTT support would allow IoTaWatt to publish power consumption data directly to an MQTT broker. This would enable real-time updates with minimal network load. Suggested features include:

- Ability to configure an MQTT broker in the IoTaWatt settings.
- Topic structure based on configured inputs/outputs (e.g., iotawatt/inputs/channel_1, iotawatt/outputs/total_power).
- Configurable update intervals or publishing on value change.

**Describe alternatives you've considered**
Using Node-RED to bridge IoTaWatt's HTTP API to MQTT, which increases complexity.
Polling data via REST API, which creates unnecessary network traffic and delays.

**Additional context**
IoTaWatt is an excellent energy monitoring solution, and adding MQTT support would make it even more versatile and compatible with existing home automation ecosystems.

###Basic implementation ideas for MQTT Support

   - Include the MQTT library:
     ```cpp
     #include <PubSubClient.h>
     ```
   - Configure the MQTT client and broker settings:
     ```cpp
     const char* mqtt_server = "your_mqtt_broker_address";
     const char* mqtt_user = "your_mqtt_username"; // If required
     const char* mqtt_password = "your_mqtt_password"; // If required
     PubSubClient mqttClient(client);
     ```
   - Implement the MQTT connection function:
     ```cpp
     void connectMQTT() {
         while (!mqttClient.connected()) {
             if (mqttClient.connect("IoTaWattClient", mqtt_user, mqtt_password)) {
                 Serial.println("Connected to MQTT broker");
             } else {
                 Serial.print("Failed to connect, rc=");
                 Serial.print(mqttClient.state());
                 delay(2000);
             }
         }
     }
     ```
   - Publish data in the main loop:
     ```cpp
     void loop() {
         if (!mqttClient.connected()) {
             connectMQTT();
         }
         mqttClient.loop();

         float totalPower = getTotalPower(); // Implement this function as per your logic
         mqttClient.publish("iotawatt/outputs/total_power", String(totalPower).c_str());

         delay(10000); // Publish every 10 seconds
     }
     ```

The biggest advantage of using MQTT Explorer is that it allows for easy visualization and management of MQTT messages, and also that the publish can be every second without overloading the system.

boblemaire, 2025-03-30:
This is a recurring request.

The ESP8266 does not have sufficient resources remaining to support MQTT. Your example is not realistic given the architecture of the IoTaWatt operating system.  Take a look at the existing loop().  It is sampling power 2/3 of the time and between dispatching various tasks (uploaders, data logging, time, update) and dispatching the webserver to handle HTTP requests including status, configuration and query. The lights are already pretty dim and heap memory is stretched very thin.

Closed 2025-03-30.

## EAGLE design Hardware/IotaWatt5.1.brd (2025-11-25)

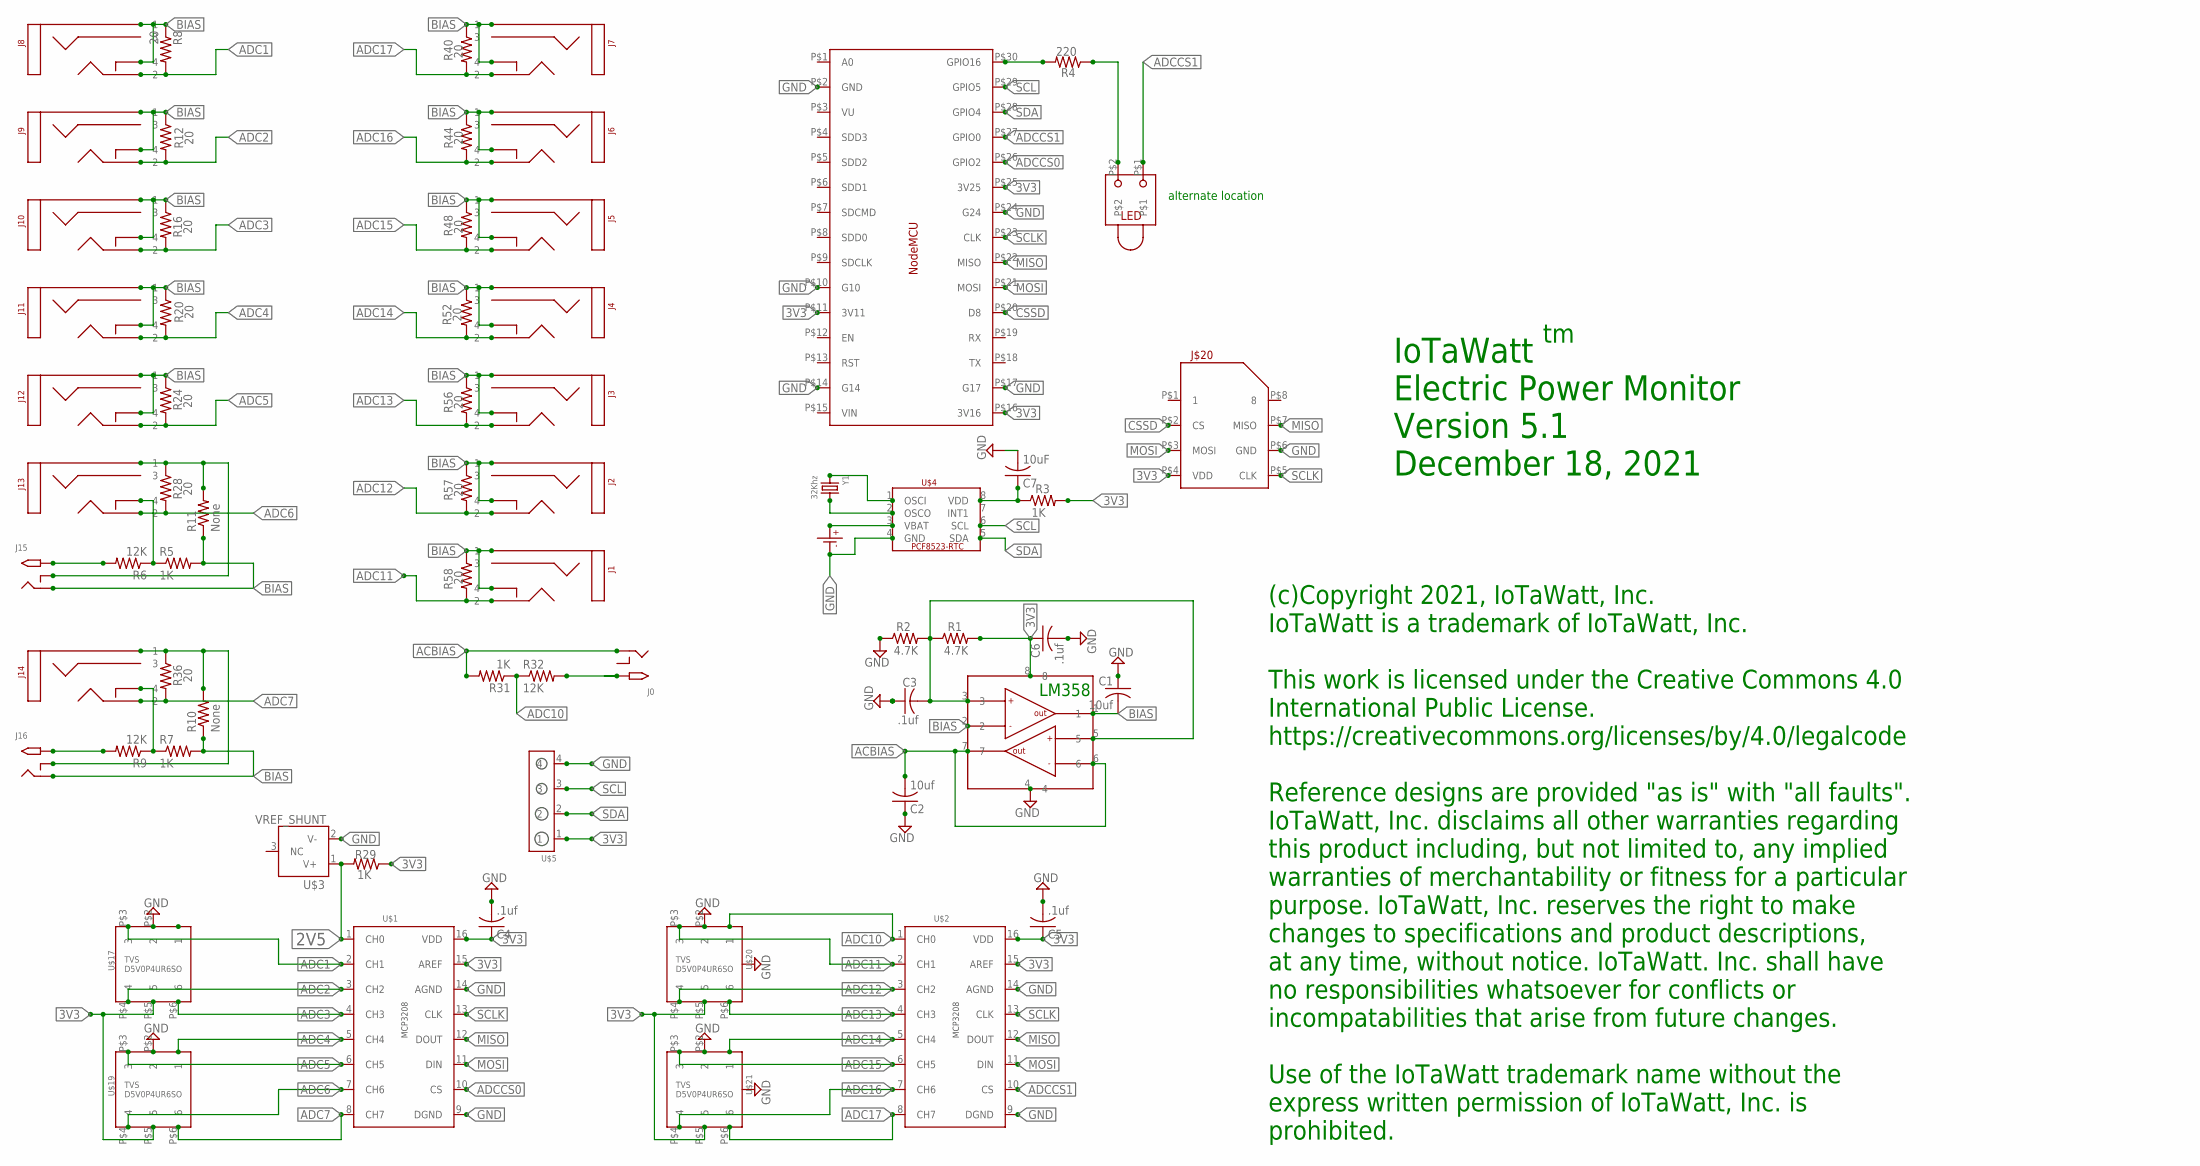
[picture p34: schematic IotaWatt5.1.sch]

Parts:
C1, C2: 10uf; C0805
C3, C4, C5, C6: .1uf; C0805
C7: 10uF; C0805
J0, J15, J16: 2.1MMJACKSMT; DCJACK_2MM_SMT
J1, J2, J3, J4, J5, J6, J7, J8, J9, J10, J11, J12, J13, J14: STEREO_SMD; STEREO_SMT
J$20: MICROSD_PUSH/PULL; MICROSD
R1, R2: 4.7K; R0805
R3, R5, R7, R29, R31: 1K; R0805
R4: 220; R0805
R6, R9, R32: 12K; R0805
R8, R12, R16, R20, R24, R28, R36, R40, R44, R48, R52, R56, R57, R58: 20; R0805
R10, R11: None; R0805
U$1, U$2: MCP3208; SOIC_16
U$3: VREF_SHUNT; SOT23_3
U$4: PCF8523_RTC; SOIC_8
U$5: HEADER_1X4
U$16: NODEMCU
U$17, U$19, U$20, U$21: TVS_4CHAN_ARRAYSC-74; SC-74
U$18: CR1220SMD
U$22: LM358_DUAL_OP-AMP; SOIC_8
U$23: LED_RT_TRH; LED_TH_RT
Y1: 32Khz; CRYSTAL_8X3.8

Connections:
2V5: R29.2, U$1.1 (CH0), U$3.1 (V+)
3V3: C4.1, C5.1, C6.1, J$20.P$4 (VDD), R1.2, R3.2, R29.1, U$1.15 (AREF), U$1.16 (VDD), U$2.15 (AREF), U$2.16 (VDD), U$5.1, U$16.P$11 (3V11), U$16.P$16 (3V16), U$16.P$25 (3V25), U$17.P$5 (5), U$19.P$5 (5), U$20.P$5 (5), U$21.P$5 (5), U$22.8
ACBIAS: C2.2, J0.GND (RING), R31.2, U$22.6, U$22.7
ADC1: J8.P$2 (2), R8.2, U$1.2 (CH1), U$17.P$3 (3)
ADC2: J9.P$2 (2), R12.2, U$1.3 (CH2), U$17.P$4 (4)
ADC3: J10.P$2 (2), R16.2, U$1.4 (CH3), U$17.P$6 (6)
ADC4: J11.P$2 (2), R20.2, U$1.5 (CH4), U$19.P$1 (1)
ADC5: J12.P$2 (2), R24.2, U$1.6 (CH5), U$19.P$3 (3)
ADC6: J13.P$2 (2), R28.2, U$1.7 (CH6), U$19.P$4 (4)
ADC7: J14.P$2 (2), R36.2, U$1.8 (CH7), U$19.P$6 (6)
ADC10: R31.1, R32.1, U$2.1 (CH0), U$20.P$1 (1)
ADC11: J1.P$2 (2), R58.2, U$2.2 (CH1), U$20.P$3 (3)
ADC12: J2.P$2 (2), R57.2, U$2.3 (CH2), U$20.P$4 (4)
ADC13: J3.P$2 (2), R56.2, U$2.4 (CH3), U$20.P$6 (6)
ADC14: J4.P$2 (2), R52.2, U$2.5 (CH4), U$21.P$1 (1)
ADC15: J5.P$2 (2), R48.2, U$2.6 (CH5), U$21.P$3 (3)
ADC16: J6.P$2 (2), R44.2, U$2.7 (CH6), U$21.P$4 (4)
ADC17: J7.P$2 (2), R40.2, U$2.8 (CH7), U$21.P$6 (6)
ADCCS0: U$1.10 (CS), U$16.P$26 (GPIO2)
ADCCS1: U$2.10 (CS), U$16.P$27 (GPIO0), U$23.P$1
BIAS: C1.2, J1.P$1 (1), J1.P$4 (4), J2.P$1 (1), J2.P$4 (4), J3.P$1 (1), J3.P$4 (4), J4.P$1 (1), J4.P$4 (4), J5.P$1 (1), J5.P$4 (4), J6.P$1 (1), J6.P$4 (4), J7.P$1 (1), J7.P$4 (4), J8.P$1 (1), J8.P$4 (4), J9.P$1 (1), J9.P$4 (4), J10.P$1 (1), J10.P$4 (4), J11.P$1 (1), J11.P$4 (4), J12.P$1 (1), J12.P$4 (4), J15.GND (RING), J16.GND (RING), R5.2, R7.2, R8.1, R10.1, R11.1, R12.1, R16.1, R20.1, R24.1, R40.1, R44.1, R48.1, R52.1, R56.1, R57.1, R58.1, U$22.1, U$22.2
CSSD: J$20.P$2 (CS), U$16.P$20 (D8)
GND: C1.1, C2.1, C3.1, C4.2, C5.2, C6.2, C7.2, J$20.P$6 (GND), R2.1, U$1.9 (DGND), U$1.14 (AGND), U$2.9 (DGND), U$2.14 (AGND), U$3.2 (V-), U$4.4 (GND), U$5.4, U$16.P$2 (GND), U$16.P$10 (G10), U$16.P$14 (G14), U$16.P$17 (G17), U$16.P$24 (G24), U$17.P$2 (2), U$18.P- (P$-), U$19.P$2 (2), U$20.P$2 (2), U$21.P$2 (2), U$22.4
MISO: J$20.P$7 (MISO), U$1.12 (DOUT), U$2.12 (DOUT), U$16.P$22 (MISO)
MOSI: J$20.P$3 (MOSI), U$1.11 (DIN), U$2.11 (DIN), U$16.P$21 (MOSI)
unnamed: C7.1, R3.1, U$4.8 (VDD)
unnamed: J15.PWR2 (TIP), R6.2
unnamed: J16.PWR2 (TIP), R9.2
unnamed: J14.P$1 (1), J16.GNDBREAK (RING_SW), R10.2, R36.1
unnamed: J13.P$1 (1), J15.GNDBREAK (RING_SW), R11.2, R28.1
unnamed: J14.P$4 (4), R7.1, R9.1
unnamed: R4.1, U$23.P$2
unnamed: J13.P$4 (4), R5.1, R6.1
unnamed: R4.2, U$16.P$30 (GPIO16)
unnamed: J0.PWR2 (TIP), R32.2
unnamed: U$4.3 (VBAT), U$18.P+ (P$+)
unnamed: U$4.2 (OSCO), Y1.P$4 (2)
unnamed: U$4.1 (OSCI), Y1.P$1 (1)
SCL: U$4.6 (SCL), U$5.3, U$16.P$29 (GPIO5)
SCLK: J$20.P$5 (CLK), U$1.13 (CLK), U$2.13 (CLK), U$16.P$23 (CLK)
SDA: U$4.5 (SDA), U$5.2, U$16.P$28 (GPIO4)
VREF: C3.2, R1.1, R2.2, U$22.3, U$22.5

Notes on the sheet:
IoTaWatt Electric Power Monitor Version 5.1 December 18, 2021
alternate location
LM358
(c)Copyright 2021, IoTaWatt, Inc. IoTaWatt is a trademark of IoTaWatt, Inc. This work is licensed under the Creative Commons 4.0 International Public License. https://creativecommons.org/licenses/by/4.0/legalcode Reference designs are provided "as is" with "all faults". IoTaWatt, Inc. disclaims all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

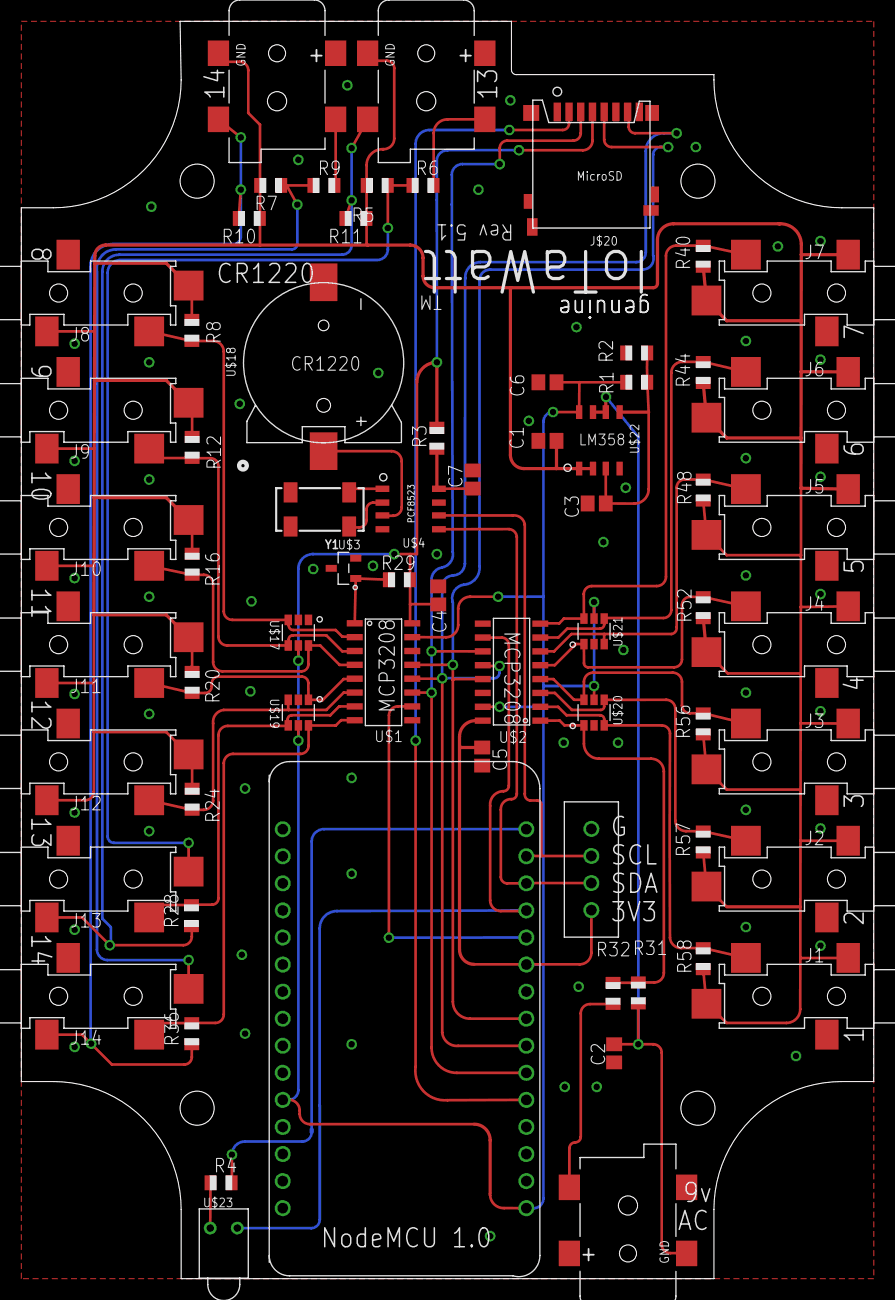
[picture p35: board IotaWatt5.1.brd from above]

Board: 2 copper layers, 80.0 x 118.0 mm, 66 parts (0 on the bottom side), 42 nets.

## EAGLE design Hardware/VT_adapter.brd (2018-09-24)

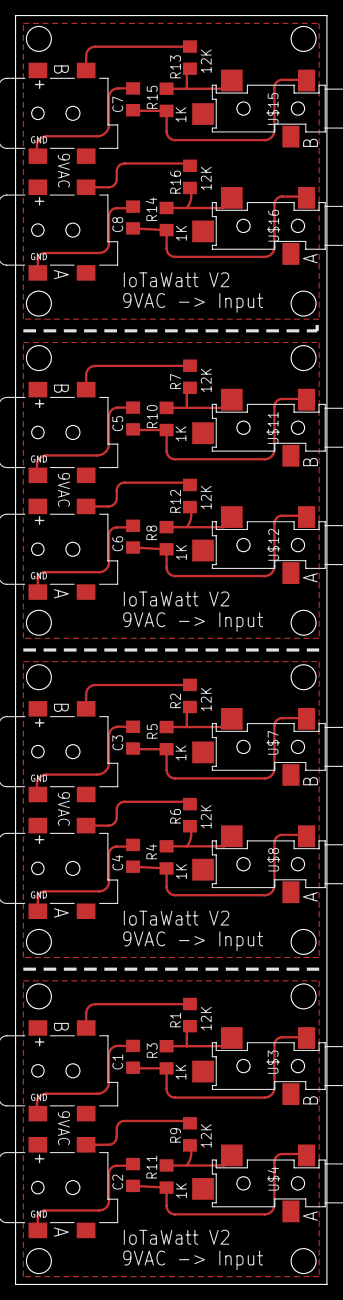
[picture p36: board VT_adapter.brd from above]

Board: 2 copper layers, 40.0 x 163.0 mm, 40 parts (0 on the bottom side), 32 nets.

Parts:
C1, C2, C3, C4, C5, C6, C7, C8: 10uf; C1206
R1, R2, R6, R7, R9, R12, R13, R16: 12K; R1206
R3, R4, R5, R8, R10, R11, R14, R15: 1K; R1206
U$1, U$2, U$5, U$6, U$9, U$10, U$13, U$14: 2.1MMJACKSMT; DCJACK_2MM_SMT
U$3, U$4, U$7, U$8, U$11, U$12, U$15, U$16: STEREO_SMD; STEREO_SMT

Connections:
unnamed: C1.2, R3.2, U$3.P$1
unnamed: R1.2, R3.1, U$3.P$2
unnamed: C1.1, U$1.GND
unnamed: C2.1, U$2.GND
unnamed: R4.2, R6.2, U$8.P$2
unnamed: R1.1, U$1.PWR2
unnamed: R9.1, U$2.PWR2
unnamed: C4.2, R4.1, U$8.P$1
unnamed: C3.2, R5.2, U$7.P$1
unnamed: C3.1, U$5.GND
unnamed: R9.2, R11.2, U$4.P$2
unnamed: C2.2, R11.1, U$4.P$1
unnamed: R2.1, U$5.PWR2
unnamed: C4.1, U$6.GND
unnamed: R6.1, U$6.PWR2
unnamed: R2.2, R5.1, U$7.P$2
unnamed: R8.2, R12.2, U$12.P$2
unnamed: C6.2, R8.1, U$12.P$1
unnamed: C5.2, R10.2, U$11.P$1
unnamed: C5.1, U$9.GND
unnamed: R7.1, U$9.PWR2
unnamed: C6.1, U$10.GND
unnamed: R12.1, U$10.PWR2
unnamed: R7.2, R10.1, U$11.P$2
unnamed: R14.2, R16.2, U$16.P$2
unnamed: C8.2, R14.1, U$16.P$1
unnamed: C7.2, R15.2, U$15.P$1
unnamed: C7.1, U$13.GND
unnamed: R13.1, U$13.PWR2
unnamed: C8.1, U$14.GND
unnamed: R16.1, U$14.PWR2
unnamed: R13.2, R15.1, U$15.P$2

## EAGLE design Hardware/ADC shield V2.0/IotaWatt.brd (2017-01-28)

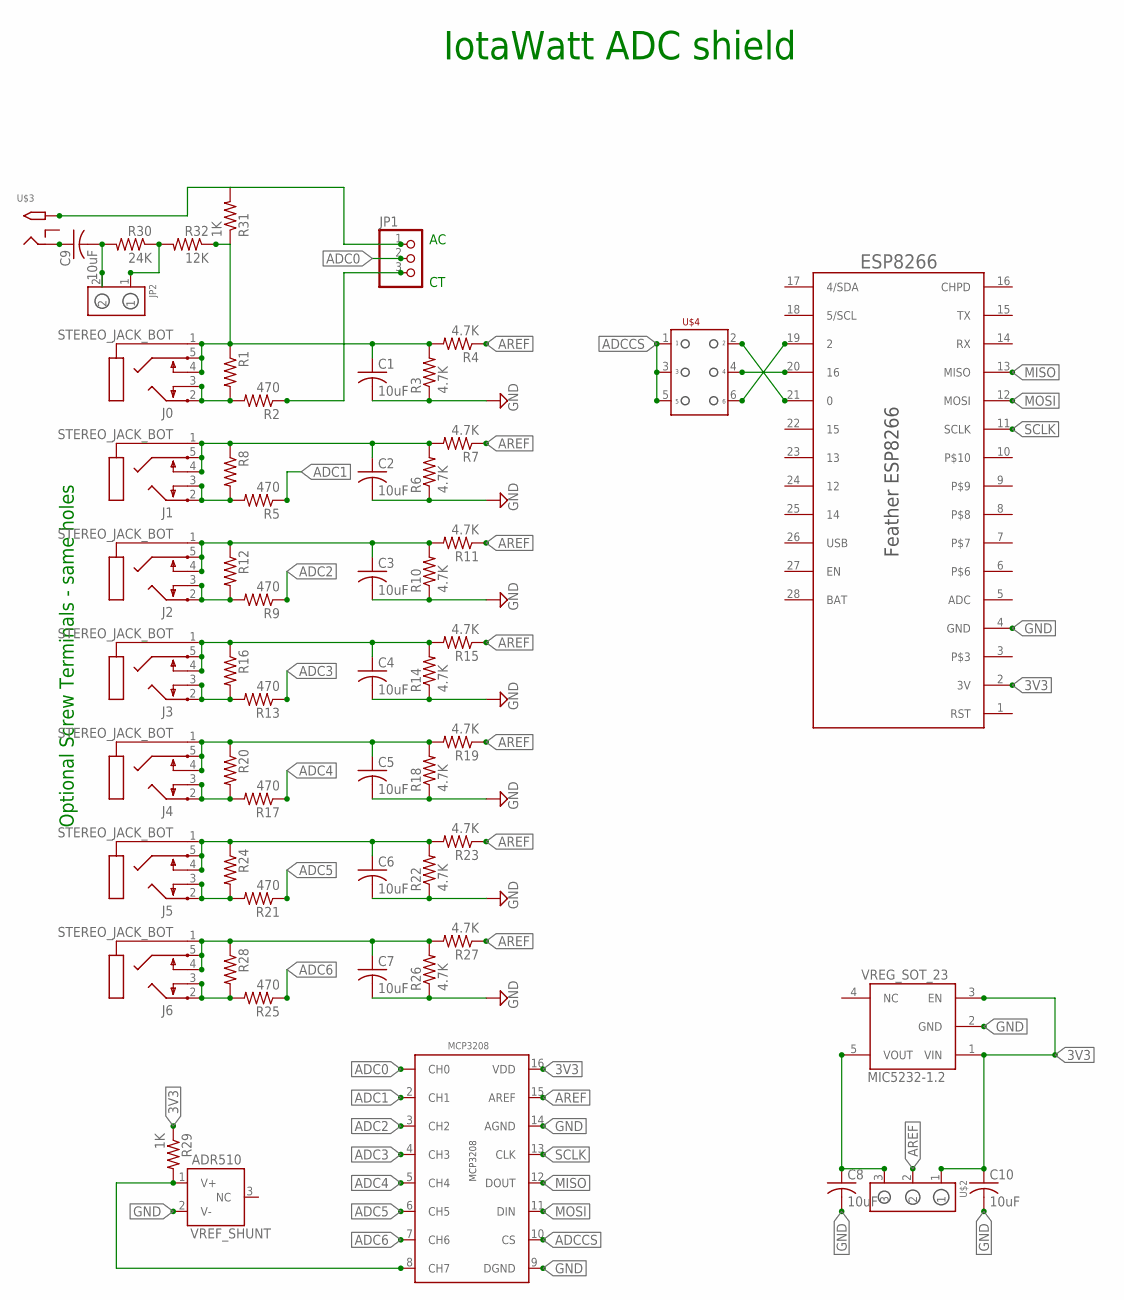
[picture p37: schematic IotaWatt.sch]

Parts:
ADR510: VREF_SHUNT; SOT23_3
C1, C2, C3, C4, C5, C6, C7, C8, C9, C10: 10uF; C0805
J0, J1, J2, J3, J4, J5, J6: STEREO_JACK_BOT; STX3100
JP1: PINHD-1X3; 1X03
JP2: HEADER_1X2
MCP3208: MCP3208; SOIC_16
MIC5232-1.2: VREG_SOT_23; SOT23_5
R1, R8, R12, R16, R20, R24, R28: R-US_FLIPFLOP7; 0805-THM-7
R2, R5, R9, R13, R17, R21, R25: 470; R0805
R3, R4, R6, R7, R10, R11, R14, R15, R18, R19, R22, R23, R26, R27: 4.7K; R0805
R29, R31: 1K; R0805
R30: 24K; R0805
R32: 12K; R0805
U$1: ESP8266FEATHER; FEATHERWING
U$2: HEADER_1X3
U$3: 2.1MMJACKBOTTHM; PJ-102A-BOT
U$4: HEADER_2X3

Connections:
3V3: C10.1, MCP3208.16 (VDD), MIC5232-1.2.1 (VIN), MIC5232-1.2.3 (EN), R29.1, U$1.2 (3V), U$2.1
ACV1: C9.2, JP2.2, R30.2
ACV2: JP2.1, R30.1, R32.2
ADC0: JP1.2, MCP3208.1 (CH0)
ADC1: MCP3208.2 (CH1), R5.1
ADC2: MCP3208.3 (CH2), R9.1
ADC3: MCP3208.4 (CH3), R13.1
ADC4: MCP3208.5 (CH4), R17.1
ADC5: MCP3208.6 (CH5), R21.1
ADC6: MCP3208.7 (CH6), R25.1
ADC7: ADR510.1 (V+), MCP3208.8 (CH7), R29.2
ADCCS: MCP3208.10 (CS), U$4.1, U$4.3, U$4.5
AREF: MCP3208.15 (AREF), R4.1, R7.1, R11.1, R15.1, R19.1, R23.1, R27.1, U$2.2
GND: ADR510.2 (V-), C1.2, C2.2, C3.2, C4.2, C5.2, C6.2, C7.2, C8.2, C10.2, MCP3208.9 (DGND), MCP3208.14 (AGND), MIC5232-1.2.2 (GND), R3.1, R6.1, R10.1, R14.1, R18.1, R22.1, R26.1, U$1.4 (GND)
MISO: MCP3208.12 (DOUT), U$1.13 (MISO)
MOSI: MCP3208.11 (DIN), U$1.12 (MOSI)
unnamed: JP1.3, R2.1
unnamed: C1.1, J0.1, J0.4 (3), J0.5 (2), R1.1, R3.2, R4.2, R31.1, R32.1
unnamed: U$1.21 (0), U$4.2
unnamed: C2.1, J1.1, J1.4 (3), J1.5 (2), R6.2, R7.2, R8.1
unnamed: J2.2 (5), J2.3 (4), R9.2, R12.2
unnamed: U$1.19 (2), U$4.6
unnamed: C9.1, U$3.RING
unnamed: JP1.1, R31.2, U$3.TIP
unnamed: U$1.20 (16), U$4.4
unnamed: C3.1, J2.1, J2.4 (3), J2.5 (2), R10.2, R11.2, R12.1
unnamed: C5.1, J4.1, J4.4 (3), J4.5 (2), R18.2, R19.2, R20.1
unnamed: J5.2 (5), J5.3 (4), R21.2, R24.2
unnamed: C6.1, J5.1, J5.4 (3), J5.5 (2), R22.2, R23.2, R24.1
unnamed: J0.2 (5), J0.3 (4), R1.2, R2.2
unnamed: J6.2 (5), J6.3 (4), R25.2, R28.2
unnamed: C7.1, J6.1, J6.4 (3), J6.5 (2), R26.2, R27.2, R28.1
unnamed: J1.2 (5), J1.3 (4), R5.2, R8.2
unnamed: J3.2 (5), J3.3 (4), R13.2, R16.2
unnamed: C4.1, J3.1, J3.4 (3), J3.5 (2), R14.2, R15.2, R16.1
unnamed: C8.1, MIC5232-1.2.5 (VOUT), U$2.3
unnamed: J4.2 (5), J4.3 (4), R17.2, R20.2
SCLK: MCP3208.13 (CLK), U$1.11 (SCLK)

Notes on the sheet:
IotaWatt ADC shield
Optional Screw Terminals - same holes

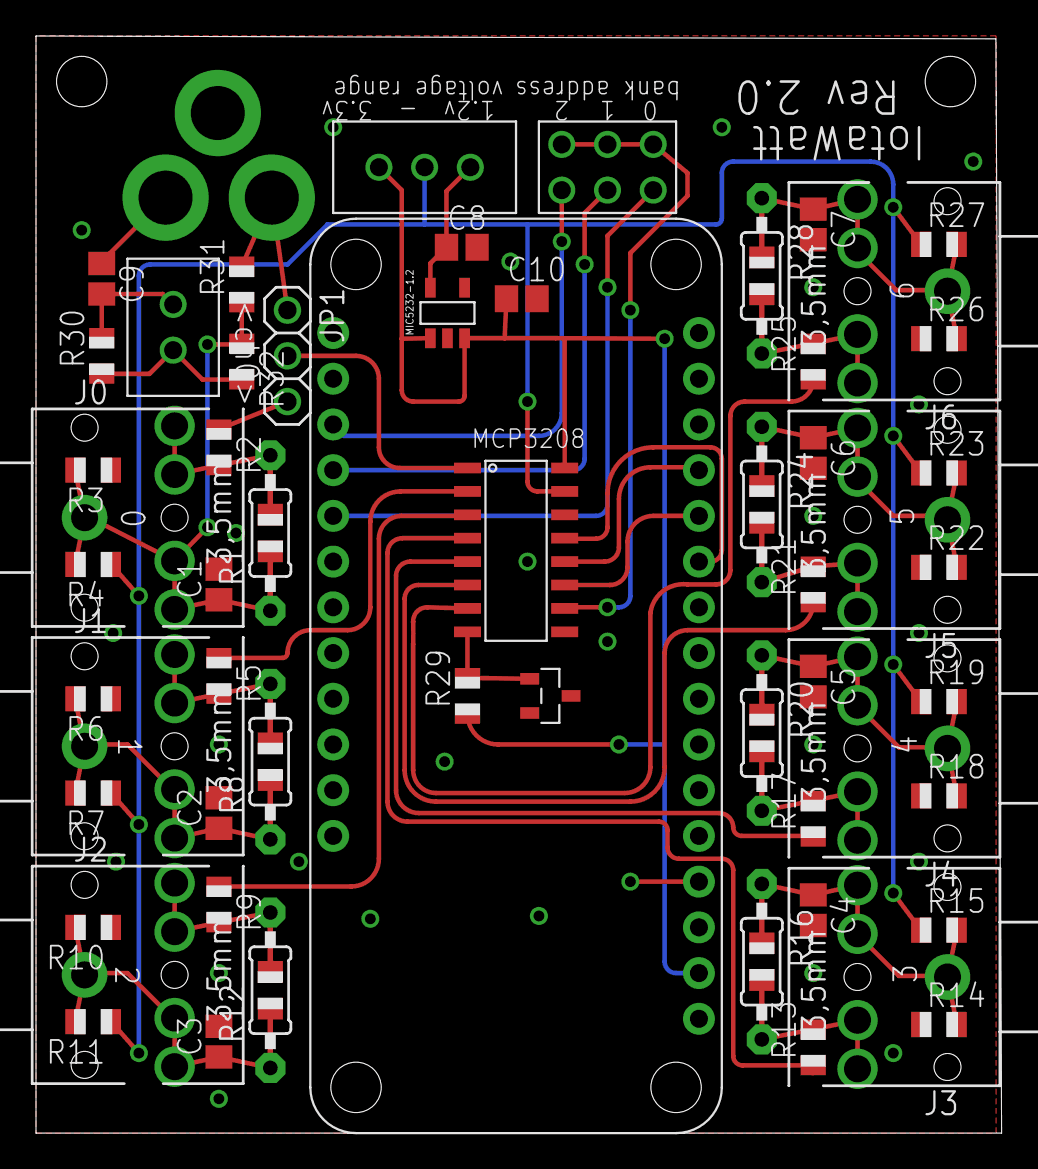
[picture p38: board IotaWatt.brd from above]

Board: 2 copper layers, 53.6 x 61.0 mm, 58 parts (0 on the bottom side), 38 nets.

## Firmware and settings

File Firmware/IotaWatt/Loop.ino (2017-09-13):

 void loop()
{
/******************************************************************************
 * The main loop is very simple:
 *  Sample a power channel.
 *  Yield to the OS and Wifi Server.
 *  Run next dispatchable service if there is one
 *  Yield to the OS and Wifi Server.
 *  Go back, Jack, and do it again.
 ******************************************************************************/

  setLedState();

  // ------- If AC zero crossing approaching, go sample a channel.

  if((uint32_t)(millis() - lastCrossMs) >= (490 / int(frequency))){
    ESP.wdtFeed();
    trace(T_LOOP,1);
    samplePower(nextChannel, 0);
    trace(T_LOOP,2);
    nextCrossMs = lastCrossMs + 490 / int(frequency);
    while( ! inputChannel[++nextChannel % maxInputs]);
    nextChannel = nextChannel % maxInputs;
  }

  // --------- Give web server a shout out.
  //           serverAvailable will be false if there is a request being serviced by
  //           an Iota SERVICE. (GetFeedData)

  yield();
  ESP.wdtFeed();
  trace(T_LOOP,3);
  if(serverAvailable){
    server.handleClient();
    trace(T_LOOP,4);
    yield();
  }
  

// ---------- If the head of the service queue is dispatchable
//            call the SERVICE.

  if(serviceQueue != NULL && UNIXtime() >= serviceQueue->callTime){
    serviceBlock* thisBlock = serviceQueue;
    serviceQueue = thisBlock->next;
    ESP.wdtFeed();
    trace(T_LOOP,5);
    thisBlock->callTime = thisBlock->service(thisBlock);
    trace(T_LOOP,6);
    if(thisBlock->callTime > 0){
      AddService(thisBlock); 
    } else {
      delete thisBlock;    
    }
  }

// ----------- Another shout out to the Web 
     
  yield();
  ESP.wdtFeed();
  if(serverAvailable){
    trace(T_LOOP,7);
    server.handleClient();
    trace(T_LOOP,8);
    yield();
  }
}

/*****************************************************************************************************

                                    End of main Loop
             
******************************************************************************************************

 * Scheduler/Dispatcher support functions.
 * 
 * The main loop steps through and samples the channels at the millisecond level.  It invokes samplePower()
 * which samples one or more waves and updates the corresponding data buckets.  After each sample, there 
 * are a few milliseconds before the next AC zero crossing, so we try to do everything else during that
 * downtime.
 * 
 * To accomplish that, other activities are organized as SERVICEs that are scheduled and are dispatched in 
 * Loop during the half-cycle downtime. The ESP8266 is already running a lower level operating system that 
 * is task oriented and dispatches this program along with other tasks - most notably the WiFi stack. Ticker
 * taps into that and provides one time or periodic interrupts that could be used to run services, but we
 * run the channel sampling with interrupts disabled, and we really don't need sub-second scheduling for 
 * our services anyway, so Ticker is not used.
 * 
 * This mechanism schedules at a resolution of one second, and dispatches during the optimal time period
 * between AC cycles.  To avoid context and synchonization issues, each service is coded as a state-machine.
 * They must be well behaved and should try to run for less than a few milliseconds. Although that isn't
 * always possible and doesn't do any real harm if they run over - just reduces the sampling frequency a bit.
 * 
 * Services return the UNIXtime of the next requested dispatch.  If the requested time is in the past, 
 * the service is requeued at the current time, so if a service just wants to relinquish but reschedule 
 * for the next available opportunity, just return 1.  If a service returns zero, it's service block will
 * be deleted.  To reschedule, AddService would have to be called to create a new serviceBlock.
 * 
 * The schedule itself is kept as an ordered list of control blocks in ascending order of time + priority.
 * Loop simply invokes the service currently at the beginning of the list.
 * 
 * The WiFi server is not one of these services.  It is invoked each time through the loop because it
 * polls for activity.
 ********************************************************************************************************/

void NewService(uint32_t (*serviceFunction)(struct serviceBlock*)){
    serviceBlock* newBlock = new serviceBlock;
    newBlock->service = serviceFunction;
    AddService (newBlock);
  }

void AddService(struct serviceBlock* newBlock){
  if(newBlock->callTime < UNIXtime()) newBlock->callTime = UNIXtime();
  if(serviceQueue == NULL ||
    (newBlock->callTime < serviceQueue->callTime) ||
    (newBlock->callTime == serviceQueue->callTime && newBlock->priority < serviceQueue->priority)){
    newBlock->next = serviceQueue;
    serviceQueue = newBlock;
  }
  else {
    serviceBlock* link = serviceQueue;
    while(link->next != NULL){
      if((newBlock->callTime < link->next->callTime) ||
        (newBlock->callTime == link->next->callTime && newBlock->priority < link->next->priority)){
        break;
      }        
      link = link->next;
    } 
    newBlock->next = link->next;
    link->next = newBlock;
  }
}

/******************************************************************************************************** 
 * All of the other SERVICEs that harvest values from the main "buckets" do so for their own selfish 
 * purposes, and have no global scope to share with others. This simple service maintains periodic
 * values for each of the buckets in a global set of buckets called statBucket.  It also is where 
 * status statistics like sample rates are maintained.  
 *******************************************************************************************************/

uint32_t statService(struct serviceBlock* _serviceBlock) { 
  static uint32_t timeThen = millis();        
  static boolean started = false;
  static float damping = .5;
  uint32_t timeNow = millis();

  if(!started){
    msgLog("statService: started.");
    started = true;
    for(int i=0; i<maxInputs; i++){
      statBucket[i].accum1 = inputChannel[i]->dataBucket.accum1;
      statBucket[i].accum2 = inputChannel[i]->dataBucket.accum2;
    }
    return (uint32_t)UNIXtime() + 1;
  }
  
  double elapsedHrs = double((uint32_t)(timeNow - timeThen)) / MS_PER_HOUR;
  for(int i=0; i<maxInputs; i++){
    inputChannel[i]->ageBuckets(timeNow); 
    statBucket[i].value1 = (damping * statBucket[i].value1) + ((1.0 - damping) * (inputChannel[i]->dataBucket.accum1 - statBucket[i].accum1) / elapsedHrs);
    statBucket[i].value2 = (damping * statBucket[i].value2) + ((1.0 - damping) * (inputChannel[i]->dataBucket.accum2 - statBucket[i].accum2) / elapsedHrs);
    statBucket[i].accum1 = inputChannel[i]->dataBucket.accum1;
    statBucket[i].accum2 = inputChannel[i]->dataBucket.accum2;
  }
  
  cycleSampleRate = damping * cycleSampleRate + (1.0 - damping) * float(cycleSamples * 1000) / float((uint32_t)(timeNow - timeThen));
  cycleSamples = 0;
  timeThen = timeNow;
  
  return ((uint32_t)UNIXtime() + statServiceInterval);
}

/************************************************************************************************
 *  Program Trace Routines.
 *  
 *  This is a real handy part of the package since there is no interactive debugger.  The idea is
 *  to just drop breadcrumbs at key places so that in the event of an exception or wdt restart, we
 *  can at least get some idea where it happened.
 *  
 *  invoking trace() puts a 16 bit entry with highbyte=module and lowbyte=seq into the 
 *  RTC_USER_MEM area.  After a restart, the 32 most recent entries are logged, oldest to most rent, 
 *  using logTrace.
 *************************************************************************************************/

void trace(uint32_t module, int seq){
  static uint16_t traceSeq = 0;
  static uint32_t entry;
  entry = (module+seq) | (traceSeq++ << 16);
  WRITE_PERI_REG(RTC_USER_MEM + 96 + (traceSeq & 0x1F), entry);
}

void logTrace(void){
  uint16_t _counter = READ_PERI_REG(RTC_USER_MEM + 96) >> 16;
  int i = 1;
  while(((uint16_t)++_counter) == (READ_PERI_REG(RTC_USER_MEM + 96 + (i%32)) >> 16)) i++;
  String line = "Trace: ";
  for(int j=0; j<32; j++){
    uint32_t _entry = READ_PERI_REG(RTC_USER_MEM + 96 + ((j+i)%32)) & 0xFFFF;
    line += String(_entry) + ",";
  }
  line.remove(line.length()-1);  
  msgLog(line);
}


 

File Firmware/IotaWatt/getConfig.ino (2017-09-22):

boolean getConfig(void)
{
  DynamicJsonBuffer Json;              
  File ConfigFile;
  String ConfigFileURL = "config.txt";
    
  //************************************** Load and parse Json Config file ************************

  trace(T_CONFIG,0);
  ConfigFile = SD.open(ConfigFileURL, FILE_READ);
  if(!ConfigFile) {
    msgLog("Config file open failed.");
    return false;
  }
  hashFile(configSHA256, ConfigFile);
  int filesize = ConfigFile.size();
  trace(T_CONFIG,1);
  char* ConfigBuffer = new char[condensedJsonSize(ConfigFile)+1];
  trace(T_CONFIG,2);
  ConfigFile.seek(0);
  condenseJson(ConfigBuffer, ConfigFile);
  trace(T_CONFIG,3);
  ConfigFile.close();
  // ConfigFile = SD.open(ConfigFileURL, FILE_READ);
  JsonObject& Config = Json.parseObject(ConfigBuffer);  
  // ConfigFile.close();
  trace(T_CONFIG,4);
  if (!Config.success()) {
    msgLog("Config file parse failed.");
    delete[] ConfigBuffer;
    return false;
  }
  
  //************************************** Process Config file *********************************
    
  JsonObject& device = Config["device"].as<JsonObject&>();

  if(device.containsKey("name")){
    deviceName = device["name"].asString();
  }
  host = new char[deviceName.length()+1];
  strcpy(host,deviceName.c_str());
  
  if(Config.containsKey("timezone")){
    localTimeDiff = Config["timezone"].as<signed int>(); 
  }

  if(Config.containsKey("update")){
    updateClass = Config["update"].as<String>();
  }

  int channels = 21;
  if(device.containsKey("version")){
    deviceVersion = device["version"].as<unsigned int>();
    if(deviceVersion == 2){
      hasRTC = true;
      VrefVolts = 1.0;
      ADC_selectPin[0] = 0;
      ADC_selectPin[1] = 16;
      ADC_selectPin[2] = 2;
    }
    else if(deviceVersion == 3){
      hasRTC = true;
      VrefVolts = 2.5;
      ADC_selectPin[0] = 0;
      ADC_selectPin[1] = 2;
      channels = 15;
    }
  }
  
  if(device.containsKey("refvolts")){
    VrefVolts = device["refvolts"].as<float>();
  }  
  
          // Build or update the input channels
          
  trace(T_CONFIG,5); 
  if(device.containsKey("channels")){
    channels = MIN(device["channels"].as<unsigned int>(),MAXINPUTS);
  }
  
  if(maxInputs != channels) {
    IotaInputChannel* *newList = new IotaInputChannel*[channels];
    for(int i=0; i<MIN(channels,maxInputs); i++){
      newList[i] = inputChannel[i];
    }
    for(int i=MIN(channels,maxInputs); i<maxInputs; i++){
      delete inputChannel[i];
    }
    for(int i=MIN(channels,maxInputs); i<channels; i++){
      newList[i] = new IotaInputChannel(i);
      newList[i]->_name = "Input(" + String(i) + ")";
    }
    delete[] inputChannel;
    inputChannel = newList;
    maxInputs = channels;
  }

        // Override V3 defaults if V2 device

  if(deviceVersion == 2){
    for(int i=0; i<MIN(maxInputs,device["chanaddr"].size()); i++){
      inputChannel[i]->_addr = int(i / 7) * 8 + i % 7;
      inputChannel[i]->_aRef = int(i / 7) * 8 + 7;
    }
  }

        // Override all defaults with user specification
 
  if(device.containsKey("chanaddr")){
    for(int i=0; i<MIN(maxInputs,device["chanaddr"].size()); i++){
      inputChannel[i]->_addr = device["chanaddr"][i].as<unsigned int>();
    }
  }
  
  if(device.containsKey("chanaref")){
    for(int i=0; i<MIN(maxInputs,device["chanaddr"].size()); i++){
      inputChannel[i]->_aRef = device["chanaref"][i].as<unsigned int>();
    }
  }
 

   if(device.containsKey("burden")){
    for(int i=0; i<MIN(maxInputs,device["burden"].size()); i++){
      inputChannel[i]->_burden = device["burden"][i].as<float>();
    }
  }
    
        //************************************ Configure input channels ***************************

  trace(T_CONFIG,6);      
  if(Config.containsKey("inputs")){
    configInputs(Config["inputs"]);
  }   
     
        // ************************************ configure output channels *************************

  trace(T_CONFIG,7);
  delete outputs;
  JsonVariant var = Config["outputs"];
  if(var.success()){
    outputs = new ScriptSet(var.as<JsonArray>()); 
  }
      
        // Get server type
                                                  
  String serverType = Config["server"]["type"].as<String>();
  serverType.toLowerCase();
  
      // ************************************** configure EmonCMS **********************************
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

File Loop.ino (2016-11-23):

void loop()
{
  millis_now = millis();
  if(((unsigned long)(millis_now - last_post_time)) >= post_interval_ms)
  {
    post_time = last_post_time + post_interval_ms;
    sample_interval = post_time - last_sample_time;
    for(int i=1; i <= channels; i++) 
    {
      averageWatts[i] = (watt_ms[i] + activePower[i] * sample_interval) / post_interval_ms;
      if(averageWatts[i] < 0.0) averageWatts[i] = -averageWatts[i];
      if(averageWatts[i] < 1.0) averageWatts[i] = 0.0;
      watt_ms[i] = 0;
      
      averageVA[i] = (VA_ms[i] + apparentPower[i] * sample_interval) / post_interval_ms;
      if(averageVA[i] < 1.0) averageVA[i] = 0.0;
      VA_ms[i] = 0;
    }
    post_power();
    last_sample_time = post_time;
    last_post_time = post_time;
  }
  else
  {
    sample_interval = millis_now - last_sample_time;
    for(int i=1; i <= channels; i++) 
    {
      watt_ms[i] += activePower[i] * sample_interval;
      VA_ms[i] += apparentPower[i] * sample_interval;
    }
    last_sample_time = millis_now;
  }

  sample_power();
  yield();

  if(reply_pending) checkdata();  
  yield();

}

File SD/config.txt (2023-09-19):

{
	"format": 2,
	"timezone": 0,
	"update": "MINOR",
	"device": {
		"name": "IotaWatt",
		"version": 3,
		"channels": "15",
		"burden": [
			0,
			20,
			20,
			20,
			20,
			20,
			20,
			20,
			20,
			20,
			20,
			20,
			20,
			20,
			20
		]
	},
	"inputs": [
		{
			"channel": 0,
			"name": "Input_0",
			"type": "VT",
			"model": "Jameco/112336",
			"cal": 11.43,
			"phase": 0.6
		},
		null,
		null,
		null,
		null,
		null,
		null,
		null,
		null,
		null,
		null,
		null,
		null,
		null,
		null
	],
	"outputs": []
}

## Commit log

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2017-01-19 Github newbie making stupid mistakes
    [Loop.ino, Setup.ino, dataLog.ino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]
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2017-01-28 Fix connection
    [IotaWatt.brd]
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2017-02-04 Added Real Time Clock
    Adafruit feather with PCF8523. Conflict with older IotaWatt versions
    using pin 4 for MCP23S17. Need to resolve to run on that platform.
    [Setup.ino, msgLog.ino, timeServices.ino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]
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2017-02-05 Not resetting after successful retry.
    [eMonService.ino]
2017-02-07 Misc fixes and comments
    Deploy WDT_FEED() to try to stop hardware wtd resets. Catch up changes
    to iotaLog class for GetFeedData performance, provide for terminating
    SERVICEs.
    [GetFeedData.ino, Setup.ino, timeServices.ino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]
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2017-02-09 Rework and simplify voltage calibration
    Add code to directly sample only voltage and return vrms based on a
    supplied calibration factor.
    Add a web server handler to handle handle requests to sense voltage
    using the given calibration factor.
    Modify the calibration functions in the configuration utility to use the
    above code.
    Rename and move the graph.htm and edit.htm apps to the SD root.
    [Setup.ino, webServer.ino]
2017-02-10 Performance enhancement for local data API, bug fix
    Decrease response time in feed/data API by first trying direct read
    rather than keyed read. High % hits in well populated log file.
    Fix problem with search in readKey.
    [GetFeedData.ino]
2017-02-16 Improve performance of API
    Various tweaks to lower API response time from about 7-8 seconds to
    about 4. Doesn't get much better without changes on the other end.
    [GetFeedData.ino, Loop.ino, Setup.ino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]
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2017-03-06 Clean up samplePower
    Clean up samplePower, fix some loose ends, squeeze a couple more samples
    per cycle out of the loop, and go over comments.
    [Loop.ino, webServer.ino]
2017-03-09 Recognize shortcut /edit and /graph in web server
    Append .htm to /edit and /graph uri
    [dataLog.ino, webServer.ino]
2017-03-13 Require WiFi connect at startup
    Temporary restriction to avoid dealing with timeout.
    [Setup.ino]
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2017-03-18 Use arduinoJson to build server responses
    Use arduinoJson to build server responses. Much cleaner than String
    building and much more readable.
    Also increased delay after connect failure in eMonCMS to minimize
    effects of blocking during failed connects.
    [eMonService.ino, getConfig.ino, msgLog.ino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]
2017-03-18 Fix a few things, add buttons for edit and graph
    Added more functions. This app needs a makeover, but it's working OK
    for now.
2017-03-18 Fix rounding in API Json response
    Float number with no decimals were converted to exp notation (1783.0 =
    2e3 = 2000). Convert to long.
    [webServer.ino]
2017-03-18 Fix type in Json rework
    [webServer.ino]
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2017-04-14 Revert 2.0 - had 2.1 changes
    2.0 was corrupted with 2.1 changes. Reverted to pre 2.1 status.
    [GetFeedData.ino, Loop.ino, Setup.ino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]
2017-04-16 Fix rounding in stats API
    [webServer.ino]
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2017-05-15 Setup led blink messages for startup failures
    Three blink sequence with red/green led.
    red-red-green - SD initialization failed
    red-red-red - config file missing or invalid
    [Setup.ino]
2017-05-23 Various updates to WiFiManager use and changes to Timer Svcs
    Attempt to make WiFiManager more predictable and responsive, especially
    with IOS devices. Resolved to allow WiFi network change only at startup
    and only if previous network is unavailable. Will add switching with
    browser app in the future.
    Add WiFi Service to monitor connection status and log it.
    Alter eMonService to suspend updating while WiFi is not connected to
    eliminate long blocking failed connects during WiFi outage.
    Change timer services to run when clock not set but logging is
    suppressed. (Only real time status is available). Will sync clock when
    WiFi is available for NTP update. ToDo: Have app set time on locally
    conn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
    [Setup.ino, dataLog.ino, eMonService.ino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]
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2017-05-29 Add automatic update, rework WiFi Manager use
    Added new service updater that periodically checks in with iotawatt.com
    php application for new updates. Will automatically download and reboot
    with new firmware when available.
    Made some slight changes to WiFiManager usage to try to make changing
    the WiFi SSID more useable. Still not great but probably OK given that
    it is rarely done.
    [Loop.ino, Setup.ino]
2017-06-07 Set RTC crystal capacitance
    Default RTC crystal capacitance is wrong. Set alternate 12.5pF bit and
    clock gets a lot more accurate.
    [timeServices.ino]
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2017-06-23 Reduce memory needed to process Json config file
    Can't JsonParse large config file for dynamic configuration. Removing
    all spaces, tabs etc provides some relief. ESP32 will solve the
    problem.
    [getConfig.ino, webServer.ino]
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2017-07-15 Fix sample power, enhance graph
    Fix problem with sampling suspended sometimes after connect/disconnect
    CT. Vulnerability was exposed by Op-Amp bias change.
    Enhance performance of graph function:
    * Change feed/data api to allow requesting multiple channels in single
    request.
    * Remove time from response array. >60% of the response data and easily
    generated by requesting app.
    * Change graph.htm to add new variable expected by graph.js.
    * Add graph.js to SD and change graph.htm to fetch it from there instead
    of emoncms.org.
    * Change graph.js to use modified API and request all feeds in a single
    request.
    * Miscelaneous changes to support async feed/data request.
    * Limit feed/data requests to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
    [GetFeedData.ino, webServer.ino]
2017-07-15 Revert "Fix sample power, enhance graph"
    This reverts commit 7f102a5e30f4337960be4ecd5272cbfd06e771f2.
    [GetFeedData.ino, webServer.ino]
2017-07-15 Revert "Revert "Fix sample power, enhance graph""
    This reverts commit af7c2f20286cbdfe782e1c9903a37a0d63b3efcb.
    [GetFeedData.ino, webServer.ino]
2017-07-18 Sample power tune-up
    Fix problems detecting no VT connected.
    Narrow range for offsets to .5%
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2017-07-19 Convert to more efficient script notation
    Old script notation (Json) was too verbose. Became a memory issue in
    dynamic configuration. This reduces size of script by a factor of 10
    and encodes more easily as well.
    [getConfig.ino]
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2017-07-23 Overhaul RTC initialization and power fail detection
    With version 4 (prototype) hardware prior to 4.3, the RTC battery backup
    worked intermittently (more often not). Required addition of resistor
    to slow the voltage drop to the RTC on power fail. As part of the
    hardware fix, code was added to read the RTC power fail indicator, log
    it, and reset.
    [Setup.ino, timeServices.ino]
2017-07-24 Add LED problem indicators during startup
    Various LED blink patterns for problems during startup
    [Setup.ino, webServer.ino]
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2017-07-27 Accept script in new format (and old)
    New compact script format in anticipation of more widespread use. Old
    format consumed too much memory when reading and parsing the json config
    file.
    [getConfig.ino]
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2017-08-12 Filter ADC lsb noise
    Some ADCs produce low frequency noise readings of 1 ADC count, which is
    below the threshold of accuracy. Filter out readings of +/-1.
2017-08-16 Fix problem changing Emoncms on the fly
    GET and POST encrypted have different methods of specifying time. They
    were being mixed when changing on the fly.
    [eMonService.ino, getConfig.ino, webServer.ino]
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2017-09-08 Fixes to actually be C++ files not .ino
    [GetFeedData.ino, IotaWatt.h, Setup.cpp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]
2017-09-12 Convert to new script class
    New script class (ScriptSet and Script) is a general use scripting
    feature that replaces outputchannels and can be used implement the same
    functionality for server Services like Emoncms and influxDB.
    [GetFeedData.ino, getConfig.ino, webServer.ino]
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2017-09-18 encrypted Emoncms, influxDB
    encrypted Emoncms post protocol
    Output specification in Emoncms
    add influxDB
    fix invalid header on update
    add sct006 to tables
    new body context for app
    [Setup.ino, eMonService.ino, getConfig.ino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]
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2017-09-20 Fix message and timeout
    [influxDB.ino]
2017-09-21 Fix excetion on save config empty scriptset.
    [getConfig.ino]
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2017-09-24 Fix get/feed/data, allow large phase spec
    [GetFeedData.ino, Setup.ino, webServer.ino]
2017-09-28 Fixed up to build again
    [GetFeedData.ino, IotaWatt.h, Setup.cpp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]
2017-09-28 Fixed Travis CI/Linux build
    [IotaLog.cpp]
2017-10-02 fix pio compile errors
    [IotaLog.cpp, IotaWatt.h]
2017-10-03 Fix memory leak in getConfig
    delete[] the buffer.
    [getConfig.cpp]
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2017-10-16 fix space in config filename
    [config .txt]
2017-10-16 restore missing config file
    [config.txt]
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2017-10-28 replace old logfile, new untested
    [IotaLog.cpp]
2017-10-28 Bump version to 02_02_23
    This version fixes problems encountered with using new esp/arduino
    staged core. The most significant was random zero voltage sampling
    suspected to have been caused by low level interruption of the sample
    process. Fixed with check for reasonable number of samples after
    sampling and improved voltage sampling by using the common sampleCycle
    routine.
    [IotaWatt.h]
2017-11-02 Enhance retry logic, make base64encode more efficient
    These changes reflect ongoing work to diagnose problems with "timeouts"
    posting to Emoncms. Don't log single retried errors.
    Modify base64encode to use memory mnore efficiently by building output
    directly in a buffer rather than adding to a String.
    [getConfig.cpp]
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2017-11-08 Polish up code, fix boundary, reduce memory
    [IotaLog.cpp]
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2018-01-22 Improve phase correction
    With new techniques, able to break shift down into components,
    reconcile, correct, and calibrate. Results are very repeatable and
    accurate.
    [IotaWatt.h, getConfig.cpp]
2018-01-23 Get phase from tables at startup
    Get phase corection from tables if model is in the tables file. This
    paves the way for correction as a function of current (or voltage) and
    makes improved phase correction work without editing config file.
    [IotaWatt.h, getConfig.cpp]
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2018-02-20 Update to latest version 4.8
    Remove extra LED mounting position
    Reroute traces around SDcard to eliminate mfg problems
    [IotaWatt4.8.brd, IotaWatt4.8.sch]
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2018-03-01 Fix issue with no graph with long names
    The homegrown chunking was no longer compatible with webserver. The
    native chunking now seems to work fine with IOS, so went with that.
    [IotaWatt.h]
2018-03-02 More dynamic memory
    Dynamic asyncHTTPrequest in EmonService
    Dynamic reqData String in EmonService
    Fix length in charstar routine.
    [getConfig.cpp]
2018-03-02 Improve reversed algorithm
    Improve how "reversed" is determined
    Minimum status power 2 watts
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2018-03-02 Low blocking NTP time update
    Restructure NTP time request to be mostly asynchronous. Blocks only to
    resolve domain to IP.
    Change to use pool.ntp.org for better global response.
    [IotaWatt.h]
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2018-03-21 Emonservice use xbuf, reduce memory use
    Convert Emonservice to build post in an xbuf.
    Rework the encryption and base64 steps to use xbuf so reduced memory
    requirements.
    This also fixes posting problems with secure post.
    [getConfig.cpp]
2018-03-21 influxDB auth, make trace inline
    add influxDB authorization header.
    rework trace to be inline function and more id's per module
    [IotaWatt.h]
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2018-03-30 release punchlist
    Fix memory leak in getConfig
    Fix getFeedData energy from script
    Make servers post all bulk data at once.
    [getConfig.cpp]
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2018-04-14 More changes to influxDB support
    Changes to influxDB:
    * Add variables to allow custom line-protocol entries.
    * "double buffer" async requests - rework flow logic
    * Add retention policy specification
    * Move stop logic to a cleaner place
    * Impliment start/stop
    * Maintain last post status for display
    * Add begin date for history upload
    Fix bug reporting Amps from scripts
    Subject UDP in getNPTtime to HTTP request limit semaphore (TCP)
    Add influxDB status tab with start/stop button
    [IotaWatt.h]
2018-04-26 Upgrade to core 2.4.1 and lwip 2
    Latest core release
    lwip 2 solves problems with VPN access
    lwip 2 introduces transient memory leak - mitigated with delays - fix
    coming from me-no-dev
    Fix trace display
    Fix problem in statservice with 2.4.1
    [Setup.cpp]
2018-05-04 2.4.1 core. New message log subsystem
    New messageLog class derived from Print. log macro invokes printf_P to
    generate message using PGM_P format strings.
    Free Heap now in the 25K range.
    New core updates to lwip 2. This seems to work better in many respects
    but has temporary memory leak during history upload. Fix is
    forthcoming, but now code pauses when heap below 15K until timeout frees
    memory.
    [IotaWatt.h, Setup.cpp, getConfig.cpp]
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2018-06-08 Shorten WiFi disconnect restart
    [auth.cpp]
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2018-06-13 Attempt to repair damaged datalog
    Most frequent problem with datalog is corrupted last record. If so,
    just make null records for last two and try to move on.
    [IotaLog.cpp]
2018-06-19 Fix issue #165, allow neg power value change needs reboot
    [getConfig.cpp]
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2018-06-19 Various changes to improve error handling
    [updater.cpp]
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2018-07-09 Clean up old auth requests quickly
    IOS/Safari doesn't seem to send digest auth with each request
    automatically. So IoTaWatt generates a new nonce and auth request for
    each transaction that is only used once. This cleans them up quickly.
    [auth.cpp]
2018-07-10 Accept config sha256 in header
    configSHA256 is used to guard against updating config with a stale copy.
    Was passing as an argument in uri but that broke authorization??. So
    moved to header which is better anyway.
    [Setup.cpp, auth.cpp]
2018-07-11 Lock during release download to SDcard
    Writing to SD in async handler causes problems. Stay in updater until
    transfer complete and written to SD. Can revisit if better flow control
    in asyncHTTPrequest.
    [updater.cpp]
2018-07-15 Modify error handling
    Differentiate between communication errors and invalid request (403).
    [updater.cpp]
2018-07-15 Reduce memory footprint and throttle response vs. sampling
    Fix small memory leak. Release more memory when inactive. Reinstate
    throttling based on call frequency.
2018-07-16 Add ability to monitor heap via influx
    This is a diagnostic feature for development. Reserve the right to
    remove it when no longer needed.
    [IotaWatt.h]
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2018-07-24 Remove TIME_WAIT bandaid
    Works fine with staging core that has me-no-dev's fix. Commented out in
    case need to use with pre-fix release.
2018-07-31 Remediate incompatibility with older versions
    New vesion required password status to build Device menu. Now only uses
    it to restrict changing name present.
2018-08-02 Fix [inf] with [null]
    Can happen in rare cases when returning Amps and voltage is zero.
2018-08-02 Limit low sample retries to 3
    Problem with hanging in retry loop.
2018-08-08 Fix hang with no inputs configured
    [IotaWatt.h, getConfig.cpp]
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2018-08-28 Add Reverse and Double input options
    These options facilitate installation and troubleshooting.
    Reverse will efectively reverse the input from a CT just as physically
    reversing it would do.
    Double will double the power value as if the voltage were doubled.
    [getConfig.cpp]
2018-08-29 Move reverse into SampleCycle
    Putting this lower down is cleaner and simpler
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2018-09-19 Segregated SPIFFS access routines
    SPIFFS and SD don't get along very well, and since SD is deeply
    ingrained in the code, these SPIFFS access routines localize the SPIFFS
    FS scope and avoid conflict. They also provide a layer of transparency
    that allows emulating most of the characteristics of the FAT file
    system.
    [spiffs.cpp]
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2018-09-22 Don't log skipped file install
    [updater.cpp]
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2018-10-08 Change LED codes for config problems
    [IotaWatt.h]
2018-10-20 Shorten responder log messages
    [Setup.cpp]
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2018-10-21 Fix and improve log diagnostics
    [IotaLog.cpp]
2018-10-27 Clean up error restart
    No gaps for I/O errors, but on server rejection (200 not ok) advance one
    frame every 10 consecutive errors.
    [Setup.cpp]
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2018-12-08 Use WiFi Manager only after power cycle.
    This eliminates blocking after program restarts and gets things going
    right away.
    BTW/ eliminated display of trace after power fail.
    [IotaWatt.h, Setup.cpp]
2018-12-09 Add ECS24300, ECS24400 and some 50Hz phase
    Getting ready for 50Hz phase correction.
    Change some VT calibrations with new samples.
    Add high current ECS24 series CTs
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2019-03-05 Enhanced phase correction
    Add frequency, voltage and current specific phase correction capability.
    Add above corrections to device tables.
    Remove scalar correction display in configuration.
    [IotaWatt.h, Setup.cpp, getConfig.cpp]
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2019-04-28 rename IotaWatt.cpp to common.cpp
    Github seems to have a problem putting IotaWatt.cpp in the IotaWatt directory
    [common.cpp]
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2019-06-25 Fix low measurements on startup
    [IotaWatt.h, common.cpp]
2019-06-26 Update graph.htm to be protocol independent
    This change should allow nginx with HTTPS infront of iotawatt to work properly. Currently we get mixed content errors for files fetched based on this path configuration.
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2019-07-25 Startup minimal services when config missing or damaged
    Previously, just halted for this condition. Now unit starts with bad config LED indication and message in configuration app. User can upload a config file or repair and/or repair existing config with file manager/editor.
    [IotaWatt.h, Setup.cpp, common.cpp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]
2019-07-27 Retry on unrecognized errors
    [PVoutput.h]
2019-08-14 Add ability to upload and instyall software release
    With this feature, a valid signed release file can be uploaded to the IoTaWatt SDcard and then a command issued to install it. The file is checked for valid signature just as with the auto-update download.
    [updater.cpp]
2019-08-21 Bump version to 02_04_02
    Update didn't make into original release. This is all that changed, so will remake release with these changes. Object had changes.
    [IotaWatt.h, common.cpp]
2019-08-30 fixed case sensitivity for compiling with linux
    [IotaWatt.h, spiffs.cpp]
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2019-10-13 Fix issues with latest-stable core (though not using - WiFi issue)
    Fixed various issues with compiling using PIO and "latest-stable". Still an issue
    with F() macro, and WiFi doesn't seem to work. But these changes are benign in that they don't really change any functionality. Just getting them into the source to reduce changes down the road.
    [IotaLog.cpp, IotaWatt.h, PVoutput.h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]
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2020-01-20 Log updater error text
    [updater.cpp]
2020-01-20 Check updates using versions.json
    Previously requested current version from php file. Required every transaction to hit server. Load increasing. Now read static json file that maps update class to release. versions.json is cached worldwide by cloudflare. Should also reduce timeouts and connect issues when checking version.
    [common.cpp, updater.cpp]
2020-01-21 Fix and improve auth, make user pwd work
    [auth.cpp]
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2020-02-07 Issue WiFi.reconnect at startup
    With this core, WiFi doesn't seem to connect automatically. Issuing WiFi.reconnect seems to force that.
    [Setup.cpp]
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2020-02-12 Reduce heap requirement to process config
    The process to set dynamic phase correction arrays for inputs was consuming an astonishing 16K when processing the congfig file. Not a problem at startup but done everytimer a configuration change is made while running. Was causing unexplained failures due to heap allocation failure. New process does not Json parse table file, but works directly on file. Extra savings on using same arrays for like models.
    [IotaWatt.h, common.cpp, getConfig.cpp]
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2020-02-12 Bump version to 02_05_04
    New core 2.6.3
    Fix influx (and Emoncms) URL handling
    Fix large heap demand to process config (phase tables)
    [IotaWatt.h, common.cpp]
2020-02-27 Drop priority below current log
    Minor issue on startup where histlog goes to sleep for a minute because currlog not started yet. Drop priority and return to allow currlog to dominate.
2020-02-27 createDir works different with new core - fix issue
    Unable to create datalog because dirCreate now fails if directory already exists.
    [IotaLog.cpp]
2020-02-27 version 02_05_05
    Fixes bug unable to create datalog
    [IotaWatt.h, common.cpp]
2020-03-10 Restart after power-fail no AP connect.
    WiFimanager leaves WiFi in state where it will not autoconnect if WiFi becomes available. Restart after running WiFimanager to allow autoconnecvt when if or when WiFi is available.
    [Setup.cpp]
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2020-03-27 Use legacy mDNS
    2.6 core introduced a new implimentation of mDNS using a DNS-SD class. It doesn't seem to work, sometimes failing the begin() method, and when succeeding, doesn't seem to work.
    [IotaWatt.h, Setup.cpp, common.cpp]
2020-03-28 Allow for varying log record size
    Record size was fixed at 256. Now length is specified when the log is instantiated.
    [IotaLog.cpp, common.cpp]
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2020-04-02 Version 02_05_07
    Fixes problem with https:// Emoncms url that was introduced by changes to asyncHTTPrequest after release 02_05_02.
    [IotaWatt.h, common.cpp]
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2020-04-30 Go through normal wait after failed download
    Stop repeated downloads
    [updater.cpp]
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2020-05-01 Various improvements
    Fix exception if .bin file not found (or other downl;oad error)
    Auto create download directory
    Keep all downloaded releases in download directory.
    [updater.cpp]
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2020-06-05 Fixed a console error raised within graph2 when de-selecting a saved graph
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2021-03-05 Fix masterPhaseTable to recognize duplicates
    [setConfig.cpp]
2021-03-07 Reset SDspi speed to 25Mhz
    Seems fine with older cards at 40Mhz, but too much risk releasing at that speed.
    [Setup.cpp]
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2021-03-18 Version 02_06_01
    Fix "server" restart issue.
    Init bucket, token, orgID influx2
    Fix tag=$name or $units
    [IotaWatt.h, common.cpp]
2021-03-20 Update default config
    Set burdens to 20, remove "server" none, Set default VT to Jameco L6
    [config.txt]
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2021-05-29 Fix issue with "doubled" inputs reporting x2 Amps
    Datalog Amps (VA) is correct, only reporting via Script is incorrect.
    [setConfig.cpp]
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2021-09-08 Integrator (phase 1)
    Add integrator, runs from config. Works in Query, Script. Reworked Script.run to eliminate elapsedHours - gets it from old/new recs.
    Still needs UI work and performance caches etc.
    [IotaLog.cpp, IotaWatt.h]
2021-09-25 Revert device name message
    [Setup.cpp]
2021-10-05 Correct version numbers in notes
    [common.cpp]
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2021-12-16 Fix various Script problems
    Hz not reported correctly.
    Volts and Amps not correct in doubled or phase-phase in derived reference.
    Second and subsequent integrations returning zero.
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2022-03-25 Discontinue use of Legacy mDNS
    Problems associated with KASA App causing crashes.
    [IotaWatt.h]
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2022-12-19 Fix resume from rate-limit pause
    [PVoutput.h]
2022-12-19 Slow down SPI if SDcard init fails
    [Setup.cpp]
2022-12-20 Version 02_08_01
    Interim version with core 2.4.0 to mitigate SD card issues
    [IotaWatt.h, common.cpp]
2023-01-25 Version 02_08_02
    Fix mDNS when AP changes
    [IotaWatt.h, common.cpp]
2023-05-01 Fix config version check on save
    When saving a config, send hash of basis config to insure updating current config, i.e. no other updates since basis copy was taken.
2023-09-19 Modify default config
    VT Jameco 112336
    [config.txt]
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

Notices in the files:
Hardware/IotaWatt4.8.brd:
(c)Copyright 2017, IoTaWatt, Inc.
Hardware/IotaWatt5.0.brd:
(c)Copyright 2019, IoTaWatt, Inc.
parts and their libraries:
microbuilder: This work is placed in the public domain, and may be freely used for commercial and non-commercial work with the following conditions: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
